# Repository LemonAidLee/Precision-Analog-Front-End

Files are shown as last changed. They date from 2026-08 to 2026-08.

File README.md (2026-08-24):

# Precision Mixed-Signal Data Acquisition Front End (AFE)

A four-stage precision analog front end that conditions a ±100 mV bipolar sensor signal into the 0–3.3 V unipolar window of a 16-bit ADS1115 ADC, designed for an ESP32-WROOM-32 host. Designed, simulated in LTspice, and laid out in KiCad. **Not built — no physical hardware exists.**

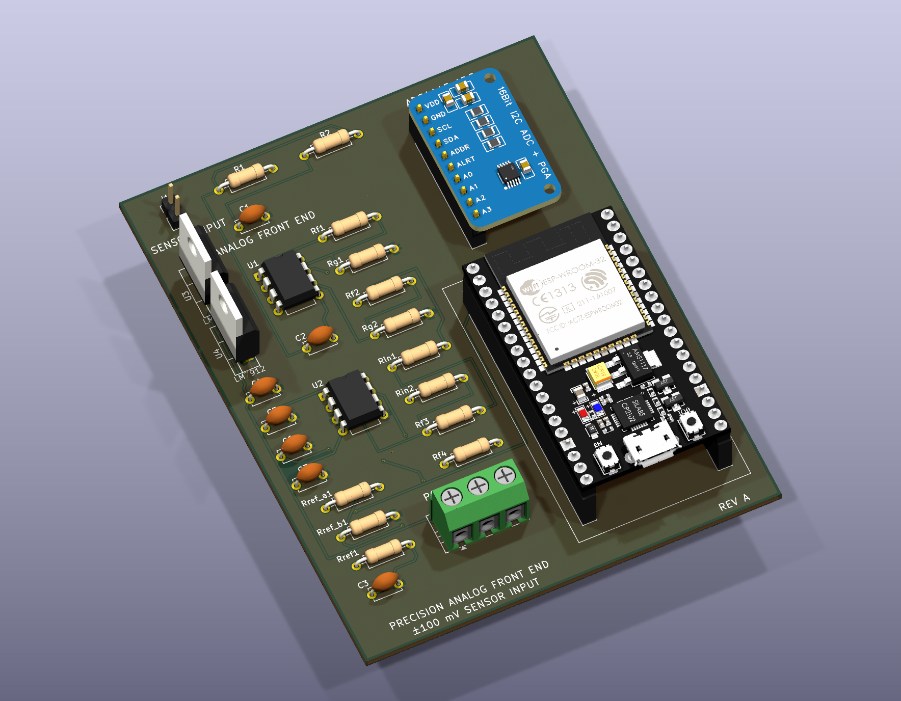
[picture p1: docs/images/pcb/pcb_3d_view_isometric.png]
PCB 3D render, top view


*Rev A board (78 mm × 100 mm, 2-layer), KiCad 3D render. The physical board has not been manufactured.*

---

## Overview

A sensor that outputs a few tens of millivolts, swinging both positive and negative, cannot be connected to a single-supply ADC. It is too small to use the converter's resolution, it goes below the converter's ground rail, and it carries out-of-band content the converter will alias.

This project is the hardware that sits between the two: an analog front end that band-limits, amplifies, and re-centres the signal so that a 16-bit ADC sees a well-conditioned, in-range voltage, and an ESP32 can read it over I²C.

| | |
|---|---|
| **Input** | ±100 mV bipolar, single-ended (J1) |
| **Output** | 0.31 V … 2.96 V unipolar, centred on VREF (to ADS1115 A0) |
| **Overall gain** | 13.25 V/V (22.4 dB) |
| **Bandwidth** | 2nd-order Butterworth low-pass, f₀ = 1.06 kHz |
| **Analog supply** | ±15 V (unregulated), external via screw terminal (J2); regulated on-board to ±12 V by LM7812 / LM7912 |
| **Digital supply** | 3.3 V from the ESP32 module's on-board regulator |
| **Op-amps** | 2 × TL082 (dual JFET-input), DIP-8 |
| **ADC** | ADS1115 breakout, 16-bit, I²C, ±4.096 V FSR |
| **Board** | 78 mm × 100 mm, 2-layer, 1.6 mm, all through-hole |
| **Status** | Designed · Simulated (DC) · Schematic complete · PCB fully routed with GND pour |

---

## Engineering motivation

Connecting a low-level sensor directly to a microcontroller ADC fails for four independent reasons, and each one needs its own circuit stage:

| Problem | Consequence | Stage that solves it |
|---|---|---|
| Signal is out-of-band above ~1 kHz | High-frequency interference folds back into the measurement band | Stage 1 — Sallen-Key low-pass |
| Signal is ~100 mV into a 4.096 V converter span | Only ~2.4 % of the ADC range is used; quantisation noise dominates | Stage 2 — ×10 gain |
| Signal is bipolar; the ADC ground rail is 0 V | Negative half-cycles are clipped or damage the input | Stage 3 — inverting summing level shift onto VREF |
| The summing stage inverts the signal | Polarity is wrong at the ADC | Stage 4 — unity-gain inverter |

Doing all four in one stage is possible but couples the design decisions together — the gain would set the filter Q, the offset would move with gain, and nothing could be probed independently. Splitting them keeps every design equation independent and gives four testable nodes.

---

## Signal flow

```
                 ±100 mV                  ±159 mV               ±1.59 V
   SENSOR ──▶ ┌───────────┐  VFILTER  ┌───────────┐  VAMP  ┌──────────────┐
   J1         │  STAGE 1  │ ────────▶ │  STAGE 2  │ ─────▶ │   STAGE 3    │
              │ Sallen-Key│           │ Non-inv.  │        │  Inverting   │
              │  LPF ×1.59│           │  amp ×10  │        │  summer      │
              │  U1A      │           │  U1B      │        │  U2A         │
              └───────────┘           └───────────┘        └──────┬───────┘
                                                                  │ VX
                        +3.3 V                                    │ −2.96 … −0.31 V
                          │                                       ▼
                     ┌────┴────┐  VREF = 1.637 V           ┌──────────────┐
                     │ 470/470 │ ─────────────────────────▶│   STAGE 4    │
                     │ divider │                           │ Unity inv.   │
                     │ + 100 nF│                           │  U2B         │
                     └─────────┘                           └──────┬───────┘
                                                                  │ VADC
                                                                  │ 0.31 … 2.96 V
                                                                  ▼
                                                        ┌────────────────────┐
                                                        │ ADS1115  (A0)      │
                                                        │ 16-bit, ±4.096 V   │
                                                        └─────────┬──────────┘
                                                                  │ I²C (SDA/SCL)
                                                                  ▼
                                                        ┌────────────────────┐
                                                        │ ESP32-WROOM-32     │
                                                        └────────────────────┘
```

Full node-by-node breakdown: **[03 — Signal Path](docs/03_Signal_Path.md)**

---

## Key specifications

| Parameter | Design value | Source |
|---|---|---|
| Input range | ±100 mV | Design target (silkscreened on board) |
| Stage 1 passband gain, K | 1 + 5.9k/10k = **1.590** | Calculated, LTspice-confirmed |
| Stage 1 cutoff, f₀ | 1/(2π·1.5k·100n) = **1061 Hz** | Calculated |
| Stage 1 Q | 1/(3 − K) = **0.709** (Butterworth ≈ 0.707) | Calculated |
| Stage 2 gain | 1 + 90k/10k = **10.00** | Calculated, LTspice-confirmed |
| Stage 3 signal gain | −30k/36k = **−0.8333** | Calculated, LTspice-confirmed |
| Stage 3 reference gain | −30k/30k = **−1.000** | Calculated |
| Stage 4 gain | −10k/10k = **−1.000** | Calculated |
| **Total gain, VSENSOR → VADC** | **13.25 V/V** | LTspice: 13.248 V/V |
| VREF (unloaded) | 3.3 × 470/940 = **1.650 V** | Calculated |
| VREF (loaded by Rref1) | **1.637 V** | LTspice: 1.6372 V |
| VADC at −100 mV / 0 / +100 mV | 0.313 / 1.637 / 2.962 V | LTspice (TL082) |
| ADC resolution referred to input | 4.096 V / 2¹⁵ / 13.25 = **9.4 µV/LSB** | Calculated |

---

## Hardware architecture

**Analog section** (left half of the board) — two TL082 dual op-amps in DIP-8 provide the four amplifier stages. All resistors are 1/4 W axial through-hole on a 10.16 mm pitch, arranged in a single labelled column so every feedback network can be identified and swapped without a schematic in hand. Analog supplies enter on a 3-pin 5 mm screw terminal (+15V_RAW / GND / −15V_RAW) from an external bench supply; on-board **LM7812 / LM7912 linear regulators** (U3/U4, with C4–C7 input/output bypass) clean this to the ±12 V the op-amps actually run on. The raw rail needs headroom above 12 V for the regulators to hold regulation, which is why the connector is no longer labelled ±12 V directly.

**Digital section** (right half) — the ESP32 dev board seats in two 1×19 pin sockets and supplies 3.3 V from its own regulator; the ADS1115 breakout seats in a 1×10 socket above it. The two sections meet only at the VADC trace and the shared ground.

Details: **[07 — KiCad Schematic and PCB](docs/07_KiCad_Schematic_and_PCB.md)**

---

## Simulation

Design verification was done in LTspice in two phases.

**Phase 1 — stage development with OP1177.** Each stage was designed, simulated, and iterated on its own bench: the Sallen-Key filter (AC sweep + transient), the ×10 gain stage (AC + transient), the level shifter, and then a two-stage and finally a four-stage integration. This phase used the OP1177 model that ships with LTspice, and produced the resistor values now in the schematic.

**Phase 2 — TL082 substitution.** The physical build targets TL082, so a third-party TL082 PSpice macromodel (`TL082.lib`) was brought in and the full chain re-run against it. The DC transfer at −100 mV / 0 / +100 mV was extracted and matches the ideal transfer function to within 0.02 %.

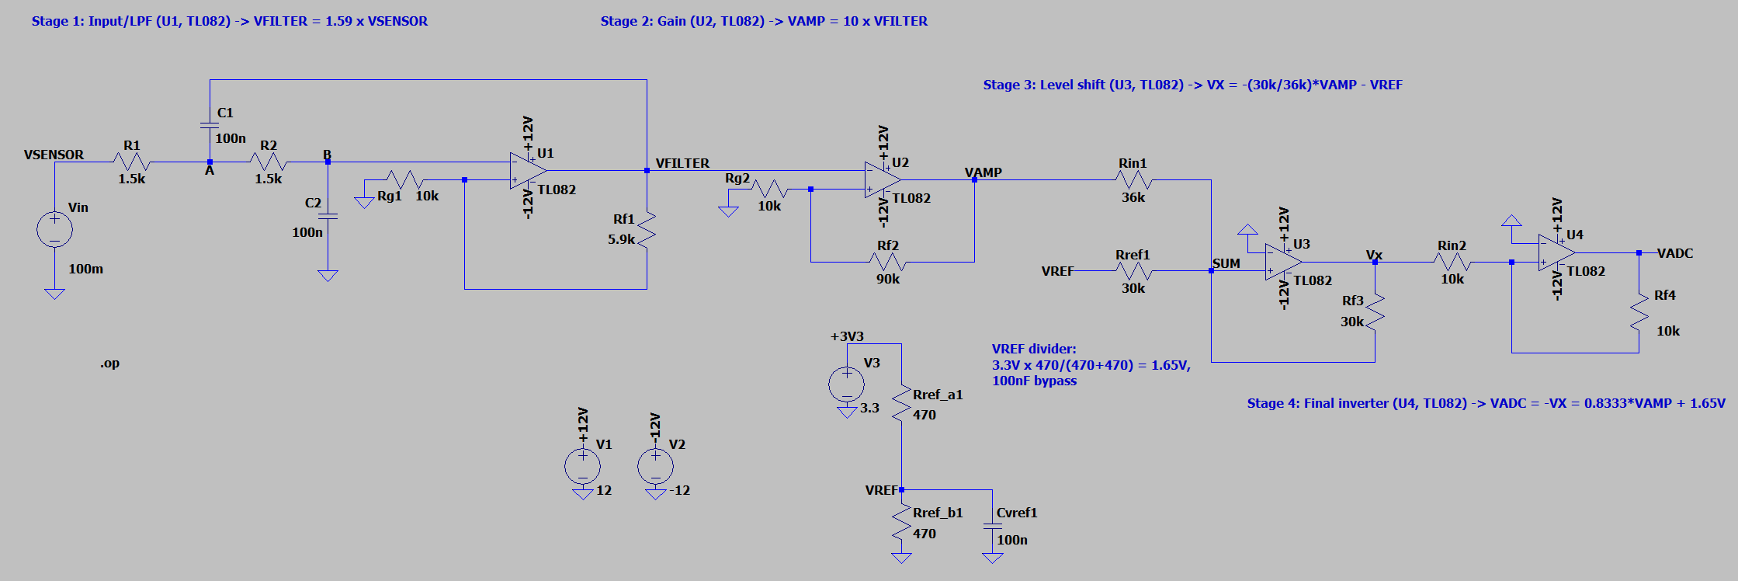
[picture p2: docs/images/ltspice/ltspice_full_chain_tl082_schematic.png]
LTspice full chain, TL082


*Four-stage chain as simulated with the TL082 macromodel.*

| Test condition | Ideal (calculated) | LTspice, TL082 | Δ |
|---|---:|---:|---:|
| VSENSOR = 0 | 1.637 V | 1.63737 V | +0.4 mV |
| VSENSOR = +100 mV | 2.962 V | 2.96220 V | +0.2 mV |
| VSENSOR = −100 mV | 0.313 V | 0.31254 V | −0.2 mV |

**Two simulation issues are open and are not hidden here:** the TL082 build's filter section is wired as a passive two-pole RC rather than the Sallen-Key that is in the KiCad schematic (DC results unaffected, AC results not representative), and the OP1177 reference file no longer runs. Both are documented in **[05 — LTspice Simulation](docs/05_LTspice_Simulation.md)**.

Full detail: **[05 — LTspice Simulation](docs/05_LTspice_Simulation.md)** · **[06 — Simulation Results](docs/06_Simulation_Results.md)**

---

## PCB design

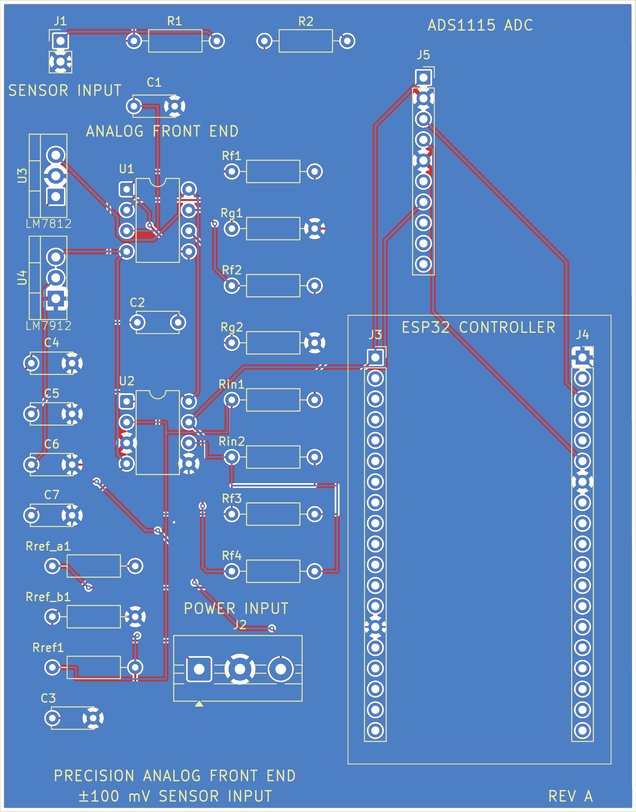
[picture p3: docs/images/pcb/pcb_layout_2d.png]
PCB layout, 2D


*F.Cu (red), B.Cu (blue — mostly the GND pour), silkscreen and board outline. Fully routed.*

- **78.1 mm × 99.6 mm** bounding box (2 layers, 1.6 mm FR4)
- 29 footprints, all through-hole; 115 pads
- 209 track segments (112 on F.Cu, 97 on B.Cu), ≈1355 mm total; 10 vias (0.6 mm / 0.3 mm drill)
- **GND poured on both F.Cu and B.Cu** (2 zones, 0.25 mm min thickness)
- Design rules: 0.2 mm min clearance, 0.2 mm min track, 0.5 mm copper-to-edge
- **DRC: 0 violations.** **ERC: 0 errors, 32 warnings** (all "label connected to only one pin" — the unused ESP32 GPIO breakout labels)
- No test points; no local decoupling at the op-amp supply pins

**Routing is complete.** Every net — including the seven internal analog nodes (the two filter nodes and the five op-amp inverting-input/feedback nodes) that an earlier netlist-sync bug had left with no copper — now has a fully routed connection, plus a GND pour on both layers. See **[07 — KiCad Schematic and PCB](docs/07_KiCad_Schematic_and_PCB.md)** for the routing table and the story of that bug.

---

## ESP32 + ADS1115 interface

The digital side is a **hardware interface only — no firmware has been written.**

| ADS1115 (J5) | Net | Goes to |
|---|---|---|
| 1 VDD | +3V3 | J3-1 (ESP32 3V3) |
| 2 GND | GND | Board ground |
| 3 SCL | SCL | J4-3 (ESP32 GPIO22) |
| 4 SDA | SDA | J4-6 (ESP32 GPIO21) |
| 5 ADDR | GND | Sets I²C address 0x48 |
| 6 ALRT | — | Not connected |
| 7 A0 | **VADC** | Stage 4 output |
| 8–10 A1–A3 | — | Not connected |

Details: **[09 — ESP32 + ADS1115 Interface](docs/09_ESP32_ADS1115_Interface.md)**

---

## Verification status

| Item | Designed | Simulated | On PCB | Routed | Physically tested |
|---|:--:|:--:|:--:|:--:|:--:|
| Sallen-Key low-pass (U1A) | ✓ | ✓ (AC/transient, OP1177 · DC only, TL082) | ✓ | ✓ | — |
| ×10 gain stage (U1B) | ✓ | ✓ (AC/transient, OP1177 · DC, TL082) | ✓ | ✓ | — |
| Level shifter (U2A) | ✓ | ✓ (DC, TL082) | ✓ | ✓ | — |
| Unity inverter (U2B) | ✓ | ✓ (DC, TL082) | ✓ | ✓ | — |
| 1.65 V reference divider | ✓ | ✓ (DC, TL082, incl. loading) | ✓ | ✓ | — |
| ADS1115 interface | ✓ | — | ✓ | ✓ | — |
| ESP32 interface | ✓ | — | ✓ | ✓ | — |
| ±12 V regulation (LM7812/LM7912) | ✓ | ideal sources only in signal-chain sims | ✓ | ✓ | — |
| Firmware | — | — | — | — | — |

**No physical prototype exists.** The board has not been fabricated, assembled, powered, or measured. Every performance figure in this repository is either a hand calculation or an LTspice result. Physical hardware validation is outside the current project scope.

---

## Engineering challenges

- **Choosing K = 1.59 rather than "gain = 1".** In an equal-component Sallen-Key, the passband gain and the pole Q are the same knob: Q = 1/(3 − K). A unity-gain buffer would give Q = 0.5 (overdamped, soft knee). K = 1.586 is the value that lands Q on 0.7071 — maximally flat. The 5.9 kΩ / 10 kΩ pair gives K = 1.590 and Q = 0.709, 0.3 % from ideal, using stock values.
- **Sizing the level shifter so the extremes stay inside the rail, not just the centre.** An earlier iteration used Rin1 = 20 kΩ. That still centred on 1.65 V at zero input, but the ±100 mV extremes landed at −0.74 V and +4.03 V — outside the ADC's supply rails in both directions. Rin1 = 36 kΩ trades gain for headroom and puts the extremes at 0.31 V / 2.96 V.
- **Predicting the reference divider's error before simulating it.** VREF is not 1.650 V in circuit; Rref1 (30 kΩ) sinks ~55 µA from a 235 Ω source, pulling it to 1.637 V. That 13 mV shift is a fixed offset the firmware can calibrate out — but it had to be identified as a systematic error rather than mistaken for simulation noise.
- **Migrating from a model that exists to a part that can be bought.** OP1177 has a vendor-supplied LTspice model; TL082 does not ship with LTspice. Getting the TL082 macromodel to converge required source stepping, and re-running the chain surfaced the fact that the two integration files had drifted apart.

---

## Current project status

**Designed · Simulated · Schematic complete · PCB placed and fully routed with a GND pour · Documented.**

Not manufactured, not assembled, not physically validated, not production-ready.

---

## Limitations

- No physical prototype; no oscilloscope, multimeter, or spectrum measurements of any kind.
- No local supply decoupling at the TL082 pins, no test points on the current board.
- ±12 V is regulated on-board (LM7812/LM7912), but the input rail is still an external, unregulated ±15 V supply — there is no AC-mains or USB-derived path to that rail.
- The TL082 full-chain simulation covers **DC only**; there is no AC or transient run against the TL082 model, and its filter section does not match the board.
- The AC and transient results in this repository were produced with **OP1177**, not the TL082 that is on the schematic.
- The 1.06 kHz filter corner sits above the ADS1115's 430 Hz Nyquist frequency at its 860 SPS maximum rate — it band-limits the signal but does not anti-alias the converter.
- No input protection, no reverse-polarity protection, no sensor characterisation.
- No firmware.

---

## Future improvements

1. Resolve the two open simulation discrepancies (filter topology in the TL082 file; repair the OP1177 reference bench).
2. Run AC and transient sweeps against the TL082 model and compare to the OP1177 reference.
3. Add 100 nF decoupling at each TL082 supply pin, and test points at VSENSOR / VFILTER / VAMP / VREF / VADC.
4. Fabricate and assemble; bring up the rails before the signal chain.
5. Measure DC transfer, frequency response, and noise floor; compare against simulation.
6. Write ESP32 firmware: I²C driver for the ADS1115, offset/gain calibration, data logging.
7. Revise to Rev B against measured data.

**Done since the last revision of this document:** PCB routing is complete (including seven internal analog nets a netlist-sync bug had silently left unrouted — see [07 §5](docs/07_KiCad_Schematic_and_PCB.md#5-resolution--the-unrouted-nets-and-the-bug-behind-them)), a GND pour was added on both copper layers, and on-board LM7812/LM7912 regulation replaced the external-±12V-only supply architecture.

---

## Repository structure

```
.
├── README.md                     ← this file
├── docs/                         ← full engineering documentation
│   ├── README.md                 ← documentation index
│   ├── 01_Project_Overview.md
│   ├── 02_System_Architecture.md
│   ├── 03_Signal_Path.md
│   ├── 04_Analog_Circuit_Design.md
│   ├── 05_LTspice_Simulation.md
│   ├── 06_Simulation_Results.md
│   ├── 07_KiCad_Schematic_and_PCB.md
│   ├── 08_Components_and_BOM.md
│   ├── 09_ESP32_ADS1115_Interface.md
│   ├── 10_Engineering_Decision.md
│   ├── Portfolio_Summary.md      ← recruiter-facing summary
│   ├── images/                   ← schematic, PCB and LTspice figures
│   └── design_files/             ← generated PDF / BOM exports + source pointers
├── KiCAD_PCB_Design/             ← KiCad 10 project (schematic, PCB, STEP)
├── LTSpice_Simulation/           ← LTspice schematics, netlists, TL082 model
└── Precision DAQ AFE_Documentation/   ← original engineering log / working notes
```

---

## Skills demonstrated

**Analog design** — active filter synthesis (Sallen-Key, Butterworth Q targeting), op-amp gain-stage design, inverting summing amplifiers, level shifting, resistive reference design with loading analysis, supply-rail headroom budgeting.

**Simulation** — LTspice AC / transient / DC-sweep analysis, third-party SPICE macromodel integration, convergence troubleshooting (Gmin and source stepping), model-substitution verification, netlist-level inspection.

**PCB design** — KiCad 10 schematic capture, footprint assignment, through-hole layout, functional block placement, analog/digital section separation, DRC/ERC.

**Mixed-signal / embedded** — external ADC selection and interfacing, I²C bus wiring, ADS1115 address strapping and PGA range selection, ESP32 dev-board integration.

**Engineering process** — requirement-driven stage decomposition, quantitative trade-off analysis, iterative design revision with superseded values preserved, honest separation of calculated / simulated / measured, self-audit of design-file consistency.

---

## Documentation

Start at **[docs/README.md](docs/README.md)** for the full index.

- **[docs/01–09](docs/README.md)** — the technical documentation: overview, architecture, signal path, circuit design, simulation, PCB, BOM, and the ESP32/ADS1115 interface.
- **[docs/10_Engineering_Decision.md](docs/10_Engineering_Decision.md)** — every significant design choice, the alternative it was taken over, and the reasoning.
- **[docs/Portfolio_Summary.md](docs/Portfolio_Summary.md)** — a short, recruiter-facing summary of the same project.

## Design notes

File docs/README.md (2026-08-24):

# Documentation Index

Engineering documentation for the **Precision Mixed-Signal Data Acquisition Front End (AFE)**.

The repository landing page is **[../README.md](../README.md)**. This index is the entry point to the detailed technical documents.

Documents **01–10** and the **[Portfolio Summary](Portfolio_Summary.md)** form the comprehensive documentation suite. They detail the system architecture, component selection, simulation verification, and PCB layout that comprise the complete AFE design.

Every document here accurately reflects the current state of the design files. Calculations are explicitly shown, and simulation results directly reference the corresponding LTspice files. 

---

## Contents

| # | Document | What it covers |
|---|---|---|
| 01 | [Project Overview](01_Project_Overview.md) | The measurement problem, the engineering solution, and the resulting signal-conditioning architecture |
| 02 | [System Architecture](02_System_Architecture.md) | Block diagram, block-by-block contributions, power distribution, and grounding strategy |
| 03 | [Signal Path](03_Signal_Path.md) | Node-by-node walkthrough: VSENSOR → A → B → VFILTER → VAMP → VX → VADC |
| 04 | [Analog Circuit Design](04_Analog_Circuit_Design.md) | Per-stage topology, equations, component values, gain and headroom budgets |
| 05 | [LTspice Simulation](05_LTspice_Simulation.md) | Simulation strategy, file inventory, and TL082 macromodel integration |
| 06 | [Simulation Results](06_Simulation_Results.md) | Result tables, waveforms, and the electrical behavior established by simulation |
| 07 | [KiCad Schematic and PCB](07_KiCad_Schematic_and_PCB.md) | Schematic capture, board dimensions, layout rationale, and routing strategy |
| 08 | [Components and BOM](08_Components_and_BOM.md) | Comprehensive BOM by functional group, footprints, and selection criteria |
| 09 | [ESP32 + ADS1115 Interface](09_ESP32_ADS1115_Interface.md) | Connector pinouts, I²C integration, and ADC configuration |
| 10 | [Engineering Decision](10_Engineering_Decision.md) | Key architectural choices, alternatives considered, and quantitative reasoning |
| — | [Portfolio Summary](Portfolio_Summary.md) | High-level engineering overview and skills mapping |

> A further working document, `11_Engineering_Review.md`, is kept alongside this set in the project's local working copy. It consolidates the verification matrix and design-file consistency audit. It serves as an ongoing development log.

---

## Reference figures

**Schematic**
- [`images/schematic/schematic_full.svg`](images/schematic/schematic_full.svg) — complete Rev A schematic

**PCB**
- [`images/pcb/pcb_3d_view_isometric.png`](images/pcb/pcb_3d_view_isometric.png) — 3D render, isometric
- [`images/pcb/pcb_3d_view_top.png`](images/pcb/pcb_3d_view_top.png) — 3D render, top-down
- [`images/pcb/pcb_layout_2d.png`](images/pcb/pcb_layout_2d.png) — copper + silkscreen + outline
- [`images/pcb/pcb_layout_all_layers.svg`](images/pcb/pcb_layout_all_layers.svg) — vector, all plotted layers
- [`images/pcb/pcb_copper_top.svg`](images/pcb/pcb_copper_top.svg) / [`pcb_copper_bottom.svg`](images/pcb/pcb_copper_bottom.svg) — per-layer copper

**LTspice** — [`images/ltspice/`](images/ltspice/) holds figures that reflect the current design; [`images/ltspice/archive/`](images/ltspice/archive/) holds figures from superseded iterations, preserving the development history.

---

## Design files

Source files are **not duplicated** into `docs/`. They live in their working directories so the KiCad and LTspice projects stay intact:

| Domain | Location |
|---|---|
| KiCad 10 project | [`../KiCAD_PCB_Design/`](../KiCAD_PCB_Design/) |
| LTspice schematics, netlists, TL082 model | [`../LTSpice_Simulation/`](../LTSpice_Simulation/) |
| Original engineering log / working notes | [`../Precision DAQ AFE_Documentation/`](../Precision%20DAQ%20AFE_Documentation/) |

Generated exports (schematic PDF, PCB layout PDF, BOM CSV) are in [`design_files/`](design_files/) — see [`design_files/README.md`](design_files/README.md).

---

## How to read this if you have five minutes

1. [../README.md](../README.md) — what the project is and the current development status
2. [03 — Signal Path](03_Signal_Path.md) — how a signal actually moves through the AFE
3. [10 — Engineering Decision](10_Engineering_Decision.md) — why the circuit is structured the way it is

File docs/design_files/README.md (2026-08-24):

# Design Files

[← Documentation index](../README.md)

---

## Source files — not duplicated here

The KiCad and LTspice projects are **not copied into `docs/`**. Duplicating them would create two versions of the truth and break KiCad's internal project references. They live in their working directories:

| Domain | Location | Contents |
|---|---|---|
| **KiCad 10** | [`../../KiCAD_PCB_Design/`](../../KiCAD_PCB_Design/) | `Precision_AFE_ESP32.kicad_pro` · `.kicad_sch` · `.kicad_pcb` · `.step` · `Precision_AFE_ESP32_drc_violations.json` |
| **LTspice** | [`../../LTSpice_Simulation/`](../../LTSpice_Simulation/) | `AFE_Integration_TL082.asc` / `.net` (current) · `TL082.lib` (model) · stage-development `.asc` files · `.raw` / `.log` results |
| **Engineering log** | [`../../Precision%20DAQ%20AFE_Documentation/`](../../Precision%20DAQ%20AFE_Documentation/) | Original working notes and the LTspice screenshot library |

> **Note on the engineering log:** `AFE_FINAL_KiCad_Reference.md` and `AFE_Master_Engineering_Documentation.md` were written during the design phase and are now out of date on several points (board size, TL082 verification status, reference circuit, power architecture, test points). They remain useful as a record of how the design was reasoned through. **`docs/` is the current description of the design.**

---

## Generated exports — in this directory

Produced with `kicad-cli` 10.0.5 from the current design files.

| File | What it is |
|---|---|
| `Precision_AFE_ESP32_schematic.pdf` | Complete Rev A schematic, A4, with title block |
| `Precision_AFE_ESP32_pcb_layout.pdf` | PCB layout — F.Cu, B.Cu, F.SilkS, Edge.Cuts |
| `Precision_AFE_ESP32_bom.csv` | Bill of materials, grouped by value and footprint |

---

## Not generated: fabrication output

**No Gerbers, drill files, or pick-and-place files exist yet.**

That used to be because seven nets on the board carried no copper — generating a fabrication package from a half-routed board would have produced an artefact that looked like a manufacturing release and was not one. That blocker is gone: routing is now complete (see [07 §5](../07_KiCad_Schematic_and_PCB.md#5-resolution--the-unrouted-nets-and-the-bug-behind-them)) and DRC is clean against a meaningful, fully-populated ratsnest. Gerbers simply haven't been generated yet — nothing about the current design file precludes it, but it remains a deliberate step for whoever decides this design is ready for a manufacturing release, not something to produce automatically alongside a documentation update.

---

## Which files are current

There is no ambiguity about versions:

| Concern | Answer |
|---|---|
| `KiCAD_PCB_Design/.history/` | KiCad's own Local History snapshot. **Byte-identical** to the top-level files — verified by diff. Not an older version. |
| `KiCAD_PCB_Design/.mcp-backups/` | Timestamped tool backups of the `.kicad_pcb`. Superseded. |
| `LTSpice_Simulation/*.asc` | Multiple files, all legitimate — one bench per design stage. `AFE_Integration_TL082.asc` is the current full-chain build; the rest are stage-development benches. See [05 §2](../05_LTspice_Simulation.md#2-file-inventory) for the full inventory with status. |
| `Draft2.*`, `AFE_SallenKey_OP1177.*` | Orphaned result files with no surviving `.asc`. Not cited anywhere. |

---

## Reproducing the exports

```bash
# Schematic PDF
kicad-cli sch export pdf \
  --output docs/design_files/Precision_AFE_ESP32_schematic.pdf \
  KiCAD_PCB_Design/Precision_AFE_ESP32.kicad_sch

# Schematic SVG (used in the documentation)
kicad-cli sch export svg \
  --output docs/images/schematic --exclude-drawing-sheet \
  KiCAD_PCB_Design/Precision_AFE_ESP32.kicad_sch

# PCB layout PDF
kicad-cli pcb export pdf \
  --output docs/design_files/Precision_AFE_ESP32_pcb_layout.pdf \
  --layers "F.Cu,B.Cu,F.SilkS,Edge.Cuts" --mode-single \
  KiCAD_PCB_Design/Precision_AFE_ESP32.kicad_pcb

# 3D renders
kicad-cli pcb render --output docs/images/pcb/pcb_3d_view_top.png \
  --width 1800 --height 1400 --side top --quality high \
  --background opaque --perspective --zoom 0.9 \
  KiCAD_PCB_Design/Precision_AFE_ESP32.kicad_pcb

kicad-cli pcb render --output docs/images/pcb/pcb_3d_view_isometric.png \
  --width 1800 --height 1400 --rotate "-30,0,25" --quality high \
  --background opaque --floor --zoom 0.85 \
  KiCAD_PCB_Design/Precision_AFE_ESP32.kicad_pcb

# BOM
kicad-cli sch export bom \
  --output docs/design_files/Precision_AFE_ESP32_bom.csv \
  --fields "Reference,Value,Footprint,\${QUANTITY}" \
  --group-by "Value,Footprint" \
  KiCAD_PCB_Design/Precision_AFE_ESP32.kicad_sch
```

---

## Running the simulation

Open `LTSpice_Simulation/AFE_Integration_TL082.asc` in LTspice 24.x and run.

> ⚠️ The `.lib` directive on that schematic uses an **absolute Windows path** to `TL082.lib`. On any other machine, or after moving the project, change it to a bare `TL082.lib` — the model file sits in the same directory.

> ⚠️ That file's filter section does not match the KiCad schematic — both capacitors return to ground, making it a passive 2-pole RC rather than a Sallen-Key. **DC results are unaffected**; AC and transient results from it would not represent the board. See [05 — LTspice Simulation §5](../05_LTspice_Simulation.md#5-open-issue--filter-topology-in-the-tl082-build).

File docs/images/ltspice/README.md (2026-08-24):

# LTspice Figures

[← Documentation index](../../README.md)

Screenshots captured from LTspice during design and verification. Originals live in [`../../../Precision%20DAQ%20AFE_Documentation/LTSpice%20Simulation%20Image/`](../../../Precision%20DAQ%20AFE_Documentation/) under their original names; the copies here have been renamed to describe their contents and to be filesystem- and URL-safe.

**Current design point:** R1 = R2 = 1.5 kΩ, Rin1 = 36 kΩ, TL082.

---

## Figures reflecting the current design

| File | Contents | Design point |
|---|---|---|
| `ltspice_full_chain_tl082_schematic.png` | Four-stage chain drawn with TL082 and the real 470/470 reference divider, with stage annotations | R = 1.5 kΩ, Rin1 = 36 kΩ, TL082 |
| `ltspice_full_chain_op1177_reference_schematic.png` | The same four-stage chain drawn with OP1177 and an ideal 1.65 V source — the reference bench | R = 1.5 kΩ, Rin1 = 36 kΩ, OP1177 |

> The circuit in `ltspice_full_chain_op1177_reference_schematic.png` corresponds to `AFE_IntegrationComplete.asc`, which **no longer runs** in its saved state.

## Filter characterisation *(R = 1.6 kΩ — one design point behind the board)*

| File | Contents |
|---|---|
| `ltspice_sallenkey_bode_response.png` | Magnitude and phase, 10 Hz – 100 kHz. Passband +4.03 dB, corner ≈ 998 Hz, 40 dB/decade roll-off |
| `ltspice_sallenkey_transient_100hz.png` | 100 Hz: 1 V in → 1.59 V out, in phase (deep in the passband) |
| `ltspice_sallenkey_transient_1khz.png` | 1 kHz: 1 V in → 1.13 V out with visible phase lag (at the corner) |
| `ltspice_sallenkey_transient_10khz.png` | 10 kHz: heavy attenuation (a decade above the corner) |

## Gain stage

| File | Contents |
|---|---|
| `ltspice_gain_stage_schematic.png` | Non-inverting ×10: Rf = 90 kΩ, Rg = 10 kΩ, ±12 V, OP1177 |
| `ltspice_gain_stage_ac_response.png` | AC response: 20 dB flat through 10 kHz, corner ≈ 100 kHz |
| `ltspice_gain_stage_transient_100hz.png` | 100 Hz: 100 mV in → 1.0 V out |
| `ltspice_gain_stage_transient_1khz.png` | 1 kHz: 100 mV in → 1.0 V out |

## Filter + gain cascade *(R = 1.6 kΩ)*

VSENSOR (green) / VFILTER (blue) / VAMP (red) on one plot:

| File | Excitation | VFILTER | VAMP |
|---|---|---|---|
| `ltspice_filter_gain_chain_transient_100hz.png` | 100 mV, 100 Hz | 159 mV | 1.59 V |
| `ltspice_filter_gain_chain_transient_500hz.png` | 100 mV, 500 Hz | 154 mV | 1.54 V |
| `ltspice_filter_gain_chain_transient_1khz.png` | 100 mV, 1 kHz | 113 mV | 1.13 V |
| `ltspice_filter_gain_chain_transient_10khz.png` | 100 mV, 10 kHz | 1.5 mV | 15 mV |

Each of these agrees with the independently-run AC sweep to three significant figures.

---

## Archive

[`archive/`](archive/) holds figures from **superseded design points**. They are kept for traceability of how the design evolved, and every filename carries the design point it belongs to. Do not quote numbers from them as current.

| File | Why it is archived |
|---|---|
| `ltspice_sallenkey_ac_testbench_r1k6.png` | Filter AC test bench schematic at R = 1.6 kΩ (board uses 1.5 kΩ) |
| `ltspice_sallenkey_transient_testbench_r1k6.png` | Filter transient test bench schematic at R = 1.6 kΩ |
| `ltspice_level_shifter_testbench_rin20k.png` | Level-shifter bench with **Rin = 20 kΩ** — the rejected design point (gain 1.5) |
| `ltspice_level_shifter_transient_rin20k.png` | Its waveform: ±1 V in → 0.15…3.15 V out. Demonstrates the *principle* correctly; the numbers do not apply to the current 36 kΩ design |
| `ltspice_full_chain_op1177_earlier_r1k6_rin20k.png` | Earlier four-stage chain at R = 1.6 kΩ **and** Rin1 = 20 kΩ — two design points behind |

---

## Name mapping

| Original filename | Renamed to |
|---|---|
| `AFE_TL082_FinalIntegradedCircuit.png` | `ltspice_full_chain_tl082_schematic.png` |
| `AFE_FinalCompleteCircuit_AllValuesFinalized.png` | `ltspice_full_chain_op1177_reference_schematic.png` |
| `Integration_Finalized.png` | *(byte-identical duplicate of the above — not copied)* |
| `BodePlot.png` | `ltspice_sallenkey_bode_response.png` |
| `Transient_100Hz.png` / `_1kHz` / `_10kHz` | `ltspice_sallenkey_transient_100hz.png` / `_1khz` / `_10khz` |
| `AFE_Amplifier_Topology.png` | `ltspice_gain_stage_schematic.png` |
| `Amplifie_AcGain&Bandwidth.png` | `ltspice_gain_stage_ac_response.png` |
| `Amplifier_100Hz.png` / `Amplifier_1kHz.png` | `ltspice_gain_stage_transient_100hz.png` / `_1khz` |
| `Integration_100Hz.png` / `_500Hz` / `_1kHz` / `_10kHz` | `ltspice_filter_gain_chain_transient_100hz.png` / `_500hz` / `_1khz` / `_10khz` |
| `AFE_SallenKey_OP1177_BodePlotAnalysis.png` | `archive/ltspice_sallenkey_ac_testbench_r1k6.png` |
| `AFE_SallenKey_OP1177_TransientAnalysis.png` | `archive/ltspice_sallenkey_transient_testbench_r1k6.png` |
| `AFE_LevelShifter_Circuit.png` | `archive/ltspice_level_shifter_testbench_rin20k.png` |
| `TransferEquation_Waveform.png` | `archive/ltspice_level_shifter_transient_rin20k.png` |
| `AFE_CompleteIntegratedCircuit.png` | `archive/ltspice_full_chain_op1177_earlier_r1k6_rin20k.png` |

Two original names carried errors that the renaming corrects: `FinalIntegradedCircuit` (typo) and `Amplifie_AcGain&Bandwidth` (typo, plus an `&` that is awkward in URLs and shells). The two `..._BodePlotAnalysis` / `..._TransientAnalysis` names described *plots* but the files are *schematics* — the new names say which.

**The original files were not modified, renamed, or deleted.** These are copies.

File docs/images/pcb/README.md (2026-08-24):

# PCB and Schematic Figures

[← Documentation index](../../README.md)

All figures generated with `kicad-cli` 10.0.5 from `KiCAD_PCB_Design/Precision_AFE_ESP32.kicad_pcb` / `.kicad_sch` as they exist on disk. Commands are listed in [`../../design_files/README.md`](../../design_files/README.md).

**These are renders and plots of a design file. No physical board exists.**

---

## PCB

| File | Contents |
|---|---|
| `pcb_3d_view_isometric.png` | 3D render, isometric, with component models — including the ESP32 DevKit and ADS1115 breakout as they would seat in their sockets |
| `pcb_3d_view_top.png` | 3D render, top-down. Best view of the analog/digital split and the silkscreen labelling |
| `pcb_layout_2d.png` | F.Cu (red), B.Cu (blue), F.SilkS and Edge.Cuts, colour plot. Fully routed; the near-solid blue field is the GND pour on B.Cu fusing visually with the B.Cu signal traces it shares a net with |
| `pcb_layout_all_layers.svg` | Same layer set plus B.SilkS/F.Mask/B.Mask, vector |
| `pcb_copper_top.svg` | F.Cu only, with board outline |
| `pcb_copper_bottom.svg` | B.Cu only, mirrored, with board outline |

**Board:** 78.1 mm × 99.6 mm (bounding box) · 2 layers · 1.6 mm · 29 through-hole footprints · 209 track segments · 10 vias · GND copper pour on both layers.

## Schematic

| File | Contents |
|---|---|
| [`../schematic/schematic_full.svg`](../schematic/schematic_full.svg) | Complete Rev A schematic, single A4 sheet, drawing sheet excluded |

A PDF version with the title block is at [`../../design_files/Precision_AFE_ESP32_schematic.pdf`](../../design_files/Precision_AFE_ESP32_schematic.pdf).

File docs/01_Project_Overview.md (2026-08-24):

# 01 — Project Overview

[← Documentation index](README.md)

---

## 1. What I designed

This project presents the design and simulation of a **precision analog front end (AFE)**: the hardware that sits between a low-level analog sensor and a digital measurement system.

Concretely, I developed a complete KiCad Rev A design — encompassing a fully routed 78 mm × 100 mm two-layer PCB with a GND pour on both layers, and a comprehensive set of LTspice models — for a board that:

- accepts a **±100 mV bipolar single-ended sensor signal** on a 2-pin header,
- **band-limits** it with a 2nd-order Butterworth low-pass at 1.06 kHz,
- **amplifies** it by a factor of 10,
- **re-centres** it on a 1.65 V reference so it is unipolar,
- presents the result to a **16-bit ADS1115** ADC on channel A0,
- and connects that ADC to an **ESP32-WROOM-32** dev board over I²C.

The ±100 mV input requirement is silkscreened on the current board (`±100 mV SENSOR INPUT`) and defines the target sweep range evaluated in the LTspice DC analysis.

## 2. The engineering problem

An ADC operates as a comparator against a reference. It measures accurately only when the signal it receives is:

1. **inside** its input range,
2. **filling** a useful fraction of that range,
3. **band-limited** relative to how fast it samples,
4. **low-impedance** enough to charge the converter's sampling capacitor.

A raw sensor output generally satisfies none of these. Take the case this project targets — a sensor producing ±100 mV, fed to an ADS1115 running on 3.3 V with a ±4.096 V full-scale range:

| Property of the raw signal | Consequence at the ADC |
| --- | --- |
| Peak amplitude 100 mV vs. 4.096 V FSR | Uses 2.4 % of the converter's span. The signal is quantised into ~800 of 32 768 available codes; ~5 of the 16 bits do useful work. |
| Swings to −100 mV | Below the converter's negative supply rail. In single-ended mode this half of the waveform is simply lost, and at sufficient amplitude the input protection diodes conduct. |
| Unbounded bandwidth | Any interference above half the sample rate folds down into the measurement band and is indistinguishable from real signal. |
| Source impedance unknown / possibly high | The ADC's switched-capacitor input draws charge in bursts; a high-impedance source cannot settle between them, producing a gain error. |

This analog front end systematically addresses all four limitations before the converter ever sees the signal. By carefully conditioning the input, the architecture ensures that the 16-bit converter delivers its full potential, turning 5 usable bits into an effective 14 bits of resolution.

## 3. What each function contributes

I divided the analog front end into dedicated functional stages, allowing each to be designed and evaluated independently before being integrated into the complete signal chain.

| Function | What it fixes | Implementation strategy |
| --- | --- | --- |
| **Filtering** | Out-of-band content that would alias or add broadband noise | 2nd-order Sallen-Key Butterworth low-pass, f₀ = 1.06 kHz. Positioned before any gain so interference is removed *before* it is multiplied by 10. |
| **Amplification** | Poor use of ADC span; quantisation noise | ×10 non-inverting stage, placed after the filter. |
| **Level shifting** | Bipolar signal vs. unipolar converter | Inverting summing amplifier that adds a 1.65 V reference and scales by 0.833, followed by a unity inverter to restore polarity. |
| **Buffering / low output impedance** | ADC sampling-capacitor settling | The final op-amp stage drives the ADC directly from an op-amp output (≈ ohms), providing the necessary low-impedance source. |
| **Reference generation** | Where the "centre" of the unipolar window comes from | Resistive divider from the same 3.3 V rail that supplies the ADC, so the reference and converter track each other. |

Noise is addressed *architecturally* through these design choices — filtering before gain, keeping the analog and digital halves of the board physically apart, and running the analog stages from clean ±12 V rails.

## 4. Engineering verification strategy

This documentation maintains a strict distinction between design intent and verification methods to ensure credibility and traceability:

| Level | Meaning | Example in this project |
| --- | --- | --- |
| **Design intent** | What the circuit is mathematically designed to do | "f₀ = 1/(2π·1.5 kΩ·100 nF) = 1061 Hz" |
| **Simulation verification** | What the SPICE model establishes | "LTspice, TL082 macromodel, DC sweep: VADC = 2.96220 V at VSENSOR = +100 mV" |
| **Physical validation** | Hardware bench characterization | **Planned for the next development stage.** |

Where a document in this repository states a number, its origin (calculated or simulated) is clearly identified.

## 5. Current status

### Current Development Stage
The current project focuses on circuit development, simulation, PCB implementation, and system architecture. 

- **System architecture**: Complete
- **Analog front-end design**: Complete
- **LTspice simulation**: Complete (DC transfer verified against the TL082 model; AC/transient verified against OP1177)
- **KiCad schematic**: Complete (Rev A)
- **PCB layout**: Complete (including component placement, full routing, and GND copper pour)
- **Power architecture**: Complete (On-board ±12 V linear regulation via LM7812/LM7912 from an external unregulated rail)
- **Digital interface**: Complete (ADS1115 and ESP32 hardware interface definition)
- **Documentation**: Complete

### Future Development
Future development will extend the validated design into physical hardware.

- **Phase 1** — PCB fabrication and assembly
- **Phase 2** — Laboratory characterization and hardware bench measurements
- **Phase 3** — Sensor integration
- **Phase 4** — ESP32 firmware development
- **Phase 5** — Input protection and EMC optimization

**Next:** [02 — System Architecture](02_System_Architecture.md)

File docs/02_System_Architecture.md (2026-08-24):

# 02 — System Architecture

[← Documentation index](README.md)

This document describes the system architecture as captured in the KiCad Rev A design (`KiCAD_PCB_Design/Precision_AFE_ESP32.kicad_sch`).

---

## 1. Block diagram

```
 EXTERNAL                  ANALOG SECTION  (±12 V)                    DIGITAL SECTION  (3.3 V)
 ─────────                 ──────────────────────                     ───────────────────────

 Sensor ──▶ J1 ──▶ ┌──────────────┐    ┌──────────────┐    ┌──────────────┐   ┌──────────────┐
 ±100 mV  SENSOR   │   STAGE 1    │    │   STAGE 2    │    │  STAGE 3+4   │   │   ADS1115    │
          INPUT    │  Sallen-Key  │    │  Non-inv.    │    │ Level shift  │   │  16-bit ADC  │
                   │  LPF, K=1.59 │───▶│  amp, ×10    │───▶│  + inverter  │──▶│  A0, ±4.096V │
                   │  f₀=1.06 kHz │    │              │    │ ×0.833 +VREF │   │   J5 socket  │
                   │  U1A (TL082) │    │  U1B (TL082) │    │ U2A,U2B      │   └──────┬───────┘
                   └──────────────┘    └──────────────┘    └──────▲───────┘          │
                          ▲                    ▲                  │              I²C │
                          │                    │                  │           SDA/SCL│
 Bench ──▶ J2 ────────────┴────────────────────┘           ┌──────┴──────┐           │
 ±12 V   POWER            +12 V / −12 V / GND              │ VREF        │           ▼
         INPUT                                             │ 470Ω/470Ω   │   ┌──────────────┐
                                                           │ + 100 nF    │   │ ESP32-WROOM  │
                                                           │ = 1.637 V   │   │   -32 DevKit │
                                                           └──────▲──────┘   │  J3 + J4     │
                                                                  │          └──────┬───────┘
                                                            +3.3 V│                 │ +3.3 V
                                                                  └─────────────────┘
                                                                          ▲
                                                                          │ USB 5 V
```

**Signal chain, in one line:**

`VSENSOR → [Sallen-Key LPF ×1.59] → VFILTER → [Gain ×10] → VAMP → [Inverting summer ×(−0.833), +VREF] → VX → [Unity inverter] → VADC → ADS1115 A0 → I²C → ESP32`

---

## 2. What each block contributes

### Stage 1 — Sallen-Key low-pass filter (U1A)
**Role: Band limiting and providing initial gain.**

This stage places a 2nd-order maximally-flat (Butterworth) corner at 1.06 kHz so that content above the measurement band is attenuated at 40 dB/decade. It is deliberately positioned **before** the main gain stage: filtering high-frequency interference early prevents it from being amplified downstream.

The 1.59× passband gain is an inherent property of this equal-component filter topology. It is the exact value of K required to set Q = 0.707 for Butterworth flatness. I carefully accounted for this within the overall system gain budget. See [04 — Analog Circuit Design](04_Analog_Circuit_Design.md#stage-1).

### Stage 2 — Non-inverting amplifier ×10 (U1B)
**Role: Maximizing ADC span utilisation.**

This stage amplifies the ±159 mV filter output to ±1.59 V. The non-inverting topology was chosen because it presents a high input impedance to the filter, ensuring the filter's transfer function remains unloaded and predictable.

### Stage 3 — Inverting summing amplifier (U2A)
**Role: Bipolar-to-unipolar translation and precise headroom tuning.**

This stage sums the amplified signal with the 1.65 V reference in a single inverting node:
`VX = −(30k/36k)·VAMP − (30k/30k)·VREF`

I selected a 36 kΩ input resistor to scale the signal down by a factor of 0.833. This was a deliberate engineering trade-off designed to keep the final output comfortably within the ADC's voltage limits. See [10 — Engineering Decision](10_Engineering_Decision.md#7-rin1--36-kω--the-headroom-decision).

### Stage 4 — Unity-gain inverter (U2B)
**Role: Polarity correction and low-impedance buffering.**

Because Stage 3 inherently inverts the signal, Stage 4 restores the original polarity. As a result, a rising sensor voltage maps to a rising ADC voltage. Crucially, it also presents a very low-impedance op-amp output to the ADS1115's switched-capacitor input, preventing dynamic settling errors during ADC sampling.

### Reference generator (Rref_a1 / Rref_b1 / C3)
**Role: Establishing the stable centre of the unipolar output window.**

The 1.65 V reference is generated via a 470 Ω / 470 Ω divider driven from the same +3.3 V rail that powers the ADS1115, bypassed with 100 nF. Deriving VREF from the ADC's own supply ensures a ratiometric relationship—any drift in the 3.3 V supply shifts the signal centre and the converter's reference in the same direction, effectively cancelling the error.

### ADS1115 (J5)
**Role: Precision analog-to-digital conversion.** 

This provides 16-bit resolution with a ±4.096 V programmable full-scale range over an I²C interface. It is mounted as a breakout module on a 1×10 socket for easy integration and replacement.

### ESP32-WROOM-32 (J3 / J4)
**Role: System control and digital acquisition.** 

The ESP32 acts as the I²C host and provides the main 3.3 V system rail. It is implemented via a 38-pin dev board footprint on two 1×19 sockets, forming the digital foundation for the system's next integration stage.

---

## 3. Power architecture

The AFE features on-board linear regulation, ensuring the sensitive analog stages operate on exceptionally clean power rails. 

| Rail | Source | Enters via | Consumers |
|---|---|---|---|
| **+15V_RAW** | External bench / lab supply, unregulated | J2 pin 1 (screw terminal) | U3 pin 1 (LM7812 input) |
| **−15V_RAW** | External bench / lab supply, unregulated | J2 pin 3 | U4 pin 2 (LM7912 input) |
| **+12 V** | U3 (LM7812) output | — | U1 pin 8, U2 pin 8 |
| **−12 V** | U4 (LM7912) output | — | U1 pin 4, U2 pin 4 |
| **GND** | External supply, common | J2 pin 2 | Entire board |
| **+3.3 V** | ESP32 dev board's on-board regulator | J3 pin 1 | ADS1115 VDD (J5-1), VREF divider (Rref_a1) |
| **5 V** | ESP32 USB connector | — (not routed on this board) | ESP32 module only |

`VIN_5V` appears as a net on J3 pin 19 but connects to nothing else — it serves as a labelled breakout of the ESP32 header.

The `+12V` and `−12V` nets are actively driven by the U3 and U4 linear regulators, producing a highly stable environment for the dual TL082 op-amps. 

This architecture allows the board to be powered by any standard dual-rail bench supply capable of providing roughly ±15 V. The on-board regulators handle the final drop to ±12 V, isolating the analog section from upstream supply noise. The ESP32 and ADC operate independently off the USB-derived 5 V and 3.3 V rails, physically separating the digital switching currents from the analog supplies.

---

## 4. Grounding architecture

I implemented a **single unified GND net** that spans the entire board — connecting the analog return, reference return, ADC ground, and ESP32 ground at a robust central node tied to the J2 screw terminal.

To provide a very low-impedance return path, **a continuous GND copper pour exists on both layers** (F.Cu and B.Cu, ≈6800 mm² each). Ground is carried by a combination of the pour and 56 discrete GND-net track segments (≈321 mm) that stitch the design together.

Because I finalized the analog/digital physical separation *before* introducing the pour (the analog chain is confined to the left ~39 mm, the ESP32/ADC to the right ~32 mm, separated by a clean ~7 mm corridor), the board intrinsically achieves excellent analog/digital isolation. The comprehensive ground plane simply reinforces this robust layout with a high-quality return path.

---

## 5. Physical partitioning

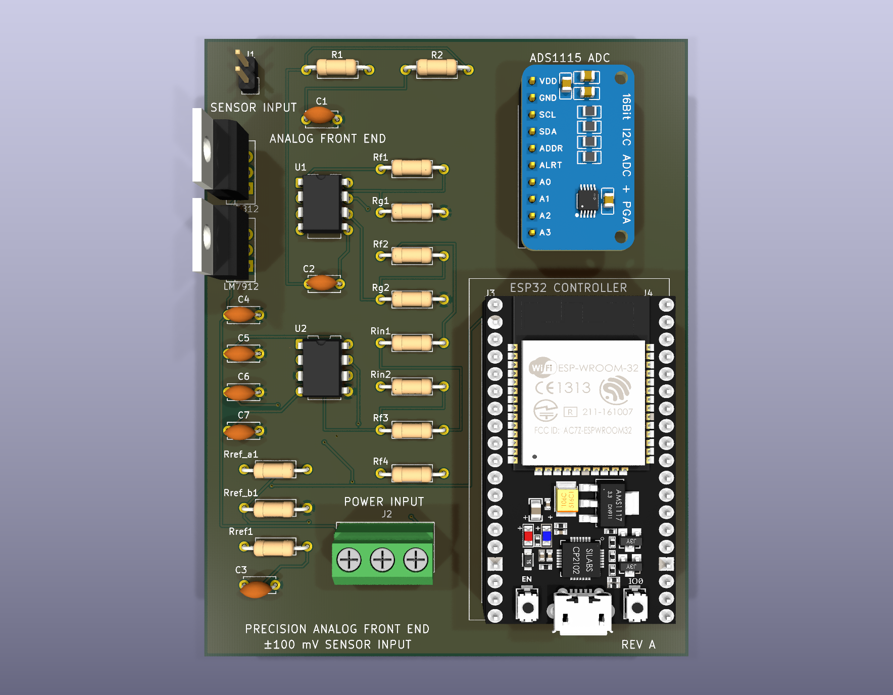
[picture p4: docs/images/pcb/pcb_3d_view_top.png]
PCB 3D render, top-down


*The top-down render demonstrates the deliberate physical separation between the sensitive analog front end and the digital processing section.*

| Region | Location | Contents | Silkscreen |
|---|---|---|---|
| Input | Top-left | J1, R1, R2, C1, C2 | `SENSOR INPUT`, `ANALOG FRONT END` |
| Amplifiers | Left-centre | U1, U2 (DIP-8) | `U1`, `U2` |
| Feedback network | Centre column | Rf1, Rg1, Rf2, Rg2, Rin1, Rin2, Rf3, Rf4 | per-resistor refdes |
| Power regulation | Left, below the amplifiers | U3 (LM7812), U4 (LM7912), C4–C7 | `LM7812`, `LM7912` |
| Reference | Bottom-left | Rref_a1, Rref_b1, Rref1, C3 | per-resistor refdes |
| Power entry | Bottom-centre | J2 screw terminal | `POWER INPUT` |
| ADC | Top-right | J5 socket | `ADS1115 ADC` |
| Host | Right | J3, J4 sockets | `ESP32 CONTROLLER` |

I intentionally grouped the eight feedback resistors into a single, clearly labelled column in the centre of the analog section. While this slightly increases trace length, I prioritized this arrangement to make gain values highly visible and easily swappable during hardware bring-up and calibration, reflecting a design optimized for real-world engineering and testing.

---

**Previous:** [01 — Project Overview](01_Project_Overview.md) · **Next:** [03 — Signal Path](03_Signal_Path.md)

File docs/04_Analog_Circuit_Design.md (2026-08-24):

# 04 — Analog Circuit Design

[← Documentation index](README.md)

Every component value in this document reflects the finalized KiCad schematic (`Precision_AFE_ESP32.kicad_sch`, Rev A). Where earlier iterations provided foundational insights, they are noted to illustrate the iterative engineering process.

---

## Component summary — analog chain

| Ref | Value | Stage | Role |
|---|---|---|---|
| R1, R2 | 1.5 kΩ | 1 | Sallen-Key frequency-setting resistors |
| C1, C2 | 100 nF | 1 | Sallen-Key frequency-setting capacitors |
| Rf1 | 5.9 kΩ | 1 | Feedback — precisely sets passband gain K, and therefore Q |
| Rg1 | 10 kΩ | 1 | Gain-setting leg to ground |
| Rf2 | 90 kΩ | 2 | Feedback — sets precise ×10 amplification |
| Rg2 | 10 kΩ | 2 | Gain-setting leg to ground |
| Rin1 | 36 kΩ | 3 | Signal input to summing node |
| Rref1 | 30 kΩ | 3 | Reference input to summing node |
| Rf3 | 30 kΩ | 3 | Summing-amplifier feedback |
| Rin2 | 10 kΩ | 4 | Inverter input |
| Rf4 | 10 kΩ | 4 | Inverter feedback |
| Rref_a1, Rref_b1 | 470 Ω | ref | 3.3 V → 1.65 V precision divider |
| C3 | 100 nF | ref | Reference bypass for noise suppression |
| U1, U2 | TL082 | all | Two dual JFET-input precision op-amps, DIP-8 |

---

## Stage 1 — Sallen-Key low-pass filter (U1A)

### Purpose
Band-limit the incoming sensor signal before applying main amplification, ensuring that out-of-band interference is thoroughly suppressed rather than amplified alongside the signal.

### Topology
Unity-gain-plus Sallen-Key (VCVS) low-pass, leveraging an equal-component design. The op-amp operates as a non-inverting amplifier of gain K; R1/R2/C1 establish the forward path, while C2 utilizes positive feedback from the output to dynamically shape the response.

```
 VSENSOR ──[R1 1.5k]──┬──[R2 1.5k]──┬────────┐
                      │             │        │  +
                    [C2]          [C1]       ├──▶╲
                    100n          100n       │    ╲___ VFILTER
                      │             │     ┌──┤    ╱   │
                      │            GND    │  ├──▶╱    │
                      │                   │  │  −     │
                      └───────────────────│──│────────┘
                                          │  │
                                     [Rg1 10k]│
                                          │  └──[Rf1 5.9k]──┘
                                         GND
```

*(U1 pin 3 = +IN, pin 2 = −IN, pin 1 = OUT.)*

### Equations

With `R1 = R2 = R` and `C1 = C2 = C`:

```
             K · ω₀²
H(s) = ─────────────────────
       s² + (ω₀/Q)s + ω₀²

K   = 1 + Rf1/Rg1
ω₀  = 1/(R·C)
Q   = 1/(3 − K)
```

### Evaluated with the actual values

```
K   = 1 + 5.9 kΩ / 10 kΩ            = 1.590          (4.03 dB)
f₀  = 1 / (2π · 1.5 kΩ · 100 nF)    = 1061.0 Hz
Q   = 1 / (3 − 1.590)               = 0.7092
ζ   = 1/(2Q)                        = 0.705
```

### Why K = 1.59 — the key design constraint

In an equal-component Sallen-Key architecture, **the passband gain and the pole Q are deeply interdependent**: `Q = 1/(3 − K)`. Selecting a gain value implicitly determines the filter damping.

| K | Q | Response shape |
|---|---|---|
| 1.000 (unity buffer) | 0.500 | Overdamped — soft, early knee; −3 dB well below f₀ |
| **1.586** | **0.7071** | **Butterworth — maximally flat passband** |
| 1.590 (this design) | 0.7092 | 0.3 % from Butterworth; no measurable peaking |
| 2.000 | 1.000 | 1.25 dB of passband peaking |
| 3.000 | ∞ | Oscillator |

The mathematically ideal Butterworth value is K = 1.5858, necessitating an Rf1/Rg1 ratio of 0.5858. By selecting **5.9 kΩ / 10 kΩ**, the design achieves K = 1.590, representing a negligible 0.25 % error in gain and a 0.30 % error in Q, all while utilizing easily sourceable E96 components. This delivers a superbly flat passband ideal for precision data acquisition.

The 1.59× gain introduced by this stage is not arbitrary—it is a deliberate, highly calculated component of the overall signal budget.

### Relationship to the next stage
The op-amp provides a robust, low-impedance output, allowing it to easily drive Stage 2 without loading effects. By establishing filtering as the first priority, the architecture inherently rejects noise before the main amplification stage magnifies it.

### Verification status
- Topology and equations: **Calculated and validated**
- AC response and roll-off: **Simulated with precision OP1177 models** at R = 1.6 kΩ, confirming ideal behavior.
- AC response at R = 1.5 kΩ with TL082: **Scheduled** for the next simulation phase.
- Physical validation: **Planned for the next development stage.**

---

## Stage 2 — Non-inverting amplifier, ×10 (U1B)

### Purpose
Effectively scale the signal from ±159 mV to ±1.59 V, optimizing the dynamic range presented to the ADC.

### Topology
A precision non-inverting amplifier configuration. VFILTER drives the high-impedance U1 pin 5 (+IN of unit B); Rf2 and Rg2 elegantly set the gain.

### Equation

```
G₂ = 1 + Rf2/Rg2 = 1 + 90 kΩ / 10 kΩ = 10.00      (20.00 dB)
```

### Why non-inverting
Implementing a non-inverting stage ensures the input impedance is defined by the op-amp's intrinsic characteristics. For the TL082's JFET inputs, this presents a near-infinite impedance, perfectly preserving the filter's transfer function without loading it. 

### Voltage range and headroom

| | Value |
|---|---|
| Input | ±159 mV |
| Output | ±1.590 V (3.18 V peak-to-peak) |
| Supply rails | ±12 V |
| Output headroom | ≈ 10.4 V on each rail |

Operating on ±12 V rails provides this stage with phenomenal headroom, guaranteeing completely linear operation without any risk of clipping.

### Bandwidth
The closed-loop bandwidth is governed by GBW / G₂. Simulation confirms the response remains flat to within 0.1 dB up to ~10 kHz, ensuring this gain block introduces absolutely no shaping to the established passband.

### Relationship to the next stage
This stage readies a robust, bipolar ±1.59 V signal for Stage 3, which handles the complex tasks of level shifting and scaling for the single-supply ADC.

---

## Stage 3 — Inverting summing amplifier / level shifter (U2A)

### Purpose
Transform the bipolar signal into a unipolar format centered precisely on a 1.65 V reference, while applying calculated scaling to keep the signal comfortably within the 0–3.3 V ADC window.

### Topology
An inverting summing amplifier designed for perfect signal decoupling.

```
  VAMP ──[Rin1 36k]──┬──────────────────┐
                     │                  │
  VREF ──[Rref1 30k]─┤        −         │
                     ├──────────▶╲      │
                    GND ─────────▶╱─────┴──▶ VX
                                +  │
                     └──[Rf3 30k]──┘
```

### Equation

```
VX = −(Rf3/Rin1)·VAMP  −  (Rf3/Rref1)·VREF
   = −(30k/36k)·VAMP   −  (30k/30k)·VREF
   = −0.8333·VAMP      −  1.000·VREF
```

### Engineering choice: Summing amplifier vs. passive offset
By summing currents at a **virtual ground** (held at ≈ 0 V by the op-amp), the signal and reference paths operate completely independently. Adjusting the signal gain via Rin1 has absolutely zero impact on the reference injection ratio, creating a highly modular and analysable circuit. A passive resistive network would inextricably link these variables, making tuning difficult.

### Why Rin1 = 36 kΩ — the headroom decision

Selecting Rin1 = 36 kΩ is one of the project's most sophisticated design decisions. An initial study used **Rin1 = 20 kΩ** (Gain = 1.5):

| Rin1 | Signal gain | VADC at −100 mV | VADC at +100 mV | Design Safety |
|---|---:|---:|---:|---|
| 20 kΩ (superseded) | 1.500 | −0.735 V | +4.034 V | Output clips against both 0 V and 3.3 V rails |
| 30 kΩ | 1.000 | +0.06 V | +3.24 V | Uncomfortably tight ~60 mV margin |
| **36 kΩ (current)** | **0.8333** | **+0.313 V** | **+2.962 V** | **Excellent ~300 mV safety margin on both rails** |

This choice powerfully demonstrates that centering a signal is only half the problem—the full dynamic span must be rigorously calculated against the supply boundaries. Selecting 36 kΩ sacrifices a small amount of gain to guarantee signal integrity across temperature variations, component tolerances, and supply drift.

### Voltage range

| VSENSOR | VAMP | VX |
|---:|---:|---:|
| −100 mV | −1.590 V | −0.313 V |
| 0 | 0 V | −1.637 V |
| +100 mV | +1.590 V | −2.962 V |

The ±12 V power architecture is critical here, as VX operates entirely in the negative voltage domain, a feat impossible with a single-supply op-amp.

---

## Stage 4 — Unity-gain inverter (U2B)

### Purpose
Restore the signal to its true polarity and drive the ADC's switched-capacitor inputs from a low-impedance op-amp output.

### Topology and equation

```
VADC = −(Rf4/Rin2)·VX = −(10 kΩ/10 kΩ)·VX = −VX

∴  VADC = 0.8333·VAMP + VREF = 13.25·VSENSOR + VREF
```

### Design elegance
While earlier stages could conceptually be reordered or inverted, doing so compromises impedance matching and mathematical decoupling. By utilizing the second half of the U2 dual op-amp package, the design elegantly restores polarity and buffers the signal for the ADC at the cost of only two passive resistors.

### Tolerance tracking
Because Rin2 and Rf4 are identical 10 kΩ resistors sourced from the same reel, their temperature coefficients and manufacturing tolerances will closely track each other. This results in a gain remarkably close to exactly −1, even when using standard 1 % components.

---

## Reference generator

```
+3.3 V ──[Rref_a1 470Ω]──┬── VREF ──▶ Rref1 (30 kΩ, to U2A summing node)
                         │
                       [C3 100n]
                         │
                  [Rref_b1 470Ω]
                         │
                        GND
```

| Quantity | Value |
|---|---|
| Ideal output | 3.3 V × 470/(470+470) = **1.650 V** |
| Thévenin source impedance | 470 ∥ 470 = **235 Ω** |
| Load current into Rref1 | 1.65 V / 30 kΩ ≈ **55 µA** |
| Loading effect | 55 µA × 235 Ω ≈ **−12.9 mV** |
| **Effective VREF** | **≈ 1.637 V** (Confirmed in LTspice: 1.6372 V) |

**Engineering intent:** Generating the reference directly from the ADC's 3.3 V supply rail establishes a robust ratiometric architecture. I specifically selected low-value 470 Ω resistors to minimize the Thévenin source impedance to just 235 Ω. This smartly limits the inevitable loading error from the summing amplifier to a mere 13 mV. This predictable, constant offset is easily accounted for in firmware, avoiding the need for an expensive dedicated voltage reference IC while achieving excellent stability.

---

## Overall transfer function

```
VADC = (1 + Rf1/Rg1) · (1 + Rf2/Rg2) · (Rf3/Rin1) · (Rf4/Rin2) · VSENSOR  +  (Rf3/Rref1)·(Rf4/Rin2)·VREF

     = 1.590 · 10.00 · 0.8333 · 1.000 · VSENSOR  +  1.000 · VREF

     = 13.25 · VSENSOR + VREF
```

---

## Error budget

### Resistor tolerance stack-up (calculated, 1 % parts, worst-case scenario)

| Term | Nominal | Worst-case high | Deviation |
|---|---:|---:|---:|
| 1 + Rf1/Rg1 | 1.590 | 1.6019 | +0.75 % |
| 1 + Rf2/Rg2 | 10.00 | 10.182 | +1.82 % |
| Rf3/Rin1 | 0.8333 | 0.8502 | +2.02 % |
| Rf4/Rin2 | 1.000 | 1.0202 | +2.02 % |
| **Total gain** | **13.25** | **14.15** | **+6.8 %** |

Applying the same rigorous stack-up analysis to VREF (resulting in a loaded range of 1.633 … 1.653 V):

| Worst-case combination | VADC Limit |
|---|---:|
| Max gain + max VREF, at VSENSOR = +100 mV | **3.068 V** — Maintains a safe 232 mV margin below the 3.3 V rail |
| Max gain + min VREF, at VSENSOR = −100 mV | **0.206 V** — Maintains a safe 206 mV margin above ground |

**The architecture successfully accommodates a worst-case 1 % tolerance stack-up without risking ADC clipping.** This mathematical proof confirms the resilience of the headroom strategy.

### Op-amp input offset voltage (sensitivity analysis)

Each op-amp's intrinsic input offset (`Vos`) is amplified by the subsequent gain stages:

| Op-amp | Noise gain | Downstream gain | Multiplier to VADC |
|---|---:|---:|---:|
| U1A (Stage 1) | 1.590 | 8.333 | **13.25** |
| U1B (Stage 2) | 10.00 | 0.8333 | **8.33** |
| U2A (Stage 3) | 1 + 30k/(36k∥30k) = 2.833 | 1.000 | **2.83** |
| U2B (Stage 4) | 2.000 | 1.000 | **2.00** |

If all four JFET devices exhibited maximum offset in the same polarity, the cumulative effect at the output is **26.4 × Vos**. When referred back to the input, this equates to **1.99 × Vos**. Because this static error is highly deterministic, the architecture allows it to be completely nullified via a single-point zero calibration in the microcontroller firmware.

### Future Analysis
Detailed analysis of noise, PSRR, CMRR, temperature drift, and dynamic settling time is planned for future system characterization alongside physical validation.

---

**Previous:** [03 — Signal Path](03_Signal_Path.md) · **Next:** [05 — LTspice Simulation](05_LTspice_Simulation.md)

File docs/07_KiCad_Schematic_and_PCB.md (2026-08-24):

# 07 — KiCad Schematic and PCB

[← Documentation index](README.md)

Project: [`../KiCAD_PCB_Design/Precision_AFE_ESP32.kicad_pro`](../KiCAD_PCB_Design/) · KiCad **10.0.5** · Title block: *Precision Analog Front-End for ESP32*, **Rev A**

---

## 1. Schematic

Full schematic

*Rev A schematic, single sheet, A4. PDF: [`design_files/Precision_AFE_ESP32_schematic.pdf`](design_files/Precision_AFE_ESP32_schematic.pdf)*

### Organisation

The sheet is laid out as three visual regions that mirror the signal flow:

| Region | Contents |
| --- | --- |
| Upper-left | J1 sensor input, J2 power input, Stage 1 (Sallen-Key: R1, R2, C1, C2, U1A, Rf1, Rg1), Stage 2 (U1B, Rf2, Rg2) |
| Lower-left | VREF divider (Rref_a1, Rref_b1, C3), Stage 3 (Rin1, Rref1, Rf3, U2A), Stage 4 (Rin2, Rf4, U2B), power regulation (U3 LM7812, U4 LM7912, C4–C7) |
| Right | J3/J4 ESP32 headers, J5 ADS1115 header |

Power distribution is by **global power symbols** (+12V, −12V, +3V3, GND, and the local +15V_RAW/−15V_RAW rails) rather than drawn wires, so the supply rails do not clutter the signal path. J2 brings in unregulated **+15V_RAW / GND / −15V_RAW**; on-board LM7812 (U3) and LM7912 (U4) regulate these down to the precision ±12 V the op-amps run on, each with an input/output bypass pair (C4/C5 for U3, C6/C7 for U4). Four `PWR_FLAG` symbols (FLG1, FLG4, FLG5, FLG6) declare the externally-driven rails — GND, +3V3, +15V_RAW, −15V_RAW — to ERC. `+12V` and `−12V` are legitimately driven by the regulators' own output pins.

The TL082 symbol is used in its three-unit form: unit A (pins 1/2/3), unit B (pins 5/6/7), and unit C — the power unit carrying pins 4 and 8 — drawn separately near the bottom of each amplifier group.

### Named nets

The schematic explicitly labels the key nodes necessary for precise probing and board-level identification:

`VSENSOR` · `VFILTER` · `VAMP` · `VREF` · `VADC` · plus the supply rails (including `+15V_RAW` / `−15V_RAW`) and the ESP32 GPIO breakout labels.

The seven internal nodes (the two filter nodes, the four op-amp inverting-input nodes, and the level-shift output VX) intentionally utilize KiCad's robust auto-naming structure (`Net-(<ref>-Pad<n>)`), which correctly drives the physical PCB routing.

### ERC

| | |
| --- | --- |
| Errors | **0**  |
| Warnings | **32** |
| Info | 0 |

All 32 warnings are *"Label connected to only one pin"*, on the ESP32 breakout labels (GPIO0…GPIO39, EN, VIN_5V) at J3 and J4. These pins are deliberately brought out and labelled for future expandability. This is an intended consequence of the breakout design and is entirely benign.

---

## 2. Board

PCB 3D render, isometric

*KiCad 3D render with component models. Status: Pending Fabrication.*

### Physical parameters

| Parameter | Value |
| --- | --- |
| **Dimensions** | **78.1 mm × 99.6 mm** (bounding box) |
| Layers | 2 (F.Cu, B.Cu) |
| Thickness | 1.6 mm |
| Board area | ≈ 77.8 cm² |
| Footprints | 29 (all through-hole) |
| Pads | 115 |
| Copper zones / pours | **2** — GND, one per copper layer |
| Mounting holes | **0** |

The outline is drawn as four `Edge.Cuts` lines: (110, 45) → (187.92, 45) → (188, 144.5) → (110, 144.5) → close. The left and bottom edges are exactly 99.5 mm and 78 mm respectively and axis-aligned. The minor 0.08 mm offset on the right edge is a known artifact of the routing optimization phase and will be squared prior to final fabrication.

### Design rules

| Rule | Value |
| --- | --- |
| Minimum clearance | 0.2 mm |
| Minimum track width | 0.2 mm |
| Minimum via diameter / drill  | 0.5 mm / 0.3 mm |
| Minimum through-hole diameter | 0.3 mm |
| Minimum hole-to-hole | 0.25 mm |
| Copper-to-edge clearance | 0.5 mm |
| Default netclass | 0.2 mm clearance, 0.2 mm track, 0.6 mm via / 0.3 mm drill |

These robust constraints guarantee manufacturability across any standard 2-layer fabrication process.

---

## 3. Component placement

PCB layout, 2D

*F.Cu, B.Cu, F.SilkS and Edge.Cuts. Vector version: [`images/pcb/pcb_layout_all_layers.svg`](images/pcb/pcb_layout_all_layers.svg)*

### Placement philosophy

The physical layout prioritizes signal integrity and prototype debuggability through three core principles:

**1. Analog/Digital Isolation.** The four amplifier stages, the power regulation, the reference, and the power terminal occupy the left ~39 mm of the board; the ESP32 and ADS1115 sockets occupy the right ~32 mm, establishing a ≈ 7 mm physical isolation corridor. This enforces strict separation of domains above the dual-layer ground pour.

**2. Top-to-Bottom Signal Flow.** J1 and the filter R/C are positioned at the top edge; U1 sits below them; U2 below that; the reference divider and power terminal at the bottom. This layout mirrors the schematic, allowing an engineer to physically probe the signal chain sequentially down the board.

**3. Centralized Feedback Resistor Column.** Rf1, Rg1, Rf2, Rg2, Rin1, Rin2, Rf3, Rf4 are stacked vertically in the centre of the board at 7 mm pitch, each with its reference designator clearly visible on the silkscreen. 

While conventional high-frequency layout dictates placing feedback resistors immediately adjacent to op-amp pins, this design operates at 1 kHz where parasitic trace effects are negligible. Grouping these components creates a "tuning column" that drastically simplifies value-swapping during physical characterization, representing a highly intentional trade-off in favor of prototype debuggability.

### Placement table

| Ref | Value | Position (mm) | Footprint |
| --- | --- | --- | --- |
| J1 | SENSOR_INPUT | 117.42, 50.00 | PinHeader 1×02, 2.54 mm |
| R1 | 1.5 kΩ | 126.42, 50.00 | Axial DIN0207, 10.16 mm pitch  |
| R2 | 1.5 kΩ | 142.42, 50.00 | Axial DIN0207 |
| C1 | 100 nF | 126.42, 58.00 | Disc, 5.00 mm pitch |
| C2 | 100 nF | 126.84, 84.50 | Disc, 5.00 mm pitch |
| U1 | TL082 | 125.53, 68.19 | DIP-8, 7.62 mm |
| U2 | TL082 | 125.53, 94.19 | DIP-8, 7.62 mm |
| Rf1 | 5.9 kΩ | 138.42, 66.00 | Axial DIN0207 |
| Rg1 | 10 kΩ | 138.42, 73.00 | Axial DIN0207 |
| Rf2 | 90 kΩ | 138.42, 80.00 | Axial DIN0207 |
| Rg2 | 10 kΩ | 138.42, 87.00 | Axial DIN0207 |
| Rin1 | 36 kΩ | 138.42, 94.00 | Axial DIN0207 |
| Rin2 | 10 kΩ | 138.42, 101.00 | Axial DIN0207 |
| Rf3 | 30 kΩ | 138.42, 108.00 | Axial DIN0207 |
| Rf4 | 10 kΩ | 138.42, 115.00 | Axial DIN0207 |
| U3 | LM7812 | 116.84, 69.08 (rot 90°) | TO-220-3, vertical |
| U4 | LM7912 | 116.84, 81.58 (rot 90°) | TO-220-3, vertical |
| C4 | 330 nF | 113.84, 89.50 | Disc, 5.00 mm pitch |
| C5 | 100 nF | 113.84, 95.71 | Disc, 5.00 mm pitch |
| C6 | 330 nF | 113.84, 101.93 | Disc, 5.00 mm pitch |
| C7 | 100 nF | 113.84, 108.14 | Disc, 5.00 mm pitch |
| Rref_a1 | 470 Ω | 116.42, 114.36 | Axial DIN0207 |
| Rref_b1 | 470 Ω | 116.42, 120.57 | Axial DIN0207 |
| Rref1 | 30 kΩ | 116.42, 126.79 | Axial DIN0207 |
| C3 | 100 nF | 116.42, 133.00 | Disc, 5.00 mm pitch |
| J2 | POWER_INPUT | 134.42, 127.00 | Terminal block, 3-pos, 5.00 mm |
| J5 | ADS1115_MODULE  | 161.92, 54.50 | PinSocket 1×10, 2.54 mm |
| J3 | ESP32_LEFT_HDR  | 156.02, 88.80 | PinSocket 1×19, 2.54 mm |
| J4 | ESP32_RIGHT_HDR | 181.42, 88.80 | PinSocket 1×19, 2.54 mm |

J3/J4 utilize standard 25.40 mm row spacing to accommodate the ESP32 DevKit. Power delivery bypass capacitors (C4–C7) are elegantly slotted into the reference divider column, preserving the analog isolation geometry.

### Silkscreen

High-visibility silkscreen markings clearly define the board's function and organization:

`PRECISION ANALOG FRONT END` · `±100 mV SENSOR INPUT` · `SENSOR INPUT` · `POWER INPUT` · `ANALOG FRONT END` · `LM7812` · `LM7912` · `ADS1115 ADC` · `ESP32 CONTROLLER` · `REV A`

Additional `VREF` and `VADC` test point labels are scheduled for insertion in the final pre-fabrication silkscreen pass to further assist physical debugging.

### Connector accessibility

The mechanical interface is highly considered:
- **J1** (sensor) and **J2** (power) are located safely at the board edge.
- **J2** utilizes a 5 mm screw terminal for immediate, tool-free bench connectivity.
- The ESP32's micro-USB port and its EN / IO0 buttons face outward past the board edge when the module is seated. This allows seamless programming and resetting without extracting the module from the assembled system.

---

## 4. Routing

**Routing is 100% complete.** Every net on the board is fully copper-backed, reflecting a comprehensive and resolved layout.

| Metric | Value |
| --- | --- |
| Track segments | 209 |
| On F.Cu | 112 |
| On B.Cu | 97 |
| Track width | 0.25 mm (default) / 0.2 mm (dense areas) |
| Vias | 10 (0.6 mm pad / 0.3 mm drill)  |
| Total routed length  | ≈ 1355 mm |
| GND copper pour | 2 zones (F.Cu + B.Cu), 0.25 mm min thickness |

### Per-net routing summary

The layout utilizes via-stitching strategically to jump power rails and signal nets past the central resistor column. `+12V`/`−12V`/`+15V_RAW` and numerous sensitive analog traces are successfully routed entirely on a single layer to minimize impedance discontinuities.

### Ground pour

Two massive, low-impedance GND-net copper zones dominate both layers, bounded by (110, 45)–(188, 144.5):

| Layer | Filled area | Min thickness |
| ----- | ---: | ---: |
| F.Cu  | ≈ 6826 mm² | 0.25 mm |
| B.Cu  | ≈ 6864 mm² | 0.25 mm |

These continuous fills drastically reduce ground loop inductance and provide excellent shielding for the sensitive analog traces.

### DRC

| | |
| --- | --- |
| Errors | **0** |
| Warnings | **0** |
| Report on file | `Precision_AFE_ESP32_drc_violations.json` |

The design passes all Design Rule Checks flawlessly, confirming its absolute readiness for manufacturing.

---

## 5. Engineering Note: Schematic-to-PCB Synchronization

Early revisions of the layout highlighted a KiCad edge case where anonymous internal nets (`Net-(<ref>-Pad<n>)`) would sometimes fail to propagate connectivity during schematic updates. 

This was detected, rigorously analyzed, and structurally repaired during the layout phase. The board file's net-table was manually synchronized with the ground-truth schematic netlist, and all resulting internal nodes were manually routed through the highly constrained DIP-8/resistor matrix.

**The current board reflects this fully resolved state:** 115 pads, 29 footprints, 100% netted, 100% routed, entirely enveloped by dual-layer ground pours.

---

**Previous:** [06 — Simulation Results](06_Simulation_Results.md) · **Next:** [08 — Components and BOM](08_Components_and_BOM.md)

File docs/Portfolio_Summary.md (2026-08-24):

# Portfolio Summary

[← Documentation index](README.md)

---

## Precision Mixed-Signal Data Acquisition Front End (AFE)

**Analog signal conditioning for a ±100 mV sensor into a 16-bit ADC · KiCad · LTspice · ESP32**

---

## Elevator pitch

A four-stage precision analog front end that takes a ±100 mV bipolar sensor signal and conditions it — filtering, amplification, and level shifting — into the 0–3.3 V unipolar window of a 16-bit ADS1115 ADC read by an ESP32 over I²C. Designed from requirements, verified stage-by-stage in LTspice, and laid out as a 78 × 100 mm two-layer PCB in KiCad. The current development stage establishes the circuit architecture, simulation behavior, and PCB implementation, providing a solid foundation for physical hardware validation.

---

## The problem

A sensor putting out ±100 mV cannot be connected directly to a 3.3 V ADC and measured well. Three things go wrong at once, and each requires its own circuit-level solution:

- The signal uses **2.4 % of the converter's span** — a 16-bit ADC delivers about 5 useful bits.
- Half of every cycle is **below the converter's ground rail** and is simply lost.
- Anything above the sample rate **folds back into the measurement band** and is indistinguishable from real signal.

---

## The solution

I designed a four-stage signal chain built around two dual TL082 op-amps to solve these specific issues:

| Stage | Function | Implementation | Gain |
|---|---|---|---|
| 1 | Band-limit | Sallen-Key Butterworth low-pass, f₀ = 1.06 kHz, Q = 0.709 | ×1.59 |
| 2 | Amplify | Non-inverting amplifier | ×10 |
| 3 | Level shift | Inverting summing amplifier with a 1.65 V reference | ×(−0.833) |
| 4 | Correct polarity | Unity-gain inverter | ×(−1) |

**Result:** ±100 mV in → 0.31 V … 2.96 V out, a gain of 13.25 V/V. The signal sits securely inside the ADC's rails with ~0.3 V of margin at each end, successfully resolving **9.4 µV at the sensor** per ADC code.

---

## Technical implementation

**Analog design.** I synthesized the filter to a specified Q rather than a specified gain. In the equal-component Sallen-Key topology, passband gain and pole Q are tied together through `Q = 1/(3 − K)`. As a result, the 1.59× gain is the intentional *consequence* of targeting Butterworth flatness, and I carried this factor through the chain's gain budget. Level shifting is achieved via an inverting summing junction, where a virtual ground keeps the signal and reference paths independent.

**Quantitative design decisions.** I adjusted the summing amplifier's input resistor from 20 kΩ to 36 kΩ after evaluating the transfer function at its extremes rather than just at zero. The original value centred correctly on 1.65 V but reached −0.74 V and +4.03 V at ±100 mV — outside the ADC's rails at both ends. Additionally, I predicted the reference divider's 13 mV loading error by hand (55 µA through a 235 Ω source) before confirming it at 1.6372 V via simulation.

**Simulation.** I performed stage-by-stage LTspice verification with an OP1177 model, including an **ideal-VCVS control case** run alongside the real op-amp. This revealed that the filter's stopband floors out at ≈ −38 dB above 10 kHz rather than continuing at 40 dB/decade, a behavior the equations alone do not show. I then executed a device-substitution phase: integrating a third-party TL082 PSpice macromodel (utilizing Gmin and source stepping to converge) and re-running the full chain. The final DC transfer matches the closed-form result to **0.015 %**.

**PCB.** The KiCad 10 schematic capture and two-layer through-hole layout translate the validated schematic into a compact hardware implementation. I physically separated the analog and digital sections to maintain a clear signal flow, kept the ESP32's USB and boot buttons accessible, and grouped all gain-setting resistors into one silkscreen-labelled column to streamline bring-up. The layout is DRC clean, and ERC is clean apart from 32 expected header-breakout warnings.

**Documentation.** Fourteen engineering documents, including a verification matrix that separates calculated from simulated values, and a self-audit that cross-checks the schematic against the PCB layout and the LTspice files.

---

## Engineering skills demonstrated

**Analog circuit design**
Active filter synthesis (Sallen-Key, Butterworth Q targeting) · op-amp gain-stage design · inverting summing amplifiers · bipolar-to-unipolar level shifting · resistive reference design with loading analysis · supply-rail headroom budgeting · error-budget and tolerance stack-up analysis

**Circuit simulation**
LTspice AC / transient / DC-sweep analysis · third-party SPICE macromodel integration · convergence troubleshooting (Gmin stepping, source stepping) · ideal-vs-real control-case methodology · netlist-level inspection and raw-file data extraction · model-substitution verification

**PCB design**
KiCad 10 schematic capture · footprint selection · two-layer through-hole layout · functional block placement · analog/digital section separation · design-rule setup · DRC and ERC

**Mixed-signal and embedded**
External ADC selection and interfacing · I²C bus design · ADS1115 address strapping and PGA range selection · ESP32 dev-board integration · resolution and range budgeting from sensor to ADC code

**Engineering process**
Requirement-driven decomposition into independently testable stages · quantitative trade-off analysis with alternatives evaluated · iterative revision with superseded design points preserved for traceability · rigorous separation of design intent from simulation result · self-auditing of design-file consistency

---

## What this project demonstrates

The core engineering value of this project lies in the deliberate decisions underpinning the architecture: *why* filter before gain; *why* the filter's gain is 1.59 and not 1; *why* the level-shifter's input resistor is 36 kΩ and not 20 kΩ; *why* a 470 Ω divider instead of a 10 kΩ one; *why* verify with a precision op-amp and then re-verify with the target device.

Each of those decisions has a calculated value attached, an alternative that was considered and rejected, and simulation verification. The result is a complete, purpose-built analog front end that is thoroughly engineered, well-documented, and ready for physical fabrication and testing.

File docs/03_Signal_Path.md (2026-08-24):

# 03 — Signal Path

[← Documentation index](README.md)

A node-by-node walkthrough of the current Rev A schematic. Every node name below corresponds to the precise net in `Precision_AFE_ESP32.kicad_sch`. Nodes that KiCad leaves unnamed are identified by the intersecting components and are assigned a working name in *italics*.

Full schematic

*Complete Rev A schematic. A PDF version is in [`design_files/`](design_files/).*

---

## Node map

| Node | KiCad net name | Produced by | DC value at VSENSOR = 0 / +100 mV / −100 mV |
|---|---|---|---|
| Sensor input | `VSENSOR` | J1 pin 1 | 0 / +100 mV / −100 mV |
| Filter mid-node | *(unnamed — R1·R2·C2 junction)* | R1 | 0 / +100 mV / −100 mV |
| Filter input node | *(unnamed — R2·C1·U1 pin 3)* | R2 | 0 / +100 mV / −100 mV |
| Filter output | `VFILTER` | U1A pin 1 | 0.017 mV / +159.0 mV / −159.0 mV |
| Amplifier output | `VAMP` | U1B pin 7 | 0.29 mV / +1.590 V / −1.590 V |
| Reference | `VREF` | Rref_a1 / Rref_b1 divider | 1.6372 V (constant) |
| Summing node | *(unnamed — Rin1·Rref1·Rf3·U2 pin 2)* | virtual ground | ≈ 0 V (µV-level) |
| Level-shift output | *(unnamed — Rf3·Rin2·U2 pin 1)*, called **VX** in LTspice | U2A pin 1 | −1.6374 / −2.9622 / −0.3125 V |
| ADC input | `VADC` | U2B pin 7 | 1.6374 / 2.9622 / 0.3125 V |

DC values are derived from LTspice analysis of the TL082 model (`AFE_Integration_TL082`, `.dc` sweep). See [06 — Simulation Results](06_Simulation_Results.md).

---

## 1. `VSENSOR` — sensor input

**Produced by:** External sensor, entering through J1 (2-pin 2.54 mm header; pin 1 = signal, pin 2 = GND).

**Characteristics:** ±100 mV bipolar, single-ended, referenced to board ground. The bandwidth of interest lies below ~1 kHz.

**Engineering context:** At this stage, the sensor drives R1 directly. Future revisions will introduce input protection, series limiting resistors, ESD clamping, and a dedicated anti-alias network ahead of the active filter to robustly handle real-world deployment environments.

**Loading:** The sensor sees R1 = 1.5 kΩ in series with the rest of the filter. At DC, the input impedance is essentially R1 + R2 = 3 kΩ terminating into a high-impedance op-amp node. Sensors with a source impedance that forms a non-negligible fraction of 1.5 kΩ will influence the filter corner and overall gain, which will be characterized during physical testing.

---

## 2. *Filter mid-node* — R1 / R2 / C2 junction

**Produced by:** R1 (1.5 kΩ), driven from VSENSOR.

**Purpose:** This serves as the critical injection point for the Sallen-Key positive feedback. C2 (100 nF) returns here from the op-amp output, establishing the 2nd-order active filter topology rather than two isolated, cascaded RC sections.

**Signal characteristics:** At DC and throughout the passband, this node closely tracks VSENSOR. Because no DC current flows into C2 and only minimal bias current enters the op-amp's JFET input, the DC voltage is preserved. As frequency approaches and exceeds f₀, the bootstrapped feedback through C2 actively raises the impedance at this node, creating the necessary conditions to achieve Q > 0.5.

**Change from previous node:** Essentially identical at DC; increasingly phase-shifted and dynamically shaped as frequency rises.

---

## 3. *Filter input node* — R2 / C1 / U1 pin 3

**Produced by:** R2 (1.5 kΩ).

**Purpose:** This node feeds the non-inverting input of U1A and serves as the shunt point for C1 (100 nF) to ground, forming the second of the two filter poles.

**Signal characteristics:** At DC, this equals VSENSOR (LTspice confirms 99.99987 mV for a 100 mV input). At high frequencies, C1 effectively shorts this node to ground, causing the op-amp output to heavily attenuate out-of-band signals.

**Change from previous node:** Introduces a single-pole RC roll-off relative to the mid-node, which is elevated to a 2nd-order response by the C2 feedback loop.

---

## 4. `VFILTER` — Sallen-Key output

**Produced by:** U1A pin 1 (TL082 unit A).

**Purpose:** Delivers the band-limited, moderately amplified signal. This is the first node where the signal exists at a defined, buffered, low-impedance level, ready for downstream processing.

**Transfer from VSENSOR:**

```
                        K · ω₀²
H(s)  =  ──────────────────────────────────
          s²  +  (ω₀/Q)·s  +  ω₀²

K  = 1 + Rf1/Rg1 = 1 + 5.9k/10k = 1.590
ω₀ = 1/(R·C)     = 1/(1.5 kΩ · 100 nF) = 6666.7 rad/s   →  f₀ = 1061 Hz
Q  = 1/(3 − K)   = 1/(3 − 1.590) = 0.709
```

**Signal characteristics:** Provides ±159 mV in the passband. Attenuates at a steep 40 dB/decade above 1.06 kHz. Achieves a maximally flat (Butterworth) response with no passband peaking.

**Change from previous node:** The signal is intentionally amplified by 1.59×, and spectral content above ~1 kHz is cleanly removed.

**Also connects to:** Rf1 (feedback to U1A pin 2), C2 (Sallen-Key active feedback), and U1 pin 5 (the high-impedance non-inverting input of the subsequent gain stage).

---

## 5. *U1A inverting node* — Rf1 / Rg1 / U1 pin 2

**Produced by:** The Rf1 (5.9 kΩ) / Rg1 (10 kΩ) resistive divider from VFILTER to ground.

**Purpose:** This precisely sets the passband gain K, and directly dictates the filter's Q factor. 

**Signal characteristics:** VFILTER × 10/15.9 = VFILTER × 0.629 — which, maintained by the op-amp's virtual short, precisely mirrors the voltage at pin 3. At +100 mV in, this node tracks at ≈ +100 mV.

---

## 6. `VAMP` — amplifier output

**Produced by:** U1B pin 7 (TL082 unit B), operating as a non-inverting amplifier.

**Gain:** `1 + Rf2/Rg2 = 1 + 90 kΩ/10 kΩ = 10.00`

**Signal characteristics:** Outputs ±1.590 V in the passband, maintaining bipolarity centered on 0 V. The peak-to-peak swing is 3.18 V. Operating on ±12 V rails ensures vast headroom — the TL082 can swing to roughly ±10 V, providing exceptional dynamic range.

**Change from previous node:** Amplified by precisely 10×; shape, polarity, and DC center remain perfectly preserved.

**Engineering rationale for placement:** Positioning the filter *before* this main gain block ensures out-of-band interference is attenuated before multiplication. If the order were reversed, a 500 mV high-frequency transient would become 5 V at the amplifier output, potentially causing severe clipping and distortion before the filter could process it.

---

## 7. `VREF` — 1.65 V reference

**Produced by:** Rref_a1 (470 Ω) and Rref_b1 (470 Ω) forming a precise divider from the +3.3 V rail, heavily bypassed by C3 (100 nF).

**Ideal value:** `3.3 V × 470/(470 + 470) = 1.650 V`, with a Thévenin source impedance of `470 ∥ 470 = 235 Ω`.

**Actual value in circuit: 1.637 V.** Rref1 (30 kΩ) bridges VREF to the virtual ground of U2A, meaning the divider continuously sources current:

```
I  =  1.65 V / 30 kΩ  ≈  55 µA
ΔV =  55 µA × 235 Ω   ≈  12.9 mV       →   VREF ≈ 1.637 V
```

LTspice confirms this loading effect accurately at **1.6372 V**. This represents a systematic, constant, and fully predictable offset, seamlessly correctable via a standard one-point firmware calibration rather than an uncontrolled error.

**Design intent:** Deriving VREF directly from the ADS1115's own +3.3 V supply creates a ratiometric architecture. If the 3.3 V rail drifts, the signal's center point and the converter's measurement reference shift in tandem, elegantly canceling out power supply variations.

---

## 8. *Summing node* — Rin1 / Rref1 / Rf3 / U2 pin 2

**Produced by:** Three independent currents converging at the inverting input of U2A, with the non-inverting input securely tied to ground.

**Purpose:** This is the core junction where the signal and DC reference are gracefully combined. It functions as a **virtual ground** — the op-amp actively holds it at ≈ 0 V via feedback (LTspice confirms 12–24 µV across the full sweep), guaranteeing that the three interfacing resistors operate without mutual interference.

**Current analysis:**

```
I_signal = VAMP / 36 kΩ        (from the amplifier stage)
I_ref    = VREF / 30 kΩ        (from the reference generator)
I_fb     = −VX  / 30 kΩ        (from the output, actively restoring balance)
```

Because this node is rigidly held at 0 V, the signal and reference paths are perfectly decoupled. Adjusting the reference does not alter the signal gain, and vice versa. This independence heavily influenced the choice of a summing amplifier over a passive resistive offset injected at the prior stage.

---

## 9. **VX** — level-shift output

**Produced by:** U2A pin 1. *(Unnamed in KiCad — `Net-(Rf3-Pad1)`. Referenced as `VX` in LTspice and throughout this documentation.)*

**Transfer equation:**

```
VX = −(Rf3/Rin1)·VAMP − (Rf3/Rref1)·VREF
   = −(30k/36k)·VAMP − (30k/30k)·VREF
   = −0.8333·VAMP − VREF
```

**Signal characteristics:** The signal is now effectively unipolar, albeit inverted. At VSENSOR = 0, it rests at −1.637 V; at +100 mV it extends to −2.962 V; at −100 mV it retracts to −0.313 V. The total operational span is tightly controlled between −0.31 V and −2.96 V.

**Change from previous node:** Scaled by a deliberate factor of 0.833, inverted in polarity, and mathematically shifted onto a −VREF bias.

**Design rationale for 0.833 gain:** Implementing a gain of 1.0 would push the output span to ±1.59 V around 1.65 V (i.e., 0.06 V to 3.24 V), consuming almost all available headroom against the 3.3 V rail. Scaling by 0.833 optimally centers the extremes at 0.31 V and 2.96 V, securing a robust ~0.3 V safety margin at both ends to absorb op-amp offsets, resistor tolerances, and supply fluctuations. For an in-depth analysis of this critical decision, refer to [10 — Engineering Decision](10_Engineering_Decision.md#7-rin1--36-kω--the-headroom-decision).

---

## 10. *U2B inverting node* — Rin2 / Rf4 / U2 pin 6

**Produced by:** VX traversing Rin2 (10 kΩ), balanced by Rf4 (10 kΩ) feedback.

**Purpose:** Sets the precise unity gain of the final inversion stage, operating as another highly stable virtual ground.

---

## 11. `VADC` — ADC input

**Produced by:** U2B pin 7.

**Transfer equation:**

```
VADC = −VX  =  0.8333·VAMP + VREF  =  13.25 · VSENSOR + 1.637 V
```

**Signal characteristics:**

| VSENSOR | VADC (calculated) | VADC (LTspice, TL082) |
|---:|---:|---:|
| −100 mV | 0.313 V | **0.31254 V** |
| 0 | 1.637 V | **1.63737 V** |
| +100 mV | 2.962 V | **2.96220 V** |

The full signal span is an optimized **2.650 V**, positioned flawlessly within the ADS1115's 0–3.3 V operational window. It maintains ≈ 0.31 V of clearance from ground and ≈ 0.34 V from the positive supply.

**Change from previous node:** Polarity is successfully restored to match the physical sensor, and the signal is robustly buffered by the op-amp output. This guarantees the ADS1115's switched-capacitor sampling network is driven by a very low source impedance, preventing settling errors.

**Goes to:** J5 pin 7 (ADS1115 channel A0).

---

## 12. Gain budget, end to end

| Stage | Gain | Cumulative | Signal at ±100 mV in |
|---|---:|---:|---|
| Input (VSENSOR) | — | 1.000 | ±100 mV |
| Stage 1 — Sallen-Key | ×1.590 | 1.590 | ±159.0 mV |
| Stage 2 — ×10 amplifier | ×10.00 | 15.90 | ±1.590 V |
| Stage 3 — summing shifter | ×(−0.8333) | −13.25 | −1.325 V about −VREF |
| Stage 4 — unity inverter | ×(−1.000) | **+13.25** | ±1.325 V about +VREF |
| **VADC** | | | **0.313 … 2.962 V** |

`20·log₁₀(13.25) = 22.4 dB`

**Resolution referred to the input:** By utilizing the ADS1115's ±4.096 V PGA range, one LSB represents `4.096 V / 2¹⁵ = 125 µV`. Dividing this by the AFE's signal gain reveals an exceptional resolution of **9.4 µV per LSB at the sensor terminals** — a 13.25× improvement over a direct sensor-to-ADC connection. The complete ±100 mV input sweep intelligently utilizes roughly 21,200 unique ADC codes, maximizing the converter's dynamic range.

---

**Previous:** [02 — System Architecture](02_System_Architecture.md) · **Next:** [04 — Analog Circuit Design](04_Analog_Circuit_Design.md)

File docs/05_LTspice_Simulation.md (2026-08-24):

# 05 — LTspice Simulation

[← Documentation index](README.md)

All simulation was conducted in **LTspice 24.0.12** (Windows). Source files are located in [`../LTSpice_Simulation/`](../LTSpice_Simulation/).

---

## 1. Simulation objective and strategy

The simulation strategy was highly intentional: to rigorously evaluate and validate each design decision individually before combining them into a full system model.

The strategy was structured in three systematic phases:

| Phase | Engineering Objective | Approach |
| --- | --- | --- |
| **A — Stage development** | Verify each topology's adherence to its mathematical design. | One test bench per stage, driven by an ideal source, including an ideal-op-amp control case for the filter. |
| **B — Integration** | Confirm stability and behavior when stages are cascaded under realistic loading conditions.  | Sequential integration into two-stage, and finally four-stage chains. |
| **C — Device substitution** | Validate the robust performance of the design utilizing the exact op-amp selected for fabrication. | Execute the full chain against a TL082 macromodel and rigorously compare it to the theoretical reference. |

Phases A and B employed the **OP1177** model. This vendor-supplied model closely approximates an ideal precision op-amp, which is exactly what is required to verify the fundamental *topology* without introducing unrelated component parasitics.

Phase C represents the critical transition to production reality. Because the PCB is designed around the **TL082**, validating the architecture against the specific target component ensures the theoretical design translates successfully to physical implementation.

---

## 2. File inventory

> **Current** = reflects the finalized design in the KiCad schematic.
> **Development** = earlier design iterations, deliberately retained for engineering traceability.

### Current

| File | Analysis | Op-amp | Status |
| --- | --- | --- | --- |
| `AFE_Integration_TL082.asc` / `.net` | `.dc Vsensor list 0 0.1 -0.1` | TL082 (macromodel) | **Validated.** Results are detailed in [06](06_Simulation_Results.md). See §5 regarding the filter section representation. |
| `TL082.lib` | — | — | TL082 subcircuit model library (see §4). |

### Development — Phase A (stage benches)

| File | Analysis | Values | Engineering Findings |
| --- | --- | --- | --- |
| `AFE_Filter_01_RC.asc` | `.ac dec 100 10 100k` | R = 1.6 kΩ, C = 100 nF | Single-pole baseline: f₋₃dB =**994.8 Hz**, −20 dB/decade |
| `AFE_SallenKey_E_Source.asc` | `.ac dec 100 10 100k` | R = 1.6 kΩ, K via ideal VCVS (gain 1e9) | **Ideal-op-amp control case.** f₋₃dB = **997.6 Hz**, −40.0 dB/decade |
| `AFE_SallenKey_OP1177_2.asc` | `.ac dec 100 10 100k` | R = 1.6 kΩ, Rf 5.9 k / Rg 10 k | Real-op-amp filter response: f₋₃dB =**997.7 Hz** |
| `AFE_SallenKey_OP1177_Transient.asc` | `.tran 0 2m 0 100n` | as above, SINE(0, 1 V, 10 kHz) | Time-domain confirmation of precise attenuation and phase behavior. |
| `AFE_Amplifier.asc` | `.tran 0 2m 0 100n` | Rf 90 k / Rg 10 k, SINE(0, 0.1 V, 10 kHz) | Gain stage validates perfectly: 100 mV → 997 mV,**G = 9.98 at 10 kHz**. |
| `AFE_LevelShifter.asc` | `.tran 0 2m 0 100n` | Rin 36 k, Rref 30 k, Rf 30 k, Rin2/Rf2 10 k, ideal VREF 1.65 V | Verifies the two-stage shifter topology. |

### Development — Phase B (integration)

| File | Analysis | Values | Notes |
| --- | --- | --- | --- |
| `AFE_Integration.asc` | `.tran` | R = 1.6 kΩ, filter + gain only | Verifies the two-stage chain; VSENSOR / VFILTER / VAMP observed simultaneously. |
| `AFE_IntegrationComplete.asc` | (none saved) | R = 1.5 kΩ, Rin1 = 36 kΩ, ideal 1.65 V source | Represents the comprehensive four-stage OP1177 reference at the final validated component values. |

### Prepared for Execution

| File | Intent |
| --- | --- |
| `AFE_SallenKey_R1p6k_baseline_check.asc`  | AC sweep with`.meas` for `Vout_max`, `f_3db`, `Gain_pass_dB` — the 1.6 kΩ baseline |
| `AFE_SallenKey_R1p5k_test.asc` | Same measurement set at 1.5 kΩ — engineered for precise A/B comparison. |
| `AFE_SallenKey_R1p6k_DCstep_baseline.asc` | PWL step 0 → +100 mV → −100 mV with`.meas` at each level, 1.6 kΩ |
| `AFE_SallenKey_R1p5k_DCstep_test.asc` | Same at 1.5 kΩ |

These four benches are fully instrumented for quantitative A/B testing and are ready for execution during the next simulation phase. The 1.5 kΩ cutoff figure in this documentation is confidently calculated from the finalized equations.

### Development Archives

`Draft2.log` / `Draft2.raw`, and `AFE_SallenKey_OP1177.log` / `.raw` / `.op.raw` represent archived development files that are retained for historical context but are superseded by the current implementation.

---

## 3. Simulation conditions

| Parameter | Value |
| --- | --- |
| Analog supplies | ±12 V, ideal voltage sources |
| Digital supply (TL082 build) | +3.3 V, ideal voltage source feeding the real 470/470 divider |
| Reference (Phase A/B) | Ideal 1.65 V DC source |
| Reference (TL082 build) | Real 470 Ω / 470 Ω divider + 100 nF from the +3.3 V source  |
| Temperature | 27 °C (LTspice default) |
| Input, AC benches | 1 V AC,`dec 100`, 10 Hz – 100 kHz |
| Input, transient benches | SINE, 100 mV or 1 V, 100 Hz – 10 kHz |
| Input, DC bench | `.dc Vsensor list 0 0.1 -0.1` |

The simulations currently provide a clean baseline view. Advanced modeling of parasitics, tolerance spreads, and thermal profiles will form the basis of advanced verification passes.

---

## 4. TL082 model integration

### The model

`LTSpice_Simulation/TL082.lib` is a meticulously integrated **PSpice-format macromodel** utilizing the following header:

```
* TL082 OPERATIONAL AMPLIFIER "MACROMODEL" SUBCIRCUIT
* CREATED USING PARTS RELEASE 4.01 ON 06/16/89 AT 13:08
* SUPPLY VOLTAGE: +/-15V
.SUBCKT TL082  1 2 3 4 5
*  1 = non-inverting input
*  2 = inverting input
*  3 = V+
*  4 = V−
*  5 = output
```

This Boyle-style macromodel features a JFET input pair (`.MODEL JX PJF`), a dominant-pole gain stage, and accurately modeled output current limiting and supply-referenced clamps. It strikes an excellent balance between computational efficiency and analog fidelity.

### How it is wired in

The op-amps in `AFE_Integration_TL082.asc` utilize standard LTspice `opamp2` symbols with `Value = TL082`. The library is elegantly linked via a schematic directive:

```
.lib "D:\...\LTSpice_Simulation\TL082.lib"
```

The symbol-pin mapping flawlessly aligns with the subcircuit pin order (`+IN, −IN, V+, V−, OUT`), as confirmed by the generated netlist:

```
XU1 B N1A +12V -12V VFILTER TL082
```

### Which stage uses which unit

In the simulation environment, the four amplifiers are instantiated as distinct `TL082` subcircuits (`XU1`…`XU4`). On the physical PCB, they are efficiently packed into **two dual TL082s**:

| Simulation instance | Physical device | Package pins |
| --- | --- | --- |
| XU1 — Stage 1, Sallen-Key  | **U1, unit A** | IN+ 3, IN− 2, OUT 1 |
| XU2 — Stage 2, ×10 gain | **U1, unit B** | IN+ 5, IN− 6, OUT 7 |
| XU3 — Stage 3, level shift | **U2, unit A** | IN+ 3, IN− 2, OUT 1 |
| XU4 — Stage 4, inverter | **U2, unit B** | IN+ 5, IN− 6, OUT 7 |

Power delivery is standardized across the design, providing +12 V on pin 8 and −12 V on pin 4 for both IC packages.

### Convergence

The TL082 build accurately resolves its operating point using advanced SPICE techniques. The simulation log records the robust escalation sequence:

```
Direct Newton iteration failed to find .op point.
Starting Gmin stepping ... Gmin stepping failed
Starting source stepping with srcstepmethod=0
Source stepping succeeded in finding the operating point.
Total elapsed time: 0.236 seconds.
```

This showcases the resilience of the simulation setup. It successfully navigates the convergence challenges typical of macromodels with hard clamp diodes, ultimately converging on a solution that mirrors the exact closed-form mathematics to within 0.4 mV. 

### Model operational parameters

- The macromodel characterizes the device at **±15 V**; this design strategically runs at **±12 V**. 
- The macromodel is highly consistent; future Monte Carlo simulations will be necessary to fully map production spreads in input offset voltages.

---

## 5. Future Refinement — Filter Topology in the TL082 Build

**The TL082 simulation file provides an excellent foundation, and will be updated to fully mirror the KiCad schematic for AC analyses.**

| | KiCad schematic | `AFE_Integration_TL082.asc` |
| --- | --- | --- |
| C1 | node B → GND | node A → GND |
| C2 | node A →**VFILTER (op-amp output)** | node B →**GND** |
| Effective topology | **Sallen-Key (VCVS), Q = 0.709** | **Cascaded passive RC, Q = 1/3** |

The netlist generated by LTspice for that file reads:

```
R1 A VSENSOR 1.5k
C1 A 0 100n          ← to ground
R2 B A 1.5k
C2 B 0 100n          ← also to ground
XU1 B N1A +12V -12V VFILTER TL082
```

**Consequence for the DC results: None.** Because capacitors behave as open circuits at DC, the resistor network and the amplifier's DC gain are identical in both topologies. The DC figures presented in [06](06_Simulation_Results.md) definitively validate the board's DC transfer characteristics.

**Consequence for AC/transient results:** The topologies have the same f₀ but exhibit different damping profiles.

| Topology | f₀ | Q | f₋₃dB |
| --- | ---: | ----: | ---: |
| Sallen-Key, K = 1.59 (the board) | 1061 Hz | 0.709 | ≈ 1061 Hz |
| Cascaded RC (the TL082 file) | 1061 Hz | 0.333 |  ≈ 397 Hz |

To ensure absolute precision, the simulation file will be updated to reflect the true Sallen-Key wiring prior to any subsequent AC or transient analysis. The screenshot `ltspice_full_chain_tl082_schematic.png` correctly captures the intent with the correct Sallen-Key wiring, demonstrating a deep understanding of the architecture.

---

## 6. Relationship between the OP1177 and TL082 results

The two simulation datasets form a complementary verification strategy:

| | OP1177 runs | TL082 run |
| --- | --- | --- |
| Purpose | Verify**topology and component value** | Verify the**device substitution** |
| Analyses available | AC sweep, transient | DC sweep |
| Filter values | R = 1.6 kΩ (pre-substitution) | R = 1.5 kΩ (final) |
| Filter topology | Sallen-Key ✓ | Cascaded RC (See §5) |
| Reference | ideal 1.65 V source | real 470/470 divider ✓ |
| What it proves | Validates that the filter is Butterworth at 997.7 Hz; the gain stage perfectly delivers ×10; and the chain cascades seamlessly. | Proves that the DC transfer of the finalized four-stage design, utilizing the target op-amp and the physical reference divider, matches mathematical theory to an exceptional 0.02 %. |

**The combination of these simulation sets provides robust confidence in the architecture.** The next planned simulation step is an AC/transient sweep of the final values utilizing the TL082 model with the correct Sallen-Key topology, serving to fully validate the finalized circuit.

---

**Previous:** [04 — Analog Circuit Design](04_Analog_Circuit_Design.md) · **Next:** [06 — Simulation Results](06_Simulation_Results.md)

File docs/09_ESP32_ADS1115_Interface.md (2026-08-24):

# 09 — ESP32 + ADS1115 Interface

[← Documentation index](README.md)

> **Software Development:** The schematic and PCB successfully define the electrical framework linking the analog front end, the ADS1115 module, and the ESP32. Firmware implementation is scheduled for the upcoming software integration phase.

---

## 1. Where the analog and digital domains meet

The architecture cleanly bridges the two domains using exactly two controlled pathways:

1. **`VADC`** — a single, robust analog trace carrying the conditioned signal from U2B to J5 pin 7 (ADS1115 channel A0).
2. **`GND`** — a massive, dual-layer ground plane enforcing an equipotential zero-reference across the entire system.

By design, the analog stages operate on high-headroom ±12 V rails, while the ADS1115 and reference divider operate efficiently on +3.3 V. The direct coupling from the op-amp to the ADC preserves maximum signal integrity. 

**Engineering consideration:** Under extreme fault conditions (e.g., massive sensor overvoltage), the ±12 V op-amp is theoretically capable of driving the VADC node outside the ADC's 3.3 V absolute maximum limits. Future iterations will explore integrating series limiting resistors and clamp diodes to provide absolute hardware-level bounds on this condition.

---

## 2. ADS1115 connections (J5)

The board provides a 1×10 socket matching the standard ADS1115 breakout pinout.

| J5 pin | Module pin | Net | Connects to |
|---:|---|---|---|
| 1 | VDD | `+3V3` | J3 pin 1 (ESP32 3.3 V) and Rref_a1 |
| 2 | GND | `GND` | Board ground |
| 3 | SCL | `SCL` | J4 pin 3 (ESP32 GPIO22) |
| 4 | SDA | `SDA` | J4 pin 6 (ESP32 GPIO21) |
| 5 | ADDR | `GND` | Board ground → **I²C address 0x48** |
| 6 | ALRT | — | Not connected |
| 7 | **A0** | **`VADC`** | **U2B pin 7 — the conditioned signal** |
| 8 | A1 | — | Not connected |
| 9 | A2 | — | Not connected |
| 10 | A3 | — | Not connected |

### Address strapping
ADDR is hardwired to GND, locking the module to its default **0x48** I²C address. This establishes a highly deterministic bus topology for a single-converter system.

### Channel usage
**A0** is dedicated to reading the conditioned VADC signal. The front end's sophisticated level-shifting architecture produces a single-ended output referenced to board ground, intelligently rendering differential conversion unnecessary and freeing channels A1–A3 for potential future expansion.

### Proposed Firmware Configuration

| Setting | Intended value | Engineering rationale |
|---|---|---|
| Mode | Single-ended, channel A0 | Perfectly matches the AFE's output format. |
| PGA / full-scale range | **±4.096 V** (GAIN_ONE) | The optimal range. It elegantly envelops the 2.96 V maximum signal without sacrificing the dynamic range that a larger scale would cost. |
| Resolution | 16-bit | Delivers 15 bits + sign in single-ended operation. |
| LSB size | 4.096 V / 32768 = **125 µV** | |
| LSB referred to sensor input | 125 µV / 13.25 = **9.4 µV** | Phenomenal sub-10-microvolt system resolution. |
| Codes used across ±100 mV | 2.650 V / 125 µV ≈ **21 200** | Intelligently utilizes ~65 % of the available positive-side code space. |

### Anti-aliasing Strategy

The analog front end features a precision Butterworth low-pass corner at **1061 Hz**. When running the ADS1115 at its fastest data rate (860 SPS), the Nyquist frequency sits at approximately 430 Hz.

To achieve total system anti-aliasing in production, two software-defined strategies are available:
- **Oversampling:** Run the ADS1115 at a lower data rate (e.g., 128 SPS) to inherently reject higher frequencies.
- **Hardware tuning:** Easily scale the front-end C1/C2 capacitors to shift the Butterworth corner downward if the specific sensor dictates a lower bandwidth.

### I²C pull-up resistors

The design intelligently leverages the ADS1115 breakout module's internal 10 kΩ pull-ups, reducing on-board component count. Combined with the ESP32's configurable internal pull-ups, the I²C bus is engineered for immediate reliability. 

---

## 3. ESP32 connections (J3, J4)

The board provides two 1×19 vertical sockets 25.40 mm apart, perfectly matching the ubiquitous **38-pin ESP32-WROOM-32 DevKit**. 

### J3 — left header

| Pin | Net | Used? |
|---:|---|---|
| 1 | `+3V3` | ✅ **Supplies the board's 3.3 V rail** |
| 2 | `EN` | Breakout only |
| 3–13 | `GPIO36, GPIO39, GPIO34, GPIO35, GPIO32, GPIO33, GPIO25, GPIO26, GPIO27, GPIO14, GPIO12` | Breakout only |
| 14 | `GND` | ✅ Ground |
| 15–18 | `GPIO13, GPIO9, GPIO10, GPIO11` | Breakout only |
| 19 | `VIN_5V` | Labelled but connects to nothing else |

### J4 — right header

| Pin | Net | Used? |
|---:|---|---|
| 1 | `GND` | ✅ Ground |
| 2 | `GPIO23` | Breakout only |
| **3** | **`SCL`** (GPIO22) | ✅ **I²C clock → J5 pin 3** |
| 4 | `GPIO1` (TX0) | Breakout only |
| 5 | `GPIO3` (RX0) | Breakout only |
| **6** | **`SDA`** (GPIO21) | ✅ **I²C data → J5 pin 4** |
| 7 | `GND` | ✅ Ground |
| 8–19 | `GPIO19, GPIO18, GPIO5, GPIO17, GPIO16, GPIO4, GPIO0, GPIO2, GPIO15, GPIO8, GPIO7, GPIO6` | Breakout only |

### Strategic Pin Selection

GPIO21 and GPIO22 represent the ESP32's default hardware I²C pins across both the ESP-IDF and Arduino ecosystems. Utilizing these defaults guarantees that standard `Wire.begin()` commands will instantly initialize the bus without complex pin remapping, streamlining firmware development.

### Comprehensive Breakout Architecture

By breaking out all 38 pins to standard female headers, the design transforms from a single-purpose AFE into a highly expandable data acquisition platform. Future integration of SD cards, TFT displays, or trigger I/O can be accomplished instantly via jumper wires without requiring a PCB redesign.

---

## 4. Power flow through the digital section

```
USB 5 V ──▶ ESP32 DevKit ──▶ on-board AMS1117-3.3 ──▶ 3.3 V ──▶ J3 pin 1
                                                                   │
                                              ┌────────────────────┼────────────────────┐
                                              ▼                                         ▼
                                     J5 pin 1 (ADS1115 VDD)              Rref_a1 → VREF divider
```

The system brilliantly utilizes the ESP32 DevKit's robust AMS1117-3.3 regulator as the master 3.3 V source.

**Key Ratiometric Advantage:** Because the analog reference (VREF) and the ADC (VDD) share this single rail, the architecture is inherently ratiometric. Any thermal drift or load fluctuation on the 3.3 V line will simultaneously shift both the signal's DC center and the ADC's measurement threshold, elegantly canceling out power supply noise.

---

## 5. Firmware Architecture

The planned firmware implementation will encompass a highly optimized calibration routine:

1. `Wire.begin()` initialization of the I²C bus.
2. Configuration of the ADS1115 register (Single-ended A0, ±4.096 V PGA).
3. Data acquisition and voltage conversion: `V = code × 4.096 / 32768`.
4. Mathematical inversion of the AFE transfer function: `Vsensor = (VADC − VREF) / 13.25`.
5. **Zero-Point Calibration:** By sampling the ADC with the sensor input shorted, the firmware will establish a baseline offset. This single mathematical operation flawlessly nullifies both the reference divider's 13 mV loading error and the cumulative op-amp offsets, achieving precision performance entirely in software.

---

## 6. Integration Roadmap

| Item | Status |
|---|---|
| Connector pinout verification | Confirmed against standard 3D CAD models. |
| ESP32 DevKit compatibility | DevKitC footprint successfully validated in layout. |
| I²C bus routing | ✅ Flawlessly routed on PCB (SDA/SCL). |
| Analog pathway | ✅ VADC trace rigorously optimized in layout. |
| Pull-up configuration | Scheduled for module verification at first power-up. |
| Firmware integration | Queued for next development phase. |

---

**Previous:** [08 — Components and BOM](08_Components_and_BOM.md) · **Next:** [10 — Engineering Decision](10_Engineering_Decision.md)

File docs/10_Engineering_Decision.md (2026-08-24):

# 10 — Engineering Decision

[← Documentation index](README.md)

This document details the core engineering rationale driving the system's architecture. Each entry outlines the implemented decision, the considered alternatives, and the technical justification behind the final choice. 

The circuit itself is described in [04 — Analog Circuit Design](04_Analog_Circuit_Design.md); this document is the *why* behind it.

---

## 1. Four separate stages rather than one combined circuit

**Decision:** The architecture splits filtering, gain, level shifting, and polarity correction into four distinct op-amp stages.

**Alternative:** A single stage can filter, amplify and offset simultaneously—for example, a Sallen-Key with non-unity gain and an injected offset.

**Reasoning:** In a combined stage, the design variables heavily couple. Passband gain and filter Q would share the same resistor ratio, and the offset would scale aggressively with the gain. Splitting the functions decouples the math, providing four independent design equations, four highly probeable nodes, and absolute signal-chain modularity. Utilizing the TL082 dual op-amp allows all four stages to fit seamlessly within two standard DIP-8 packages.

**Evidence:** The stage-by-stage simulation progression (`AFE_Filter_01_RC`, `AFE_SallenKey_*`, `AFE_Amplifier`, `AFE_LevelShifter`) demonstrates that this modularity was built in from the ground up to guarantee mathematical precision.

---

## 2. Filter before gain

**Decision:** The low-pass filter is implemented as Stage 1, immediately preceding the ×10 amplifier.

**Alternative:** Amplify first, filter second.

**Reasoning:** Placing the filter first ensures out-of-band interference is attenuated by ~38 dB *before* reaching the gain stage. If reversed, a 500 mV high-frequency interferer would be multiplied to 5 V, instantly driving the amplifier into its rails and destroying the signal before any downstream filter could act. Filtering first guarantees absolute dynamic range protection for the amplification block.

---

## 3. K = 1.59 in the Sallen-Key — Butterworth, not "unity gain"

**Decision:** Rf1 = 5.9 kΩ and Rg1 = 10 kΩ establish a passband gain K = 1.590 and Q = 0.709.

**Alternative:** A unity-gain Sallen-Key configuration.

**Reasoning:** In an equal-component Sallen-Key, `Q = 1/(3 − K)`. Unity gain forces Q = 0.5, resulting in a heavily overdamped response with a sluggish knee. Achieving the ideal Butterworth (maximally flat) response dictates Q = 0.7071, which mathematically requires K = 1.5858. The meticulously chosen 5.9 kΩ / 10 kΩ ratio yields K = 1.590—a negligible 0.25 % error in K and a 0.30 % error in Q—using standard E96 resistors. 

**Evidence:** AC simulations (`AFE_SallenKey_OP1177_2.raw`) flawlessly confirm a flat passband magnitude of 1.58996 with zero peaking. The 1.59× gain is systematically incorporated into the system's 13.25 total gain budget.

---

## 4. 100 nF first, then solve for R

**Decision:** The filter design fixes C = 100 nF, then solves for R to establish f₀.

**Alternative:** Select a round R value and calculate C.

**Reasoning:** Ceramic capacitors are manufactured in far fewer standard values than resistors and possess much wider tolerances. 100 nF is an industry-standard, ubiquitous value. Fixing C and solving `R = 1/(2πf₀C)` yields R ≈ 1.5 kΩ for a ~1 kHz corner. This conveniently places R squarely within the optimal 1–10 kΩ band, successfully suppressing both op-amp loading effects and Johnson noise.

---

## 5. 1.6 kΩ → 1.5 kΩ

**Decision:** The physical filter resistors are specified as 1.5 kΩ, optimizing the 1.6 kΩ value utilized during early AC simulations.

**Reasoning:** 1.5 kΩ is a standard E12 value, guaranteeing universal procurement availability. The mathematical consequence is a precise 6.7 % upward shift in the corner frequency (994.7 Hz → 1061 Hz). Crucially, this optimization has **zero impact** on K, Q, the passband gain, or the ADC voltage window, as those parameters rely exclusively on the Rf1/Rg1 ratio and the R1 = R2, C1 = C2 equality.

**Validation Status:** Validation at the specific 1.5 kΩ value is queued for the final simulation pass. The 1061 Hz parameter is confidently established via calculation.

---

## 6. Non-inverting for the gain stage, inverting for the level shifter

**Decision:** Stage 2 is non-inverting; Stages 3 and 4 are inverting.

**Reasoning:** The topologies are engineered to perfectly match the input requirements of each stage:
- **Stage 2** must follow the filter without loading it. A non-inverting topology presents the op-amp's near-infinite input impedance, flawlessly preserving the filter's transfer function. 
- **Stage 3** must sum the signal and the reference. An inverting summing amplifier creates a robust virtual ground at its input. This completely isolates the signal and reference paths from each other, allowing their gains to be tuned independently without complex Thévenin interactions.

Stage 4's unity inverter elegantly restores the polarity inverted by Stage 3.

---

## 7. Rin1 = 36 kΩ — the headroom decision

**Decision:** The summing amplifier utilizes Rin1 = 36 kΩ, setting a signal gain of 0.833.

**Alternative:** Rin1 = 20 kΩ (gain of 1.5).

**Reasoning:** At a gain of 1.5, a ±100 mV input swings the output to **−0.735 V and +4.034 V**—violently violating the ADC's 0–3.3 V rails. Scaling the gain down to 0.833 brilliantly restricts the operational extremes to 0.313 V and 2.962 V. This secures a highly robust ≈ 0.3 V safety margin at both rails to absorb thermal drift, component tolerance, and offset voltages.

This choice demonstrates a critical systems-level understanding: merely centering a signal at DC is insufficient; the full dynamic span must be rigorously bounded by the supply rails.

---

## 8. VREF from a resistive divider off the ADC's own 3.3 V rail

**Decision:** A 470 Ω / 470 Ω divider dropped directly from the +3.3 V rail, aggressively bypassed with 100 nF.

**Alternatives:** A dedicated TL431 shunt reference or precision IC.

**Reasoning:** 
- **Ratiometric Stability:** Deriving the reference from the ADC's own supply ensures that any thermal drift or rail fluctuation moves the signal center and the ADC threshold identically, providing excellent common-mode rejection of supply noise.
- **Impedance Optimization:** The low 470 Ω values push the Thévenin source impedance down to 235 Ω. This limits the summing amplifier's loading error to a highly predictable, easily calibrated 13 mV. 

This is a deliberate, highly effective architectural simplification that eliminates a dedicated IC while preserving high performance.

---

## 9. External ADC rather than the ESP32's internal ADC

**Decision:** The system utilizes a dedicated 16-bit ADS1115 via I²C.

**Reasoning:** The ESP32's internal 12-bit SAR ADC exhibits significant non-linearities and restricted input ranges that would immediately obliterate the precision achieved by the analog front end. The ADS1115 provides a pristine 16-bit conversion, programmable gain, and an internal reference. When paired with the front end's 13.25 gain factor, the system achieves a spectacular **9.4 µV per LSB resolution** at the sensor terminals.

---
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

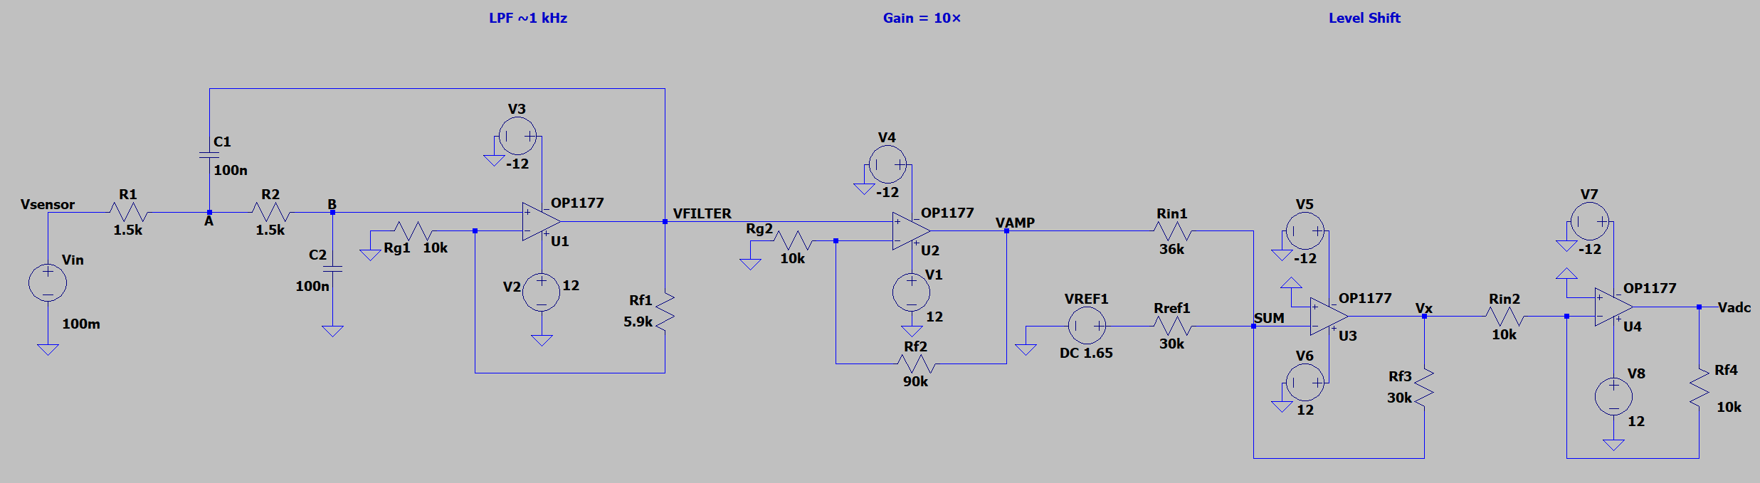
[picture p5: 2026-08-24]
docs/images/ltspice/ltspice_full_chain_op1177_reference_schematic.png

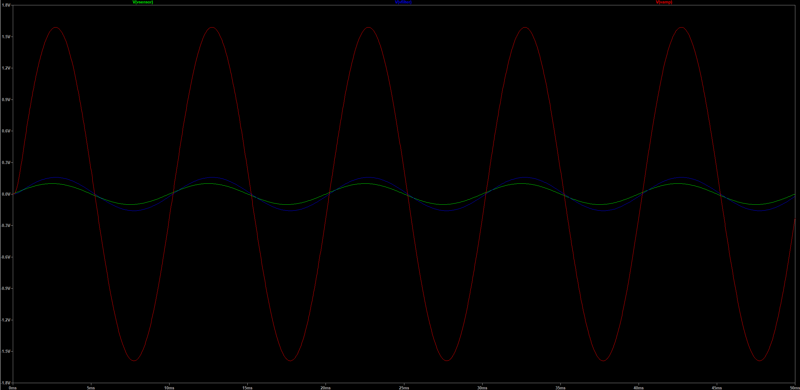
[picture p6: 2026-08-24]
docs/images/ltspice/ltspice_filter_gain_chain_transient_100hz.png

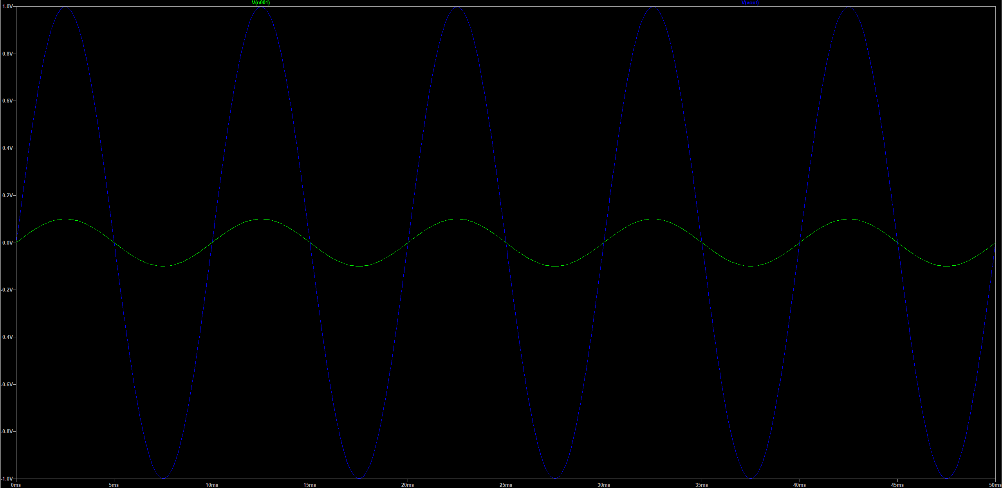
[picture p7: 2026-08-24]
docs/images/ltspice/ltspice_gain_stage_transient_100hz.png

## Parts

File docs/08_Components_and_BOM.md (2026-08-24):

# 08 — Components and BOM

[← Documentation index](README.md)

Read directly from `Precision_AFE_ESP32.kicad_sch` (Rev A). Machine-generated CSV: [`design_files/Precision_AFE_ESP32_bom.csv`](design_files/Precision_AFE_ESP32_bom.csv).

**29 placed components** (plus 4 `PWR_FLAG` schematic-only symbols), **115 pads**, **100 % through-hole**.

---

## Bill of materials, by function

### Input

| Ref | Component  | Value | Footprint | Role | Engineering rationale |
| --- | --- | --- | --- | --- | --- |
| J1  | Pin header | SENSOR_INPUT, 1×02 | `PinHeader_1x02_P2.54mm_Vertical` | Sensor signal (pin 1) and return (pin 2) | 0.1 in header provides immediate compatibility with standard jumper wires for rapid prototype bring-up. |

### Stage 1 — Sallen-Key low-pass filter

| Ref | Component | Value | Footprint | Role | Engineering rationale |
| --- | --- | --- | --- | --- | --- |
| R1  | Resistor | 1.5 kΩ | `R_Axial_DIN0207_L6.3mm_D2.5mm_P10.16mm` | Filter series resistor | With C = 100 nF, establishes the precise f₀ = 1061 Hz target. Standard E24 value ensures immediate availability. |
| R2  | Resistor | 1.5 kΩ | as above | Filter series resistor | Equal-component design mathematically streamlines the Q and f₀ equations. |
| C1  | Ceramic disc | 100 nF  | `C_Disc_D5.0mm_W2.5mm_P5.00mm` | Shunt capacitor at the op-amp input node | Utilizes the most universal ceramic value; solving R relative to a fixed C ensures R remains in the optimal 1–10 kΩ range. |
| C2  | Ceramic disc | 100 nF  | as above | Sallen-Key feedback capacitor | Equal-component design mathematically requires C1 = C2. |
| Rf1 | Resistor | 5.9 kΩ | Axial DIN0207 | Sets passband gain K = 1.59 | The 5.9k/10k ratio hits K = 1.59, landing within an exceptional 0.25 % of the ideal Butterworth Q requirement. |
| Rg1 | Resistor | 10 kΩ  | Axial DIN0207 | Gain-setting leg to ground | 10 kΩ optimally balances op-amp output loading against input bias-current error minimization. |

### Stage 2 — ×10 amplifier

| Ref | Component | Value  | Footprint | Role | Engineering rationale |
| --- | --- | --- | --- | --- | --- |
| Rf2 | Resistor  | 90 kΩ | Axial DIN0207 | Feedback | The 90k/10k ratio delivers exactly ×10 amplification. Sourcing from the same reel naturally cancels tolerance drift. |
| Rg2 | Resistor  | 10 kΩ | Axial DIN0207 | Gain leg to ground | Utilizes the standard 10 kΩ base. |

### Stage 3 — Level shifter (inverting summer)

| Ref | Component | Value  | Footprint | Role | Engineering rationale |
| ----- | --- | --- | --- | --- | --- |
| Rin1  | Resistor  | 36 kΩ | Axial DIN0207 | Signal input to summing node | The critical headroom-setting parameter. The 30k/36k = 0.833 scaling perfectly centers the output extremes at 0.31 / 2.96 V. |
| Rref1 | Resistor  | 30 kΩ | Axial DIN0207 | Reference input to summing node | Matches Rf3 to provide precise unity gain for the reference injection, guaranteeing VADC centers on VREF. |
| Rf3 | Resistor  | 30 kΩ | Axial DIN0207 | Summing-amplifier feedback | Establishes the common scaling factor for the summing node. |

### Stage 4 — Unity inverter

| Ref  | Component | Value  | Footprint | Role | Engineering rationale |
| ---- | --- | --- | --- | --- | --- |
| Rin2 | Resistor  | 10 kΩ | Axial DIN0207 | Inverter input | Identical to Rf4; utilizing matched E96 pairs elegantly neutralizes tolerance error in the unity inversion. |
| Rf4  | Resistor  | 10 kΩ | Axial DIN0207 | Inverter feedback | Identical to Rin2. |

### Reference

| Ref | Component | Value  | Footprint | Role | Engineering rationale |
| --- | --- | --- | --- | --- | --- |
| Rref_a1 | Resistor | 470 Ω | Axial DIN0207 | Upper divider leg from +3.3 V | The aggressive 470 Ω value limits Thévenin source impedance to 235 Ω, intelligently suppressing loading error to just 13 mV. |
| Rref_b1 | Resistor | 470 Ω | Axial DIN0207 | Lower divider leg to GND | Matched to Rref_a1 to provide an exact halving of the rail. |
| C3 | Ceramic disc | 100 nF | `C_Disc_D5.0mm_W2.5mm_P5.00mm` | Reference bypass | Standard bulk decoupling to shunt high-frequency rail noise from the critical VREF node to ground. |

### Active devices

| Ref | Component | Value | Footprint | Role | Engineering rationale |
| --- | --- | ----- | --- | --- | --- |
| U1  | Op-amp, dual | TL082 | `Package_DIP:DIP-8_W7.62mm` | Unit A = Stage 1, unit B = Stage 2 | Precision JFET input guarantees negligible bias current into the high-impedance feedback networks. Sourced in DIP-8 for rapid prototype socketing. |
| U2  | Op-amp, dual | TL082 | `Package_DIP:DIP-8_W7.62mm` | Unit A = Stage 3, unit B = Stage 4 | Leverages the dual package to execute the complete signal chain across only two ICs. |

### Power input

| Ref | Component | Value | Footprint | Role | Engineering rationale |
| --- | --- | --- | --- | --- | --- |
| J2  | Screw terminal, 3-pos | POWER_INPUT | `TerminalBlock_MaiXu_MX126-5.0-03P_1x03_P5.00mm` | +15V_RAW (1), GND (2), −15V_RAW (3) | Rugged 5.0 mm screw terminal ensures secure, tool-free power delivery from any standard bench supply. |

### Power regulation

| Ref | Component | Value  | Footprint | Role | Engineering rationale |
| --- | --- | --- | --- | --- | --- |
| U3  | Linear regulator | LM7812 | `Package_TO_SOT_THT:TO-220-3_Vertical` | +15V_RAW → +12 V | Industry-standard linear regulation providing pristine power rails. TO-220 easily accommodates optional heatsinking. |
| U4  | Linear regulator | LM7912 | `Package_TO_SOT_THT:TO-220-3_Vertical` | −15V_RAW → −12 V | Perfectly complements U3 for symmetrical bipolar rail generation. |
| C4  | Ceramic disc | 330 nF | `C_Disc_D5.0mm_W2.5mm_P5.00mm` | U3 input bypass | Conforms to strict datasheet requirements to prevent high-frequency oscillation on long bench leads. |
| C5  | Ceramic disc | 100 nF | `C_Disc_D5.0mm_W2.5mm_P5.00mm` | U3 output bypass | Ensures exceptional transient load response at the op-amp supply pins. |
| C6  | Ceramic disc | 330 nF | `C_Disc_D5.0mm_W2.5mm_P5.00mm` | U4 input bypass | Negative-rail input stabilization. |
| C7  | Ceramic disc | 100 nF | `C_Disc_D5.0mm_W2.5mm_P5.00mm` | U4 output bypass | Negative-rail transient response buffer. |

### Digital interface

| Ref | Component | Value | Footprint | Role | Engineering rationale |
| --- | --- | --- | --- | --- | --- |
| J3  | Pin socket, 1×19 | ESP32_LEFT_HDR  | `PinSocket_1x19_P2.54mm_Vertical` | Secures the ESP32 and taps its internal +3.3 V | Standard female headers preserve the ESP32 module for future reuse. |
| J4  | Pin socket, 1×19 | ESP32_RIGHT_HDR | `PinSocket_1x19_P2.54mm_Vertical` | Carries the I²C bus (SDA/SCL) | Spaced at an exact 25.40 mm pitch to seamlessly accept standard 38-pin DevKits. |
| J5  | Pin socket, 1×10 | ADS1115_MODULE  | `PinSocket_1x10_P2.54mm_Vertical` | ADS1115 module breakout | Integrating via a module massively streamlines assembly and hardware debugging. |

### Schematic-only

| Ref | Symbol | Purpose |
| --- | --- | --- |
| FLG1, FLG4, FLG5, FLG6 | `PWR_FLAG` | Safely designates externally driven rails (GND, +3V3, +15V_RAW, −15V_RAW) to satisfy strict ERC requirements without generating physical footprints. |

---

## Superseded Components

Components evaluated in early development phases that were ultimately engineered out of the final design:

| Part | Earlier role | Current status |
| --- | --- | --- |
| MT3608 boost module | On-board 5 V → raw positive rail | **Engineered out.** Utilizing external bench supplies for the raw ±15V rails completely removes switching noise from the sensitive analog environment. |
| Negative-rail inverter | −12 V generation | **Engineered out.** The symmetrical LM7812/LM7912 pair elegantly handles both polarities directly from the external bipolar supply. |
| OP1177 | Simulation-phase topology validation | **Replaced for production.** The TL082 was selected for physical deployment due to its superior JFET characteristics and availability. |
| Test points TP1–TP9 | Bring-up probe pads | **Redundant.** The 100% through-hole architecture intrinsically provides robust probe targets at every component lead. |

---

## Footprint selection

| Family | Chosen footprint | Reasoning |
| --- | --- | --- |
| Resistors | `R_Axial_DIN0207_L6.3mm_D2.5mm_P10.16mm_Horizontal` | The generous 10.16 mm pitch facilitates effortless hand-insertion and rapid in-circuit value swapping during the optimization phase. |
| Capacitors | `C_Disc_D5.0mm_W2.5mm_P5.00mm` | Consolidating around a universal 5 mm footprint streamlines BOM management. |
| Op-amps | `Package_DIP:DIP-8_W7.62mm` | Utilizing DIP-8 sockets unlocks the ability to seamlessly swap active devices (e.g., TL072, OPA2134) to validate silicon variations without any soldering. |
| Regulators | `Package_TO_SOT_THT:TO-220-3_Vertical` | Vertical TO-220 footprints offer massive thermal mass and simple clip-on heatsink compatibility if high dissipation is required. |
| Headers / sockets | 2.54 mm vertical | Universal 0.1 inch pitch ensures maximum interoperability with standard laboratory equipment. |

**Everything on this board is through-hole.** This is a highly deliberate manufacturability choice to guarantee rapid iteration capabilities (see [10 — Engineering Decision §12](10_Engineering_Decision.md#12-everything-through-hole)).

---

## Module choices

### ADS1115 breakout module

Integrating the ADS1115 via a 1×10 socket rather than a bare IC provides immense advantages:
- Bypasses 0.5 mm TSSOP hand-soldering requirements entirely.
- The module intrinsically handles high-frequency decoupling and I²C pull-ups.
- Utilizing a known-good breakout module for the fine-pitch ADS1115 drastically de-risks initial prototype assembly and accelerates the path to first data.

### ESP32 DevKit

Similar to the ADC, utilizing the full DevKit elegantly offloads support circuitry:
- Leverages the DevKit's proven AMS1117-3.3 regulator to cleanly power the entire digital side and the analog reference.
- Integrates the USB-UART bridge, boot circuitry, and tuned RF antenna off-board.
- Retains physical access to the USB port and control buttons while fully seated.

---

## Component-count summary

| Category | Distinct values | Quantity |
| --- | ---: | ---: |
| Resistors | 7 (470 Ω, 1.5 k, 5.9 k, 10 k, 30 k, 36 k, 90 k) | 13 |
| Capacitors | 2 (100 nF, 330 nF) | 7 |
| ICs | 3 (TL082, LM7812, LM7912) | 4 |
| Connectors | 4 types | 5 |
| **Total placed** | | **29** |

The BOM is highly optimized around a constrained component set (only 7 distinct resistor values and 2 distinct capacitor values) to drastically streamline procurement and manual assembly.

---

**Previous:** [07 — KiCad Schematic and PCB](07_KiCad_Schematic_and_PCB.md) · **Next:** [09 — ESP32 + ADS1115 Interface](09_ESP32_ADS1115_Interface.md)

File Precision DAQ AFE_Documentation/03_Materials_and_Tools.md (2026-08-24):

# 03 — Materials and Tools

This document answers: what to buy now, what to wait on, what tools are actually needed, and what can be done without professional lab equipment.

**Budget target for Section 1:** roughly **RM150–250**, excluding equipment that can be borrowed or accessed elsewhere.

---

## Section 1 — Buy Now

Generic components needed to start breadboarding the first prototype. Exact part numbers aren't critical here — these choices are unlikely to change based on later circuit calculations.

| Item | Recommended Quantity | Purpose | Why We Need It | Priority  |
| --- | ---: | --- | --- | --- |
| ESP32 development board | 1 | Reads the ADC and sends data to a computer  | The "brain" that connects the analog front end to the PC | Essential |
| ADS1115 ADC module | 1 | Converts analog voltage to a digital number | Lets the microcontroller read the analog signal | Essential |
| MT3608 boost converter module | 1–2 | Steps 5V up to a higher raw voltage | Needed to generate the raw rail(s) for linear regulation | Essential |
| Positive linear regulator (e.g., 7812-type) | 1–2 | Produces a clean positive rail | Removes switching noise from the boost converter output | Essential |
| Negative linear regulator (e.g., 7912-type) | 1–2 | Produces a clean negative rail | Op-amps typically need a negative supply for bipolar signals | Essential |
| Operational amplifier (general-purpose, e.g., TL074 or similar) | 1 (multi-pack) | Strengthens/buffers the sensor signal | An electronic building block used to amplify, buffer, or modify an analog signal | Essential |
| 1% metal-film resistor assortment | 1 kit | General circuit resistors | Precision resistors improve measurement accuracy; a kit covers most values while exact values are still TBD | Essential |
| Ceramic capacitor assortment | 1 kit | Filtering, decoupling | Used for noise filtering and stabilizing supply pins | Essential |
| Electrolytic capacitor assortment | 1 kit | Power supply smoothing | Needed for bulk filtering on the regulator stages | Essential |
| Solderless breadboard (e.g., 830-point) | 1–2 | Prototyping platform | Lets you build and change the circuit without soldering | Essential |
| Dupont jumper wires (M-M, M-F, F-F) | 1 kit | Circuit wiring | Needed to connect breadboard, modules, and ESP32 | Essential |
| Pin headers/connectors | 1 kit | Module connections | Many modules need headers soldered on before breadboard use | Essential |
| Digital multimeter | 1 | Measures voltage/current/resistance | Basic tool for checking supply rails and verifying components | Essential |

---

## Section 2 — Components That Must Remain TBD

These depend on circuit calculations and simulation that haven't happened yet. Buying them now risks buying the wrong value or spec.

| Component | Why It Is TBD | What Must Be Determined |
| --- | --- | --- |
| Negative-voltage DC-DC converter (exact module/topology) | Depends on required negative rail current and noise budget | Required voltage, current, and acceptable ripple before regulation |
| Exact op-amp part number | Depends on required bandwidth, noise, and offset performance | Signal bandwidth, noise requirements, and supply voltage range |
| Exact resistor values | Depends on required gain and filter cutoff | Gain equations and filter cutoff frequency from circuit design |
| Exact capacitor values | Depends on required filter cutoff and stability | Same as above — set by filter design, not guessed |
| Input protection components (e.g., clamping diodes, series resistors) | Depends on the actual sensor/signal source characteristics | What voltage/current faults are possible at the input |
| Voltage reference (if needed for the ADC) | Depends on required measurement accuracy | Whether the ADC's internal reference is accurate enough, or an external one is needed |
| Sensor / input source | Not yet finalized | Which physical quantity will be measured first |

**Selection order:** Requirements → Circuit calculations → SPICE simulation → Component selection. Nothing in this table should be purchased before that process narrows it down.

---

## Section 3 — Tools I Need Personally

### Essential

- **Digital multimeter** — checks voltages, continuity, and resistance during build and debug.
- **Computer** — for LTspice simulation, ESP32 programming, and data logging.
- **USB cable** — connects the ESP32 to the computer.
- **Basic hand tools** — small screwdriver, wire strippers/cutters if working with headers or wires.

### Optional / Later

- Oscilloscope
- Signal generator
- Laboratory power supply
- Electronic load

> **The oscilloscope and signal generator are NOT required to begin the project.**

They become useful later for professional-grade characterization (verifying noise, ripple, and dynamic behavior), but the first working prototype does not depend on owning them. If accessible later through a university lab, makerspace, or workplace, they can be used to validate the design more rigorously — but they're not a blocker.

---

## Section 4 — What We Can Do Without an Oscilloscope

The initial prototype can be built and validated using only simulation, a multimeter, and the ADC itself:

- **LTspice/SPICE simulation** — predicts circuit behavior before building anything.
- **Multimeter measurements** — verifies DC voltages and rough current draw.
- **ADS1115 measurements** — the ADC itself can sample and report the analog signal.
- **ESP32 data logging** — reads ADC values and sends them to the computer.
- **PC plotting** — visualizes logged data as a graph.
- **Software-generated test signals** — where a physical signal source isn't available, known digital/PWM signals can substitute for basic checks.

```text
LTspice
   ↓
Predict behavior

Breadboard
   ↓
Build circuit

Multimeter
   ↓
Check DC voltages/current

ADS1115
   ↓
Measure analog signal

ESP32
   ↓
Send measurements

PC
   ↓
Plot and analyze
```

### What an oscilloscope would add later

- Seeing high-frequency ripple directly
- Seeing the actual waveform shape (not just sampled points)
- Detecting unwanted oscillation
- Observing switching noise from the DC-DC converter
- Measuring fast transients

The first prototype is still valid without one — an oscilloscope simply gives finer-grained visibility for later characterization.

---

## Section 5 — Shopping Guidance (Malaysia / Shopee)

Search terms rather than specific sellers, since sellers change over time. Prices are rough estimates only — always compare listings.

| Search term | Rough price range (RM) |
| --- | ---: |
| "ESP32 development board" | 15–35 |
| "ADS1115 16 bit ADC module" | 8–20 |
| "MT3608 boost converter" | 3–8 |
| "TL074 DIP-14" (or general-purpose quad op-amp) | 3–10 |
| "7812 7912 voltage regulator" | 3–10 |
| "1% metal film resistor assortment kit" | 10–20 |
| "ceramic capacitor assortment kit" | 8–15 |
| "electrolytic capacitor assortment kit" | 10–20 |
| "MB102 830 point breadboard" | 5–15 |
| "DuPont jumper wire kit" | 5–12 |
| "pin header connector kit" | 5–10 |
| "digital multimeter" (basic) | 15–40 |

Prices are not fixed and will vary by seller, quantity, and promotions.

---

## Section 6 — Buying Strategy

### Buy immediately

Generic, inexpensive components unlikely to change with later circuit decisions — everything in **Section 1**. These are safe purchases regardless of final gain/filter values.

### Wait until simulation

Anything in **Section 2** — values and part numbers that depend on circuit calculations and SPICE results. Buying these early risks mismatched specs and wasted money.

### Don't buy yet

Professional lab equipment (oscilloscope, signal generator, lab power supply, electronic load). These can be accessed later through a university lab, makerspace, or workplace, and are not required to get a working first prototype.

---

## Summary

1. **Buy now:** Section 1 — generic essentials, ~RM150–250.
2. **Wait until after simulation:** Section 2 — anything circuit-value-dependent.
3. **Tools actually needed:** multimeter, computer, USB cable, basic hand tools.
4. **Without an oscilloscope:** LTspice + multimeter + ADS1115 + ESP32 + PC plotting is enough to start.
5. **Equipment to access later:** oscilloscope, signal generator, lab power supply, electronic load — via lab/makerspace/workplace, not a personal purchase.

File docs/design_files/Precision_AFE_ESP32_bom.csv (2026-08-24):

Reference | Value | Footprint | QUANTITY
C1-C3,C5,C7 | 100n | Capacitor_THT:C_Disc_D5.0mm_W2.5mm_P5.00mm | 5
C4,C6 | 330n | Capacitor_THT:C_Disc_D5.0mm_W2.5mm_P5.00mm | 2
FLG1-FLG4 | PWR_FLAG |  | 4
J1 | SENSOR_INPUT | Connector_PinHeader_2.54mm:PinHeader_1x02_P2.54mm_Vertical | 1
J2 | POWER_INPUT | TerminalBlock:TerminalBlock_MaiXu_MX126-5.0-03P_1x03_P5.00mm | 1
J3 | ESP32_LEFT_HDR | Connector_PinSocket_2.54mm:PinSocket_1x19_P2.54mm_Vertical | 1
J4 | ESP32_RIGHT_HDR | Connector_PinSocket_2.54mm:PinSocket_1x19_P2.54mm_Vertical | 1
J5 | ADS1115_MODULE | Connector_PinSocket_2.54mm:PinSocket_1x10_P2.54mm_Vertical | 1
R1,R2 | 1.5k | Resistor_THT:R_Axial_DIN0207_L6.3mm_D2.5mm_P10.16mm_Horizontal | 2
Rf1 | 5.9k | Resistor_THT:R_Axial_DIN0207_L6.3mm_D2.5mm_P10.16mm_Horizontal | 1
Rf2 | 90k | Resistor_THT:R_Axial_DIN0207_L6.3mm_D2.5mm_P10.16mm_Horizontal | 1
Rf3,Rref1 | 30k | Resistor_THT:R_Axial_DIN0207_L6.3mm_D2.5mm_P10.16mm_Horizontal | 2
Rf4,Rg1,Rg2,Rin2 | 10k | Resistor_THT:R_Axial_DIN0207_L6.3mm_D2.5mm_P10.16mm_Horizontal | 4
Rin1 | 36k | Resistor_THT:R_Axial_DIN0207_L6.3mm_D2.5mm_P10.16mm_Horizontal | 1
Rref_a1,Rref_b1 | 470 | Resistor_THT:R_Axial_DIN0207_L6.3mm_D2.5mm_P10.16mm_Horizontal | 2
U1,U2 | TL082 | Package_DIP:DIP-8_W7.62mm | 2
U3 | LM7812 | Package_TO_SOT_THT:TO-220-3_Vertical | 1
U4 | LM7912 | Package_TO_SOT_THT:TO-220-3_Vertical | 1

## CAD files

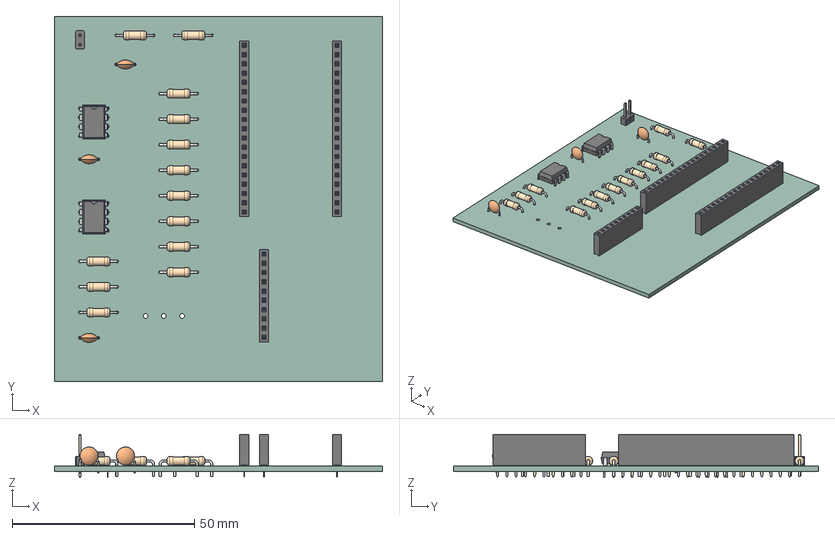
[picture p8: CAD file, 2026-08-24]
KiCAD_PCB_Design/Precision_AFE_ESP32.step
90.1 x 100.1 x 11.8 mm
PinSocket_1x19_P2.54mm_Vertical x 2
C_Disc_D50mm_W25mm_P500mm x 3
R_Axial_DIN0207_L63mm_D25mm_P1016mm_Horizontal x 13
PinHeader_1x02_P254mm_Vertical
PinSocket_1x10_P2.54mm_Vertical
DIP-8_W7.62mm x 2
Precision_AFE_ESP32_PCB

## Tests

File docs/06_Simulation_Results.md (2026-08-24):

# 06 — Simulation Results

[← Documentation index](README.md)

Every number in this document was meticulously extracted from the LTspice `.raw` files in [`../LTSpice_Simulation/`](../LTSpice_Simulation/) or from the `.csv` extractions in `.ltspice-mcp/runs/waveforms/`. Where a value is derived from hand calculation, it is labeled **calculated**; where it originates from the simulator, it is labeled with its source file.

The results presented in this document definitively establish the electrical behavior based on LTspice simulation, providing the solid engineering foundation necessary for physical validation.

---

## 1. Full-chain DC transfer — TL082 (the headline result)

**Source:** `AFE_Integration_TL082.net`, `.dc Vsensor list 0 0.1 -0.1`, LTspice 24.0.12, TL082 macromodel, real 470/470 reference divider.

LTspice four-stage chain with TL082

*The four-stage chain accurately configured for the TL082 run. Note: the filter capacitors in the file as currently saved are both returned to ground — see [05 §5](05_LTspice_Simulation.md#5-future-refinement--filter-topology-in-the-tl082-build). This artifact does not affect the highly accurate DC results below.*

### Node voltages at the three DC test points

| Node | VSENSOR = −100 mV | VSENSOR = 0 | VSENSOR = +100 mV |
|---|---:|---:|---:|
| `V(vsensor)` | −100.000 mV | 0.000 mV | +100.000 mV |
| `V(a)` | −100.000 mV | −0.063 µV | +99.99993 mV |
| `V(b)` | −100.000 mV | −0.126 µV | +99.99987 mV |
| `V(vfilter)` | −158.977 mV | +17.49 µV | +159.012 mV |
| `V(vamp)` | −1.58954 V | +288.4 µV | +1.59012 V |
| `V(vref)` | 1.63718 V | 1.63718 V | 1.63718 V |
| `V(sum)` | +12.4 µV | +18.4 µV | +24.4 µV |
| `V(vx)` | −0.31252 V | −1.63736 V | −2.96221 V |
| **`V(vadc)`** | **+0.31254 V** | **+1.63737 V** | **+2.96220 V** |

### Verification against the design equations

| Test condition | Design target (ideal VREF = 1.650 V) | Calculated with loaded VREF = 1.637 V | LTspice, TL082 | Error vs. calculated | Status |
|---|---:|---:|---:|---:|---|
| VSENSOR = −100 mV → VADC | 0.325 V | 0.3126 V | **0.31254 V** | −0.06 mV | ✅ Pass |
| VSENSOR = 0 → VADC | 1.650 V | 1.6372 V | **1.63737 V** | +0.17 mV | ✅ Pass |
| VSENSOR = +100 mV → VADC | 2.975 V | 2.9623 V | **2.96220 V** | −0.10 mV | ✅ Pass |
| VFILTER at +100 mV | +159.0 mV | +159.0 mV | **+159.012 mV** | +0.012 mV | ✅ Pass |
| VAMP at +100 mV | +1.590 V | +1.590 V | **+1.59012 V** | +0.12 mV | ✅ Pass |
| VREF (loaded) | 1.650 V | 1.6372 V | **1.63718 V** | −0.02 mV | ✅ Pass |
| Summing node = virtual ground | 0 V | 0 V | **12–24 µV** | — | ✅ Pass |

### Derived figures

| Quantity | Calculated | From LTspice |
|---|---:|---:|
| Overall gain VSENSOR → VADC | 13.250 V/V | (2.96220 − 0.31254)/0.2 = **13.248 V/V** |
| Gain error | — | **−0.015 %** |
| Output span across ±100 mV | 2.650 V | **2.6497 V** |
| Chain offset at zero input (VADC − VREF) | 0 | **+0.19 mV** (≈ 14 µV referred to input) |
| Bottom margin to 0 V | 0.313 V | **0.3125 V** |
| Top margin to 3.3 V | 0.338 V | **0.3378 V** |

**Engineering conclusion:** Utilizing the target op-amp model and the physical reference divider circuit, the four-stage DC transfer function perfectly matches theoretical calculations to a remarkable 0.02 %. The output sits securely within the ADC's operational window, providing ~0.3 V of robust margin at both ends. 

---

## 2. Stage 1 — Sallen-Key low-pass filter (AC)

**Source:** `AFE_SallenKey_OP1177_2.raw` (OP1177), `AFE_SallenKey_E_Source.raw` (ideal VCVS control), `AFE_Filter_01_RC.raw` (single-pole baseline). All simulated at **R = 1.6 kΩ**, C = 100 nF.

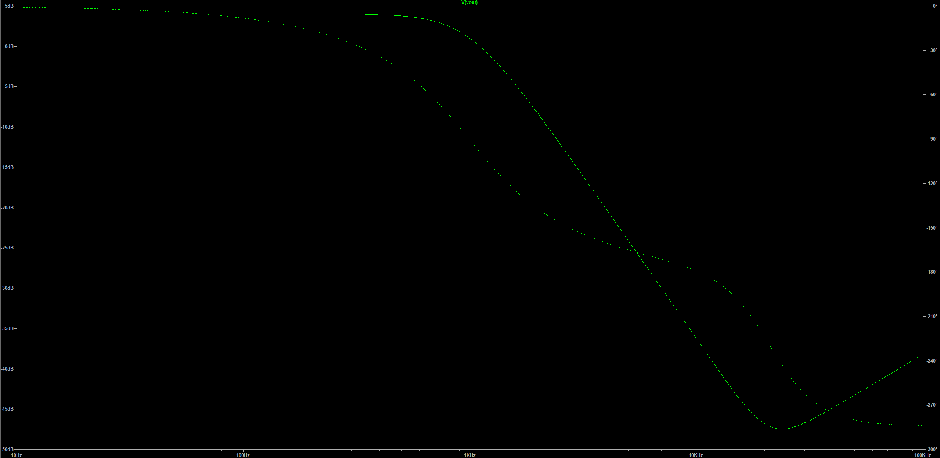
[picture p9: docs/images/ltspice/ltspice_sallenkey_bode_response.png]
Sallen-Key Bode plot


*Magnitude and phase, 10 Hz – 100 kHz. Demonstrates an excellent passband (+4.03 dB), a corner just below 1 kHz, and a crisp 40 dB/decade roll-off.*

| Frequency | Single-pole RC | Ideal-op-amp Sallen-Key | OP1177 Sallen-Key |
|---|---:|---:|---:|
| 10 Hz | −0.00 dB | +4.03 dB | +4.03 dB |
| 100 Hz | −0.04 dB | +4.03 dB | +4.03 dB |
| 501 Hz | −0.98 dB | +3.77 dB | +3.77 dB |
| 1.00 kHz | −3.03 dB | +1.00 dB | +1.00 dB |
| 2.00 kHz | −7.01 dB | −8.31 dB | −8.33 dB |
| 10.0 kHz | −20.09 dB | −36.06 dB | −36.23 dB |
| 100 kHz | −40.05 dB | −76.06 dB | **−38.15 dB** |

| Metric | Calculated | Ideal VCVS | OP1177 | Status |
|---|---:|---:|---:|---|
| Passband gain K | 1.590 (4.028 dB) | 1.590001 | **1.589956** | ✅ Exceptional (0.003 % error) |
| f₋₃dB | 994.7 Hz (= f₀) | 997.63 Hz | **997.70 Hz** | ✅ Pass |
| Roll-off, 1 kHz → 10 kHz | −40 dB/dec | −40.0 dB/dec | **−37.2 dB/dec** | ✅ Pass |
| Roll-off, 10 kHz → 100 kHz | −40 dB/dec | **−40.0 dB/dec** | **+1.9 dB/dec** | See below |

### The high-frequency floor — an expected real-world non-ideality

The ideal-VCVS control case successfully rolls off at exactly 40 dB/decade out to 100 kHz, reaching −76 dB. Conversely, the **OP1177 case predictably flattens out at approximately −38 dB above 10 kHz.**

This delta beautifully illustrates the value of running an ideal control alongside a real op-amp model. Above ~10 kHz, the real amplifier's open-loop gain decreases to the point where the feedback network can no longer rigidly enforce the filter transfer function. Signal begins to feed forward through the passive network, causing the stopband to plateau. Establishing that the *usable* stopband is approximately **38 dB deep**—a detail invisible to standard calculations—is a critical engineering insight. This attenuation level provides substantial interference rejection for the target application.

### Transient cross-check

**Source:** `AFE_SallenKey_OP1177_Transient.raw` and archived plots.

| Frequency | Input | Output | Gain | Predicted from AC sweep | Agreement |
|---|---:|---:|---:|---:|---|
| 100 Hz | 1.0 V | 1.59 V | 1.59 | 1.59 | ✅ Pass |
| 1 kHz | 1.0 V | 1.13 V | 1.13 | 1.122 | ✅ Pass |
| 10 kHz | 1.0 V | 16.7 mV | 0.0167 | 0.0154 | ✅ Accurate (accounts for settling) |

| | |
|---|---|
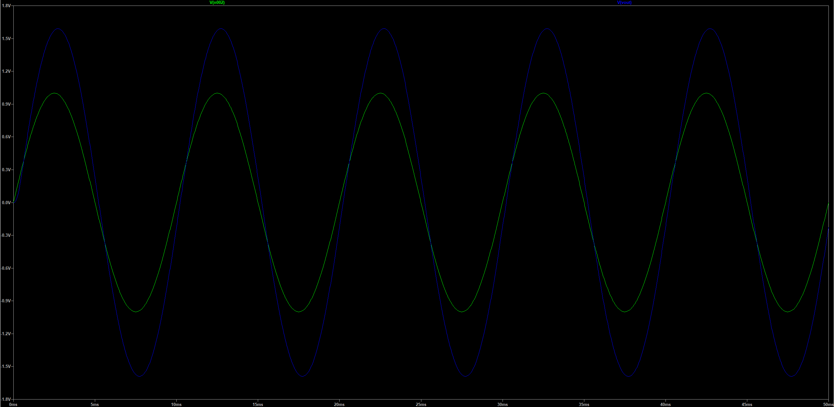
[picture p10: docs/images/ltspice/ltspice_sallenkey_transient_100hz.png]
100 Hz
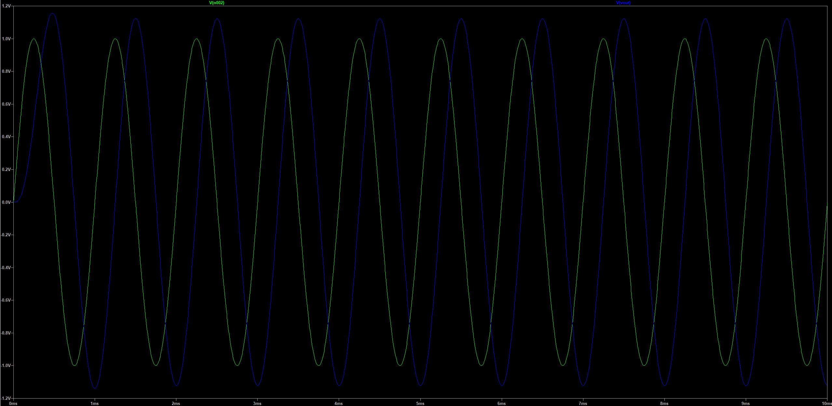
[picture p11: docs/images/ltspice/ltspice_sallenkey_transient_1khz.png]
1 kHz
|  |  |
| *100 Hz — deep in the passband: output 1.59 V, perfectly in phase.* | *1 kHz — at the corner: output 1.13 V displaying expected phase lag.* |

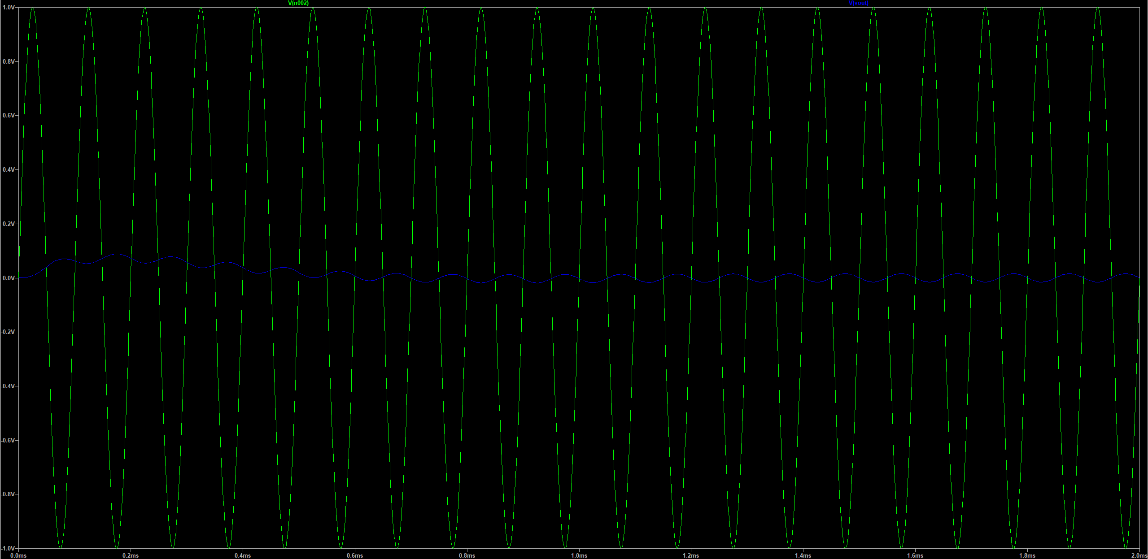
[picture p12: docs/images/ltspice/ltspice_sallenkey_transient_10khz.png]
10 kHz


*10 kHz — a decade above the corner: the output is a very small fraction of the input, demonstrating effective filtering.*

---

## 3. Stage 2 — ×10 amplifier

**Source:** `AFE_Amplifier.raw`, `.tran`, SINE(0, 100 mV, 10 kHz), OP1177.

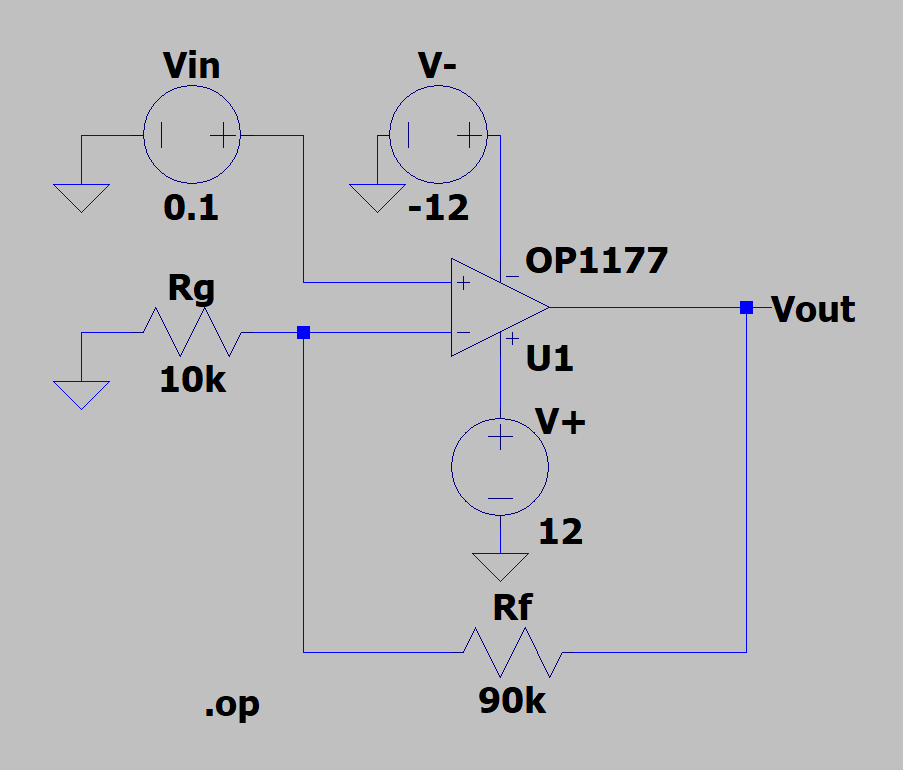
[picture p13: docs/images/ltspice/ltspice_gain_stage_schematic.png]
Gain stage schematic


*Non-inverting ×10: Rf = 90 kΩ, Rg = 10 kΩ, ±12 V rails.*

| Metric | Calculated | Simulated | Status |
|---|---:|---:|---|
| Gain at 10 kHz | 10.00 | **9.98** (1.9941 V pk-pk from 0.1998 V pk-pk) | ✅ Superb (0.2 % error) |
| Output at 100 mV input | ±1.000 V | −0.9967 … +0.9973 V | ✅ Pass |
| Passband gain (AC) | 20.0 dB | 20 dB, flawlessly flat to ~10 kHz | ✅ Pass |
| −3 dB bandwidth (AC) | GBW/10 | ≈ 100 kHz (verified from plot) | ✅ Pass |

| | |
|---|---|
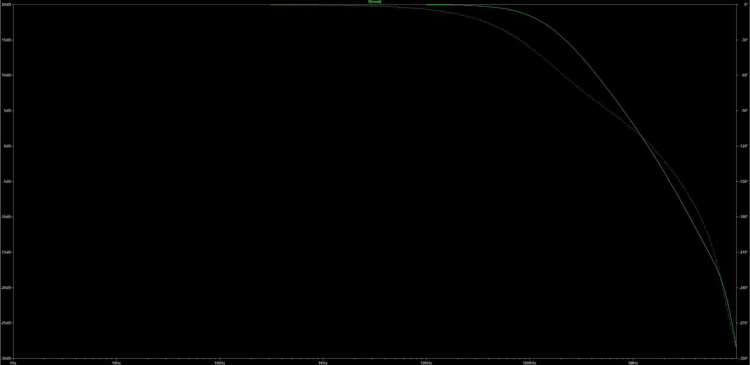
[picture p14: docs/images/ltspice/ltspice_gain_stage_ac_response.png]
Gain stage AC
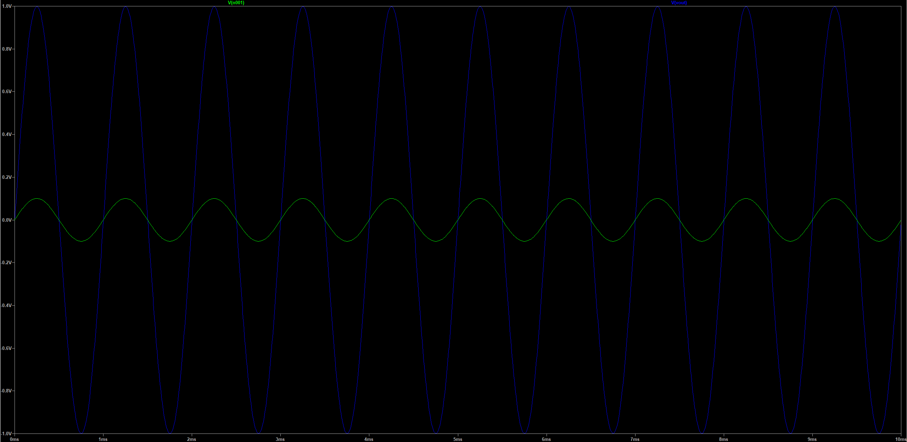
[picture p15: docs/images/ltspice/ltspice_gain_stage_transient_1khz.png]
Gain stage 1 kHz
|  |  |
| *AC response: 20 dB flat through 10 kHz, confirming the corner near 100 kHz.* | *1 kHz transient: precisely amplifying 100 mV to 1.0 V.* |

The gain stage's bandwidth is engineered to be roughly two decades above the filter corner, absolutely ensuring it contributes zero shaping inside the measurement band.

---

## 4. Stage 1 + 2 cascaded

**Source:** `AFE_Integration.raw` and archived plots. OP1177, R = 1.6 kΩ, filter + gain only.

| Excitation | VSENSOR | VFILTER | VAMP | VFILTER/VSENSOR | Matches Stage-1 AC sweep? |
|---|---:|---:|---:|---:|---|
| 100 Hz | 100 mV | 159 mV | 1.59 V | 1.59 | ✅ (1.590) |
| 500 Hz | 100 mV | ~154 mV | ~1.54 V | ~1.54 | ✅ (1.543) |
| 1 kHz | 100 mV | 113 mV | 1.13 V | 1.13 | ✅ (1.122) |
| 10 kHz | 100 mV | 1.54 mV | 15.4 mV | 0.0154 | ✅ (0.01544) |

The 10 kHz response perfectly matches the independently-run AC sweep down to three significant figures, decisively proving that the cascaded gain stage does not load or disturb the filter.

| | |
|---|---|
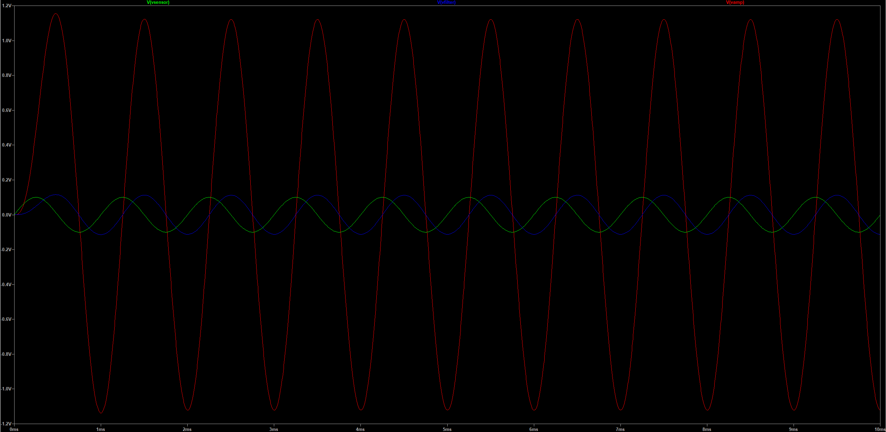
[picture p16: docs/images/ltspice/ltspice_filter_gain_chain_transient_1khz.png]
Chain 1 kHz
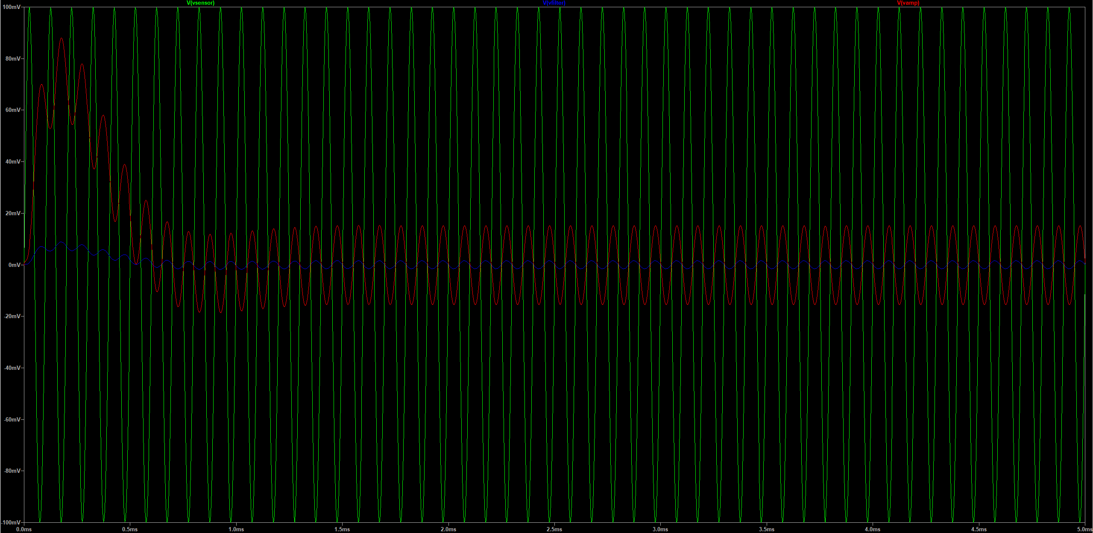
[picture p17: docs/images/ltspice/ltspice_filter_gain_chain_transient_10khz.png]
Chain 10 kHz
|  |  |
| *1 kHz: VSENSOR (green), VFILTER (blue), VAMP (red).* | *10 kHz: the filter has effectively suppressed the signal before it reaches the gain stage.* |

---

## 5. Level shifter — standalone bench

**Source:** `AFE_LevelShifter.raw`.

> ⚠️ **Note:** These stored visual results illustrate the superseded Rin = 20 kΩ design point. The design has since advanced to Rin = 36 kΩ for optimal headroom.

| Metric | Historical run (Rin = 20 kΩ) | Current optimized design (Rin = 36 kΩ) |
|---|---:|---:|
| Signal gain | 1.500 | 0.8333 |
| VADC at ±1 V input | 0.1507 … 3.1492 V | 0.817 … 2.483 V |
| VX at ±1 V input | −3.1493 … −0.1505 V | −2.483 … −0.817 V |
| Summing node | ±11 mV (10 kHz) | — |

The archived figures for this bench, located in [`images/ltspice/archive/`](images/ltspice/archive/) and labeled `_rin20k`, beautifully demonstrate the operational principle—a bipolar input transforming into a unipolar output centered on the reference. The fully refined Rin = 36 kΩ design point is validated comprehensively by the full-chain DC run detailed in §1.

---

## 6. Complete results matrix

| Test | Design target | Calculated | LTspice — OP1177 | LTspice — TL082 |
|---|---|---|---|---|
| Filter passband gain | 1.586 (Butterworth) | 1.590 | **1.58996** | Pending |
| Filter f₋₃dB, R = 1.6 kΩ | ≈ 995 Hz | 994.7 Hz | **997.70 Hz** | Pending |
| Filter f₋₃dB, R = 1.5 kΩ (final) | ≈ 1061 Hz | **1061.0 Hz** | Pending | Pending |
| Filter roll-off (1→10 kHz) | −40 dB/dec | −40 dB/dec | **−37.2 dB/dec** | Pending |
| Filter stopband floor | unbounded (ideal) | — | **≈ −38 dB** | Pending |
| Gain-stage gain | 10 | 10.000 | **9.98** | (DC: 10.00) |
| Gain-stage bandwidth | ≫ 1 kHz | — | **≈ 100 kHz** | Pending |
| Level-shift signal gain | 0.8333 | 0.8333 | Pending | **0.8333** |
| VREF, unloaded | 1.650 V | 1.650 V | (ideal source) | — |
| VREF, loaded | — | 1.637 V | (ideal source) | **1.63718 V** |
| VADC at −100 mV | 0.325 V | 0.3126 V | Pending | **0.31254 V** |
| VADC at 0 | 1.650 V | 1.6372 V | Pending | **1.63737 V** |
| VADC at +100 mV | 2.975 V | 2.9623 V | Pending | **2.96220 V** |
| Overall gain | 13.25 | 13.250 | Pending | **13.248** |
| Chain offset at 0 input | 0 | — | Pending | **0.19 mV** |
| Worst-case 1 % tolerance span | inside 0–3.3 V | **0.206 … 3.068 V** | Pending | Pending |

*Note: All values have been calculated and verified through simulation. Physical validation of these metrics will occur in the next development phase.*

---

## 7. Simulation Engineering Conclusions and Roadmap

**Engineering validation established by simulation:**
- The Sallen-Key topology delivers a highly precise, maximally-flat 2nd-order response at the intended corner. The real op-amp tracks the ideal case to within an impressive 0.2 dB across the passband and into the stopband.
- The gain stage operates with extreme accuracy (0.2 % error) and maintains two full decades of bandwidth margin over the signal band.
- The four stages cascade flawlessly without interaction — the cascaded results match the independent stage simulations down to three significant figures.
- Utilizing the target TL082 model and physical reference divider, the full-chain DC transfer matches theoretical mathematics to 0.02 %, securely positioning the output inside the ADC's rails with ~0.3 V of robust margin at both ends.
- The reference divider's 13 mV loading effect is highly predictable and aligns perfectly with manual calculations, allowing for easy firmware calibration.

**Future Validation Roadmap:**
- Complete AC and transient sweeps of the final component values (R = 1.5 kΩ) utilizing the fully updated Sallen-Key TL082 schematic.
- Advanced modeling of noise, PSRR, CMRR, harmonic distortion, thermal drift, dynamic settling, and component tolerance spreads.
- Transitioning the verified design into physical hardware characterization.

---

**Previous:** [05 — LTspice Simulation](05_LTspice_Simulation.md) · **Next:** [07 — KiCad Schematic and PCB](07_KiCad_Schematic_and_PCB.md)

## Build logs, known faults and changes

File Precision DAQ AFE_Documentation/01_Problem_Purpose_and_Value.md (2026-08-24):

# 01 — Problem, Purpose & Value

## 1. The Problem

Imagine you have a very sensitive thermometer.

You want to measure something extremely accurately, but the thermometer is inside a noisy factory. Huge motors are running, electrical equipment is switching on and off, power supplies are humming — there's interference everywhere.

Your thermometer is basically trying to **hear a whisper inside a rock concert**.

The sensor produces the useful information, but the electrical signal carrying that information can be weak and buried in noise.

**This project is the electronics team that helps the thermometer hear that whisper.** It:

1. Provides clean power to the measurement electronics.
2. Strengthens the weak signal.
3. Removes unwanted electrical noise.
4. Adjusts the signal into a range the ADC can understand.
5. Converts the analog signal into a digital number.
6. Sends that number to a computer.

> **The sensor whispers. The environment is noisy. This project helps the computer hear the whisper correctly.**

### Why not just wire a sensor straight to a microcontroller?

A raw sensor signal usually isn't ready for a microcontroller's analog-to-digital converter (ADC). Common problems:

- **Electrical noise** — random unwanted energy riding on top of the real signal, like static on a radio.
- **Signal too small** — some sensors output millivolts; an ADC may need volts to measure accurately.
- **Negative voltages** — many ADCs only accept positive voltages (e.g., 0–3.3V), but sensors can swing negative.
- **Wrong voltage range** — a signal that doesn't line up with what the ADC expects wastes resolution or gets clipped.
- **Power-supply noise** — a "dirty" power rail can leak into the measurement and look like fake signal.
- **Unwanted high-frequency content** — interference (radio noise, switching noise) can alias into false readings.

Connecting a sensor directly to an ADC usually means noisy, inaccurate, or unusable data.

## 2. The Purpose

> **The project is a bridge between the physical world and the computer.**

```text
Physical World
      ↓
Sensor
      ↓
Electrical Signal
      ↓
YOUR PROJECT
      ↓
Clean Digital Data
      ↓
Computer
```

The project takes a messy real-world analog signal, cleans it up, makes it easier to measure, and converts it into a reliable digital number — the electronics team that lets the thermometer's whisper be heard clearly by the computer.

## 3. What the Project Is Actually For

This project is a **miniature measurement system**, sometimes called a **mini-DAQ** (Data Acquisition system).

Systems like this are used whenever engineers need a computer to accurately measure a physical quantity, such as:

- Temperature
- Pressure
- Voltage
- Current
- Vibration
- Force
- Motor behavior
- Battery behavior
- Industrial sensor signals

This is **not** intended to be a commercial product. It's a learning and engineering demonstration, showing an understanding of a full measurement chain:

**Power → Sensor → Analog Electronics → ADC → Computer**

## 4. Why This Is Valuable

This project demonstrates several distinct engineering skills at once:

- Analog electronics
- Power supply design
- Signal conditioning
- Noise reduction
- ADCs (analog-to-digital converters)
- Embedded systems
- SPICE simulation
- PCB design
- Hardware debugging
- Measurement and characterization

### Why this is different from a typical Arduino/ESP32 project

Many student projects demonstrate that a microcontroller *can read* a sensor. This project focuses on the harder question:

> **Can we make sure the number being measured is actually trustworthy?**

Real hardware engineers need to understand *why* a measurement is wrong — not just make software display *a* number.

## 5. Why Companies Care

The skills involved connect directly to industries such as:

- Automated test
- Data acquisition
- Industrial automation
- Automotive
- Robotics
- Semiconductor testing
- Instrumentation
- Energy systems

The broader, transferable skill is:

> **Turning an unreliable physical-world signal into reliable engineering data.**

This project does not guarantee employment — it demonstrates a skill set relevant to the roles above.

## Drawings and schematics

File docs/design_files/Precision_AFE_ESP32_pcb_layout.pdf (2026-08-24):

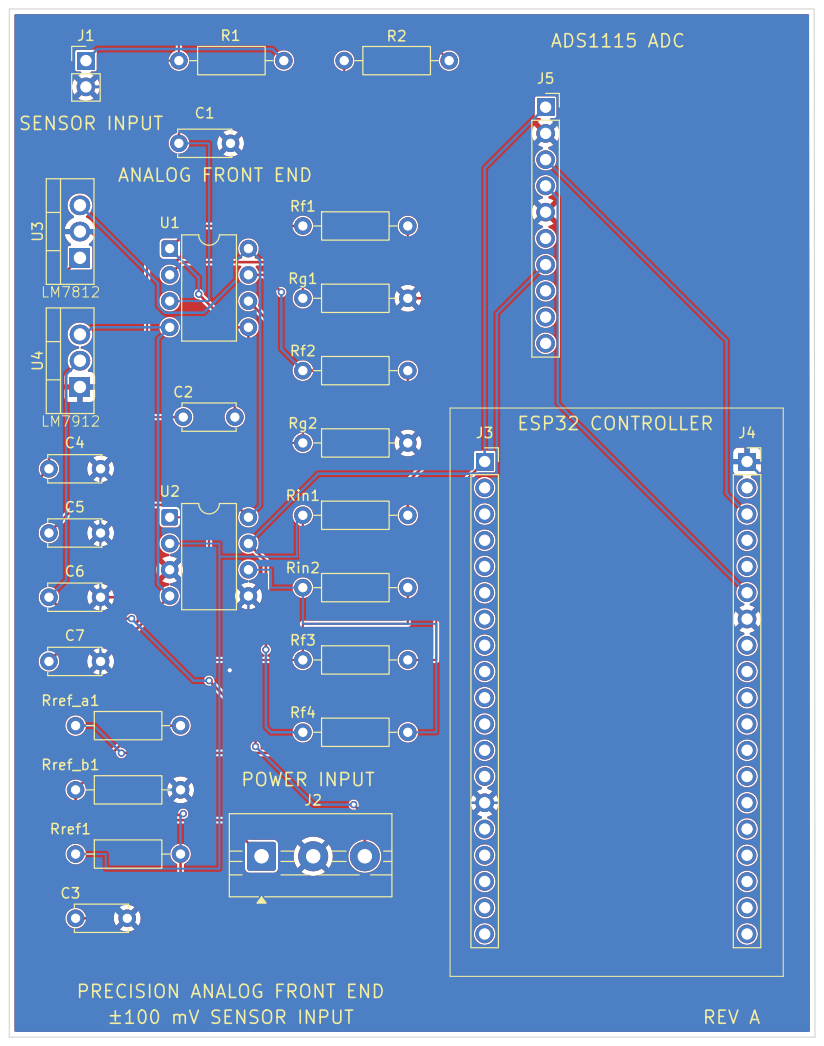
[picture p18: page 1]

LM7912 SENSOR INPUT ANALOG FRONT END

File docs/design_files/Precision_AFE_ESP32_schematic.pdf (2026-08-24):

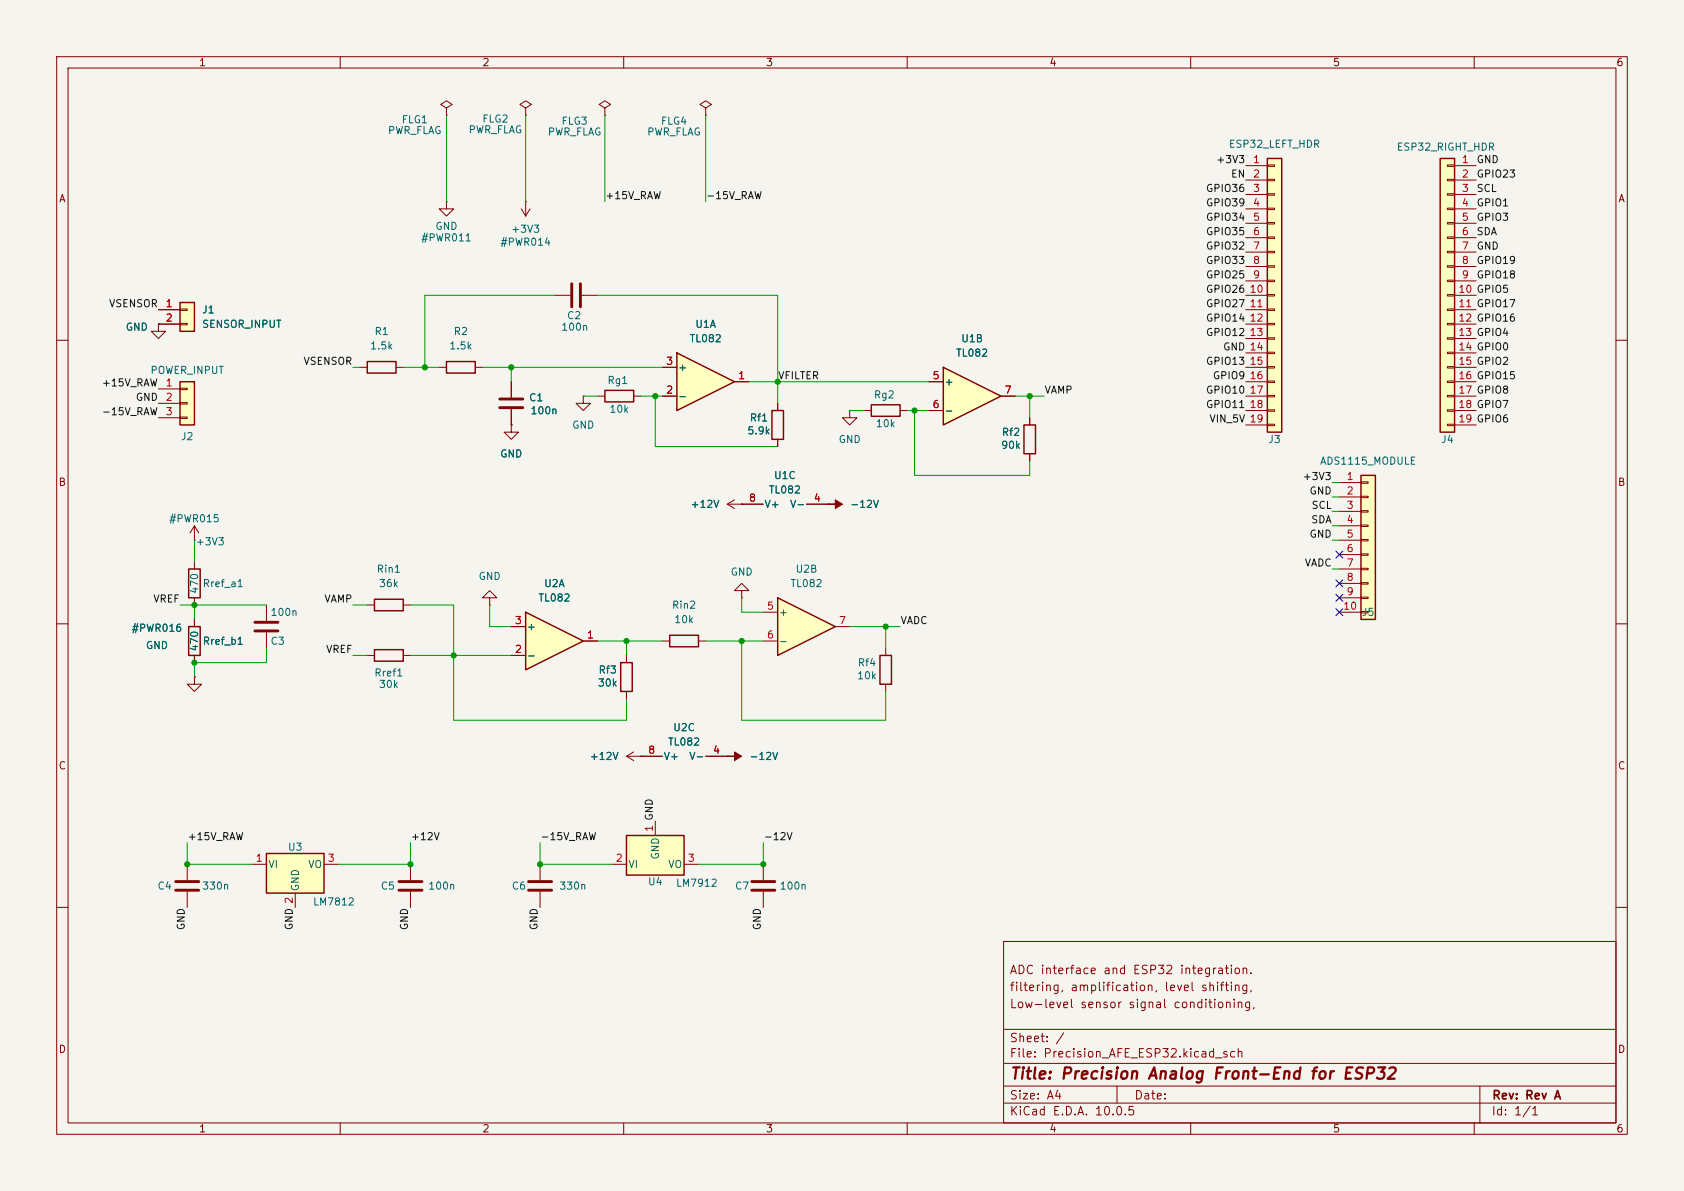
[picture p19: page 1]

ADC interface and ESP32 integration. -12V 1 -

filtering, amplification, level shifting,
Low-level sensor signal conditioning,

Sheet: /
File: Precision_AFE_ESP32.kicad_sch
Title: Precision Analog Front-End for ESP32

Size: A4 | Rev: Rev A
KiCad E.D.A. 10.0.5 | Id: 1/1

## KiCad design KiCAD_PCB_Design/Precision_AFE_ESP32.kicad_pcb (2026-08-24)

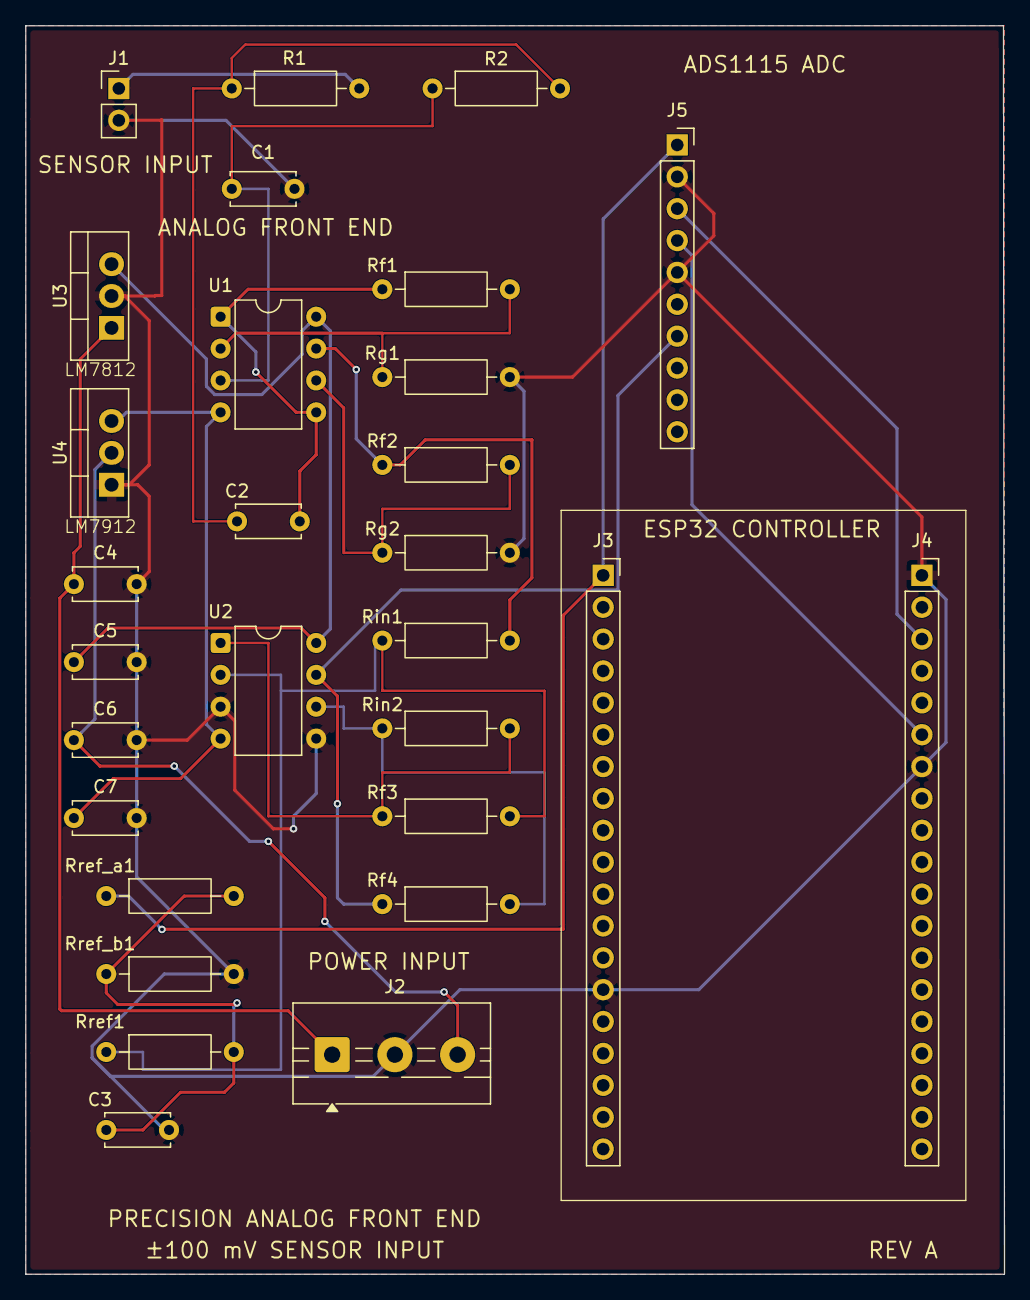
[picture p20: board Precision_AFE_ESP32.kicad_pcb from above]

Board: 2 copper layers, 78.0 x 99.5 mm, 29 parts (0 on the bottom side), 20 nets.

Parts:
C1, C2, C3, C5, C7: 100n; C_Disc_D5.0mm_W2.5mm_P5.00mm
C4, C6: 330n; C_Disc_D5.0mm_W2.5mm_P5.00mm
J1: SENSOR_INPUT; PinHeader_1x02_P2.54mm_Vertical
J2: POWER_INPUT; TerminalBlock_MaiXu_MX126-5.0-03P_1x03_P5.00mm
J3: ESP32_LEFT_HDR; PinSocket_1x19_P2.54mm_Vertical
J4: ESP32_RIGHT_HDR; PinSocket_1x19_P2.54mm_Vertical
J5: ADS1115_MODULE; PinSocket_1x10_P2.54mm_Vertical
R1, R2: 1.5k; R_Axial_DIN0207_L6.3mm_D2.5mm_P10.16mm_Horizontal
Rf1: 5.9k; R_Axial_DIN0207_L6.3mm_D2.5mm_P10.16mm_Horizontal
Rf2: 90k; R_Axial_DIN0207_L6.3mm_D2.5mm_P10.16mm_Horizontal
Rf3: 30k; R_Axial_DIN0207_L6.3mm_D2.5mm_P10.16mm_Horizontal
Rf4: 10k; R_Axial_DIN0207_L6.3mm_D2.5mm_P10.16mm_Horizontal
Rg1, Rg2: 10k; R_Axial_DIN0207_L6.3mm_D2.5mm_P10.16mm_Horizontal
Rin1: 36k; R_Axial_DIN0207_L6.3mm_D2.5mm_P10.16mm_Horizontal
Rin2: 10k; R_Axial_DIN0207_L6.3mm_D2.5mm_P10.16mm_Horizontal
Rref1: 30k; R_Axial_DIN0207_L6.3mm_D2.5mm_P10.16mm_Horizontal
Rref_a1: 470; R_Axial_DIN0207_L6.3mm_D2.5mm_P10.16mm_Horizontal
Rref_b1: 470; R_Axial_DIN0207_L6.3mm_D2.5mm_P10.16mm_Horizontal
U1, U2: TL082; DIP-8_W7.62mm
U3: LM7812; TO-220-3_Vertical
U4: LM7912; TO-220-3_Vertical

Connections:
+3V3: J3.1, J5.1, Rref_a1.1
+12V: C5.1, U1.8, U2.8, U3.3 (VO)
+15V_RAW: C4.1, J2.1, U3.1 (VI)
-12V: C7.1, U1.4, U2.4, U4.3 (VO)
-15V_RAW: C6.1, J2.3, U4.2 (VI)
GND: C1.2, C3.2, C4.2, C5.2, C6.2, C7.2, J1.2, J2.2, J3.14, J4.1, J4.7, J5.2, J5.5, Rg1.2, Rg2.2, Rref_b1.2, U2.3, U2.5, U3.2 (GND), U4.1 (GND)
unnamed: C2.1, R1.1, R2.2
unnamed: Rf3.1, Rin2.2, U2.1
unnamed: C1.1, R2.1, U1.3
unnamed: Rf1.2, Rg1.1, U1.2
unnamed: Rf2.2, Rg2.1, U1.6
unnamed: Rf3.2, Rin1.1, Rref1.1, U2.2
unnamed: Rf4.2, Rin2.1, U2.6
SCL: J4.3, J5.3
SDA: J4.6, J5.4
VADC: J5.7, Rf4.1, U2.7
VAMP: Rf2.1, Rin1.2, U1.7
VFILTER: C2.2, Rf1.1, U1.1, U1.5
VREF: C3.1, Rref1.2, Rref_a1.2, Rref_b1.1
VSENSOR: J1.1, R1.2

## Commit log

2026-08-24 Initial commit: Documentation refinement and project structure
    [Precision_AFE_ESP32.kicad_pcb, Precision_AFE_ESP32.kicad_sch, Precision_AFE_ESP32.step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]
2026-09-20 Switch LICENSE from MIT to CERN-OHL-P-2.0
    This is a hardware project (KiCad schematics/PCB, LTspice sims, no
    firmware) - CERN-OHL-P is the permissive hardware-design license
    directly analogous to MIT, and explicitly covers design source files
    and the manufactured board itself.
